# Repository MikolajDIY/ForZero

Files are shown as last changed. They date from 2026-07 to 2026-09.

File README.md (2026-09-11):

# ForZero

Sterownik fizycznego zestawu wskaźników Audi A4 B6, pozwalający wyświetlać telemetrię z Forza Horizon 6 przy użyciu STM32, CAN, USB i autorskiej aplikacji Qt.

ForZero powstał jako próba wykorzystania fizycznego zestawu wskaźników jako elementu stanowiska simracingowego. Projekt obejmuje rozpoznanie sposobów sterowania licznikiem, zaprojektowanie i uruchomienie własnej PCB, firmware mikrokontrolera oraz aplikację komputerową.

## Film prezentujący projekt

ForZero – prezentacja projektu (https://www.youtube.com/watch?v=puXx0WQHfvw)

[Obejrzyj film na YouTube](https://www.youtube.com/watch?v=puXx0WQHfvw)

## Możliwości

- Wyświetlanie prędkości i obrotów silnika na fizycznym liczniku.
- Sterowanie wskazaniami poziomu paliwa i temperatury płynu chłodzącego.
- Obsługa wybranych kontrolek i komunikatów ostrzegawczych.
- Przybliżona symulacja stanów ABS, TCS i AIRBAG oraz temperatury płynu chłodzącego na podstawie dostępnej telemetrii.
- Odbiór danych UDP z gry i przesyłanie przetworzonych wartości do sterownika przez USB VCP.
- Pomiar opóźnień komunikacji na podstawie potwierdzeń wykonania ramek.
- Zerowanie prędkości i obrotów po 500 ms bez poprawnej ramki danych.

Gra nie udostępnia bezpośrednio wszystkich odwzorowywanych stanów. Algorytmy symulacji kontrolek i temperatury służą do przybliżonego odtworzenia ich zachowania; nie są modelami fizycznymi układów pojazdu.

## Jak to działa

Gra wysyła telemetrię przez UDP. Aplikacja Qt odbiera i parsuje pakiety, wykonuje dodatkową logikę oraz przesyła dane przez USB VCP do STM32F105. Mikrokontroler generuje sygnały elektryczne wymagane przez zestaw wskaźników.

Badany licznik wykorzystuje kilka różnych sposobów sterowania:

| Funkcja | Sposób sterowania |
| --- | --- |
| Obrotomierz | Ramki CAN |
| Prędkościomierz | Sygnał impulsowy o regulowanej częstotliwości |
| Poziom paliwa i temperatura | Emulacja rezystancji czujników |
| Wybrane kontrolki i ostrzeżenia | Sygnały logiczne 12 V |

Wskazania paliwa i temperatury skalibrowano eksperymentalnie. Zmierzone charakterystyki opracowano z wykorzystaniem interpolacji PCHIP w MATLAB-ie.

## Sprzęt

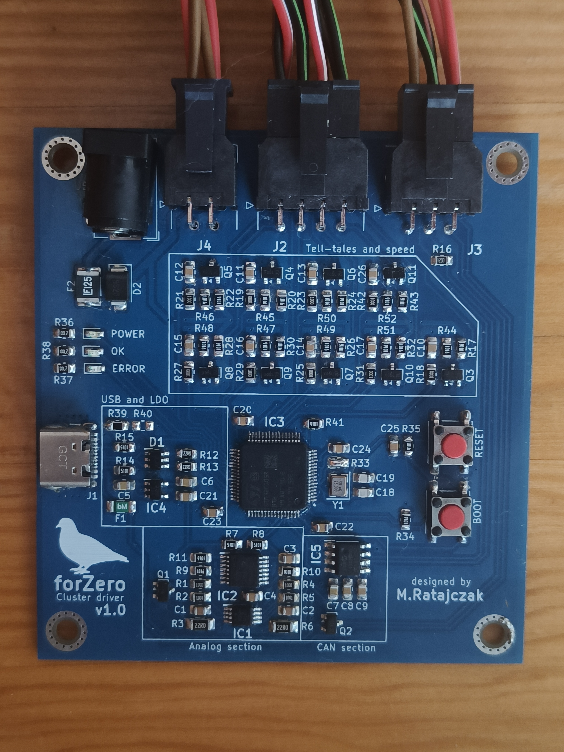
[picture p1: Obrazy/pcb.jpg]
Płytka sterownika ForZero


- Autorska dwuwarstwowa PCB zaprojektowana w KiCad.
- Mikrokontroler STM32F105 z jednoczesną obsługą USB i CAN.
- Transceiver CAN MCP2562 z osobnym zasilaniem interfejsu logicznego.
- Układy emulacji rezystancji oparte na potencjometrze cyfrowym MCP4661, wzmacniaczach operacyjnych i tranzystorach MOSFET.
- Tranzystorowe stopnie sterujące wejściami 12 V licznika.
- Złącze USB-C, zewnętrzne zasilanie 12 V i złącza Molex Micro-Fit 3.0.
- Zabezpieczenie ESD linii USB oraz bezpieczniki polimerowe na liniach zasilania.

## Oprogramowanie

### Aplikacja PC — C++ / Qt

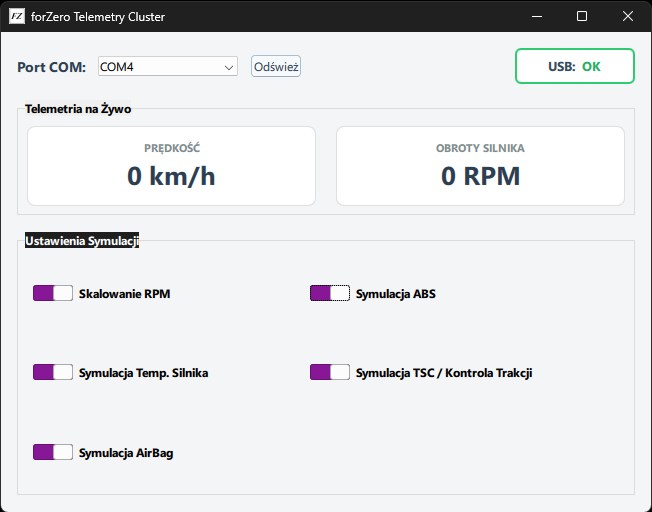
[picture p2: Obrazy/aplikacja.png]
Interfejs aplikacji ForZero


Aplikacja ma trzy wątki: GUI, odbiór UDP oraz komunikację USB. Oddzielenie komunikacji od interfejsu użytkownika pozwala odbierać telemetrię i obsługiwać sterownik bez wykonywania tych operacji w wątku GUI.

Aplikacja odpowiada za parsowanie telemetrii, symulację wybranych wskazań, przygotowanie ramek dla sterownika i wyznaczanie statystyk opóźnień.

### Firmware — C / STM32 HAL

Firmware powstał w STM32CubeIDE z wykorzystaniem bibliotek HAL. Zadania w pętli głównej są wyzwalane zdarzeniowo lub w ustalonych interwałach:

| Sygnał | Aktualizacja |
| --- | --- |
| Prędkość i kontrolki | Po otrzymaniu nowych danych, gdy wartość się zmieni |
| Obroty silnika | Ramka CAN co 20 ms |
| Temperatura | Co 2 s |
| Poziom paliwa | Co 5 s, jeżeli odebrano nowe dane |

Własny protokół przesyłany przez USB VCP wykorzystuje znaczniki ramki, CRC8, numer sekwencyjny i potwierdzenie wykonania `Exec Ack`. Parser posiada timeout odbioru, a brak poprawnych danych przez 500 ms powoduje wyzerowanie prędkości i obrotów.

## Opóźnienia

Aplikacja mierzy czas przejścia danych w pętli PC–sterownik–PC (RTT), wykorzystując numery ramek i odpowiadające im potwierdzenia. Statystyki obejmują ostatnie 20 000 pomiarów.

W zestawach pomiarowych opisanych w dokumentacji średnie RTT zazwyczaj wynosiło poniżej 1 ms, a P99 poniżej 4 ms. W najbardziej skrajnym zarejestrowanym zestawie P99 osiągnął 17 ms. Są to wyniki przeprowadzonych testów, a nie gwarantowane limity czasowe.

**RTT nie jest pomiarem czasu od zdarzenia w grze do mechanicznego wychylenia wskazówki.** Poszczególne wyjścia mają własne okresy odświeżania, a licznik dodatkowo filtruje wskazania. Projekt pracuje jako system soft real-time.

## Zawartość repozytorium

| Folder | Zawartość |
| --- | --- |
| [Aplikacja Qt](Aplikacja%20Qt/) | Kod źródłowy aplikacji komputerowej |
| [Oprogramowanie sterownika](Oprogramowanie%20sterownika/) | Projekt firmware mikrokontrolera STM32 |
| [Schematy](Schematy/) | Materiały dotyczące części sprzętowej |
| [Obrazy](Obrazy/) | Zdjęcia i grafiki wykorzystywane w README |
| [Dokumentacja](ForZero_dokumentacja_v1.pdf) | Szczegółowa dokumentacja projektu |

## Uruchomienie

### Wymagania

- Zestaw wskaźników zgodny z egzemplarzem wykorzystanym w projekcie.
- Zmontowany sterownik ForZero, przewody połączeniowe i zasilanie 12 V.
- Przewód USB obsługujący transmisję danych.
- Komputer z aplikacją ForZero oraz Forza Horizon 6.
- Do samodzielnego zbudowania oprogramowania: środowisko Qt z kompilatorem C++ oraz STM32CubeIDE.

### Kolejność czynności

1. Przy odłączonym zasilaniu połącz sterownik z licznikiem zgodnie ze schematem połączeń w dokumentacji. Uwzględnij numerację pinów obu złączy licznika.
2. Zbuduj firmware z folderu [Oprogramowanie sterownika](Oprogramowanie%20sterownika/) i wgraj go do STM32. Programowanie jest możliwe przez USB z wykorzystaniem wbudowanego bootloadera.
3. Aby wejść w tryb bootloadera: naciśnij RESET, przytrzymując go naciśnij BOOT, zwolnij RESET, a następnie BOOT.
4. Po zaprogramowaniu uruchom sterownik w zwykłym trybie pracy i podłącz zasilanie zestawu.
5. Zbuduj i uruchom aplikację z folderu [Aplikacja Qt](Aplikacja%20Qt/), a następnie wybierz port COM sterownika.
6. Włącz wysyłanie telemetrii UDP w grze. Ustaw adres IP komputera odbierającego dane oraz port zgodny z konfiguracją aplikacji.
7. Uruchom jazdę i sprawdź odbiór danych oraz działanie wskazań.

<!-- Do uzupełnienia przed publikacją: sprawdzone wersje Qt i kompilatora, wymagane moduły Qt, dokładna procedura budowania, narzędzie do wgrywania przez USB oraz ustawienia telemetrii (IP, port i format pakietu). -->

## Zgodność i ograniczenia

- Projekt sprawdzono z licznikiem **Audi A4 B6 RB4 o oznaczeniu 8E0920900H**, z monochromatycznym wyświetlaczem FIS. Zgodność z innymi wersjami licznika nie została potwierdzona.
- W badanym egzemplarzu po rozpoczęciu jazdy wskazanie paliwa zmieniało się wyłącznie w dół, z tempem około jednej czwartej skali w ciągu 7–10 minut. Ograniczenie to utrudnia szybkie odwzorowanie zmian poziomu paliwa w grze.
- Kontrolki i komunikaty mają zachowanie wynikające z wewnętrznej logiki licznika. Symulacja ABS nie oznacza pełnej emulacji sterownika ABS ani niezależnego sterowania samą lampką ABS.
- Poziom 12 V dla wybranych wejść kontrolek przyjęto na podstawie testów używanego egzemplarza; nie potwierdzono go dokumentacją producenta.

## Dokumentacja

Dokumentacja projektu opisuje pinout licznika, schemat połączeń ze sterownikiem, układy elektroniczne, kalibrację wskazań, protokół USB oraz przeprowadzone testy.

<!-- Do uzupełnienia: dodaj względny link do PDF-u po ustaleniu jego nazwy i lokalizacji w repozytorium. -->

## Autor

M.Ratajczak — [MikolajDIY](https://github.com/MikolajDIY)

<!-- Przed publikacją określ zasady licencjonowania własnego kodu i projektu sprzętu. Zachowaj informacje licencyjne zależności i kodu generowanego. Dodaj odnośniki do wykorzystanych materiałów zewnętrznych. -->

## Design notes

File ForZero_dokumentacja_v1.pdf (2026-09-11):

Projekt systemu “ForZero”

## “ForZero” – Projekt sterownika dla licznika samochodowego wraz z dedykowaną aplikacją umożliwiającą wyświetlanie telemetrii w trybie Soft Real-Time

Mikołaj Ratajczak

7 września 2026

### Spis treści

1 Wstęp | 2
2 Schemat blokowy projektu | 2
3 Inżynieria wsteczna licznika | 2
4 Projekt sterownika licznika | 7
5 Dedykowana aplikacja w środowisku Qt | 14
6 Program mikrokontrolera | 15
7 Testy oraz zabezpieczenia | 18

### 1 Wstęp

Celem projektu było stworzenie systemu wbudowanego zdolnego do obsługi wybranych funkcji licznika samochodowego. Jako bazę projektu wybrano zestaw wskaźników z pojazdu Audi A4 B6 o oznaczeniu 8E0920900H RB4, wyposażony w monochromatyczny wyświetlacz FIS. Na obudowie licznika znajduje się oznaczenie daty 05/03/02, co sugeruje, że pochodzi on z marca 2002 roku i należy do początkowego okresu produkcji tego modelu.
Architektura późniejszych rewizji liczników może się różnić, a co za tym idzie – również sposób ich obsługi. Ze względu na te różnice nie jestem w stanie jednoznacznie stwierdzić, czy przygotowana warstwa sprzętowa i programowa będzie w pełni kompatybilna z zestawami wskaźników o innych oznaczeniach.
Ważnym założeniem projektowym było zminimalizowanie kosztu materiałowego urządzenia (BOM) przy zachowaniu założonej funkcjonalności. Przełożyło się to bezpośrednio na decyzje układowe, takie jak zastąpienie droższych scalonych konwerterów poziomów logicznych dyskretnymi układami tranzystorowymi oraz wybór mikrokontrolera wyposażonego w wymagane peryferia.
Pliki produkcyjne, lista i kosztorys komponentów, oprogramowanie sterownika oraz autorska aplikacja Qt zostały udostępnione w repozytorium projektu na platformie GitHub: https://github.com/MikolajDIY/ForZero.

### 2 Schemat blokowy projektu

Etap projektowania rozpoczęto od zdefiniowania przepływu informacji między poszczególnymi blokami funkcjonalnymi. Jako źródło danych wykorzystano grę wyścigową Forza Horizon 6, która wysyła pakiety telemetryczne za pośrednictwem protokołu UDP. Częstotliwość ich generowania zależy od ustawionego w grze limitu liczby klatek na sekundę.
Pakiety UDP są odbierane przez autorską aplikację utworzoną w środowisku Qt Creator Community 18.0.2. Odbywa się w niej parsowanie danych telemetrycznych oraz symulacja i emulacja wybranych funkcji licznika. Przetworzone dane są następnie przesyłane przez interfejs USB VCP do sterownika, który generuje odpowiednie sygnały elektryczne wymagane przez zestaw wskaźników.

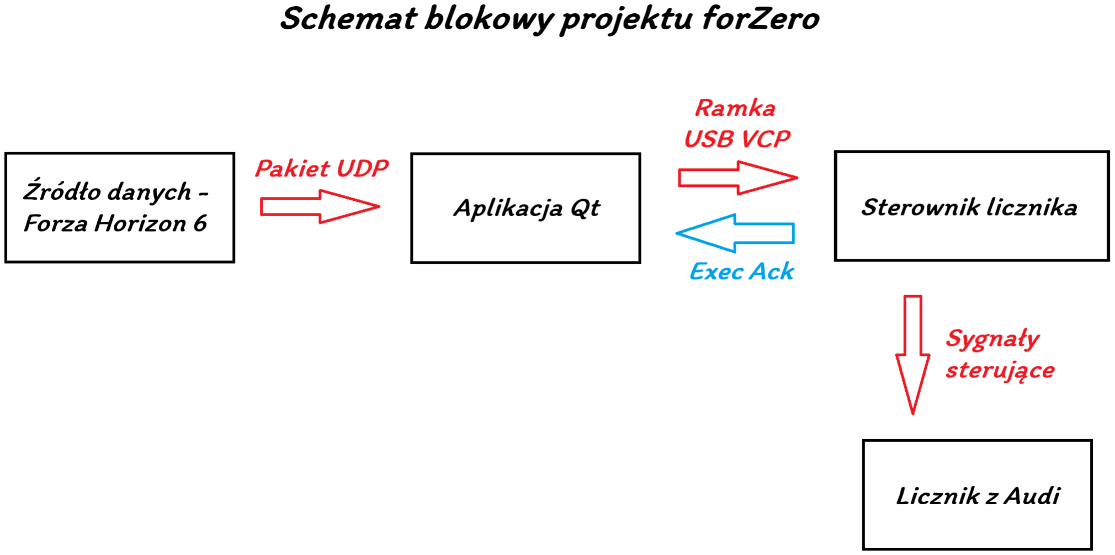
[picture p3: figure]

Rysunek 1: Schemat blokowy systemu ForZero

### 3 Inżynieria wsteczna licznika

### 3.1 Pinout licznika Audi A4 B6 RB4

Po zdefiniowaniu zakresu projektu przystąpiono do procesu “rozpracowywania licznika”. Dużą pomocą było forum AudiTeam.pl, na którym znalazłem pełny opis wyprowadzeń licznika Audi A4 B6. Znajdowała się tam również informacja, że zestawy wskaźników z modeli B6 i B7 mają taki sam pinout. Nie udało mi się jednak niezależnie zweryfikować tej informacji.

W pierwszej kolejności należało prawidłowo zasilić licznik oraz znaleźć sposób sterowania wskazaniami prędkości, obrotów silnika, temperatury płynu chłodzącego i poziomu paliwa. Kolejnym krokiem było zidentyfikowanie sygnałów odpowiedzialnych za czerwone i żółte komunikaty ostrzegawcze oraz znalezienie sposobu ich wygaszania.

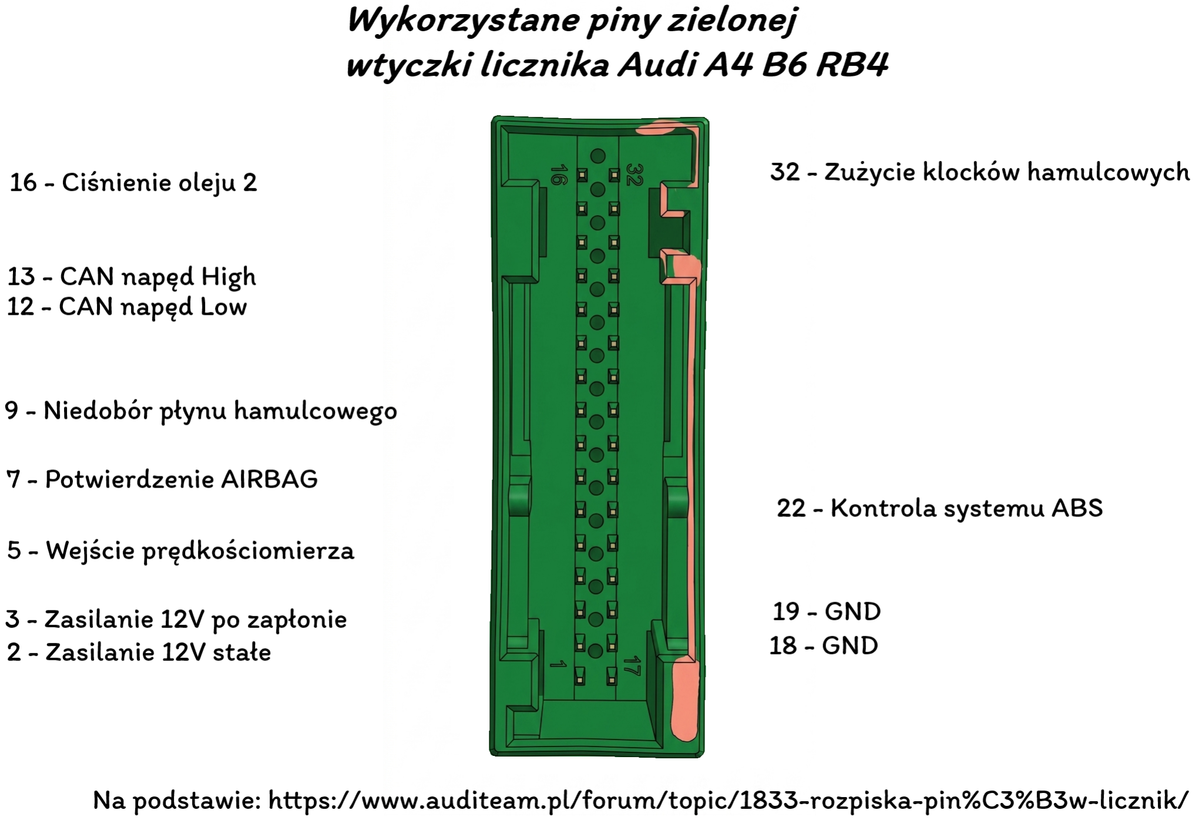
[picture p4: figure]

Rysunek 2: Wykorzystane wyprowadzenia zielonego złącza zestawu wskaźników

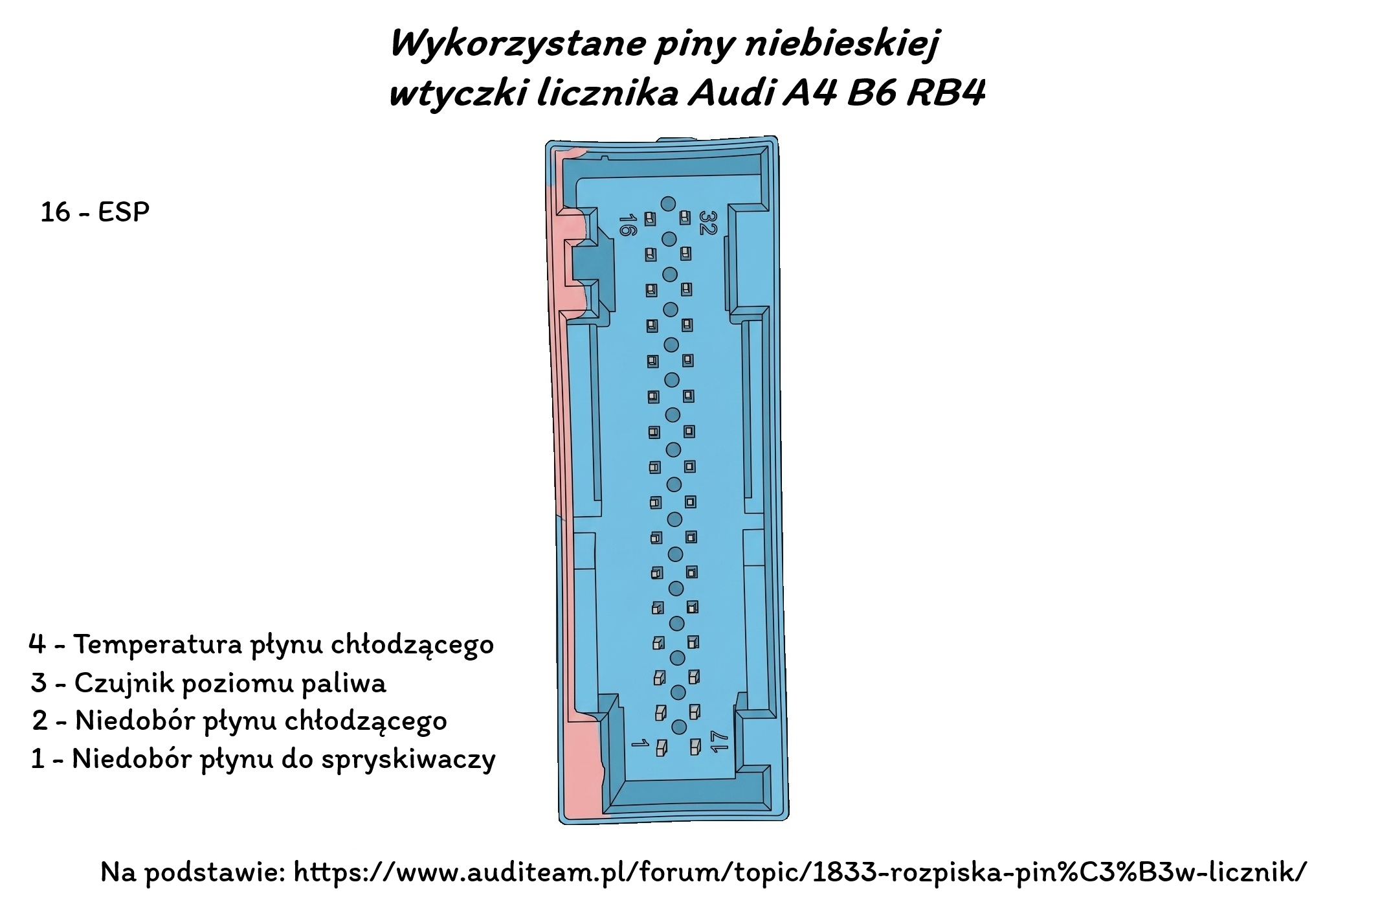
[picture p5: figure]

Rysunek 3: Wykorzystane wyprowadzenia niebieskiego złącza zestawu wskaźników

Na rysunkach 2 i 3 przedstawiono wyprowadzenia wykorzystane w projekcie. Oprócz sygnałów odpowiedzialnych za sterowanie wskazaniami i wygaszanie komunikatów ostrzegawczych znalazły się wśród nich również wejścia związane z układami ABS oraz ESP. W dalszej części projektu funkcja kontroli trakcji jest opisywana jako TCS. Wybrane źródło danych telemetrycznych nie udostępnia bezpośrednich informacji o interwencji ABS i TCS, ale dostarcza dane dotyczące wciśnięcia hamulca, gazu oraz poślizgu każdego z czterech kół. Na ich podstawie można w przybliżeniu określić moment interwencji tych układów.

### 3.2 Sterowanie kontrolkami

Nie udało się znaleźć dokumentacji producenta określającej poziomy napięć dla wejść odpowiadających za wybrane kontrolki i komunikaty ostrzegawcze badanego licznika. W przeprowadzonych testach licznik pracował stabilnie przy sterowaniu tych wejść napięciem 12 V, dlatego wartość tę przyjęto jako roboczy poziom logiczny. Jest to założenie zweryfikowane eksperymentalnie dla używanego egzemplarza, a nie wartość potwierdzona dokumentacją producenta.

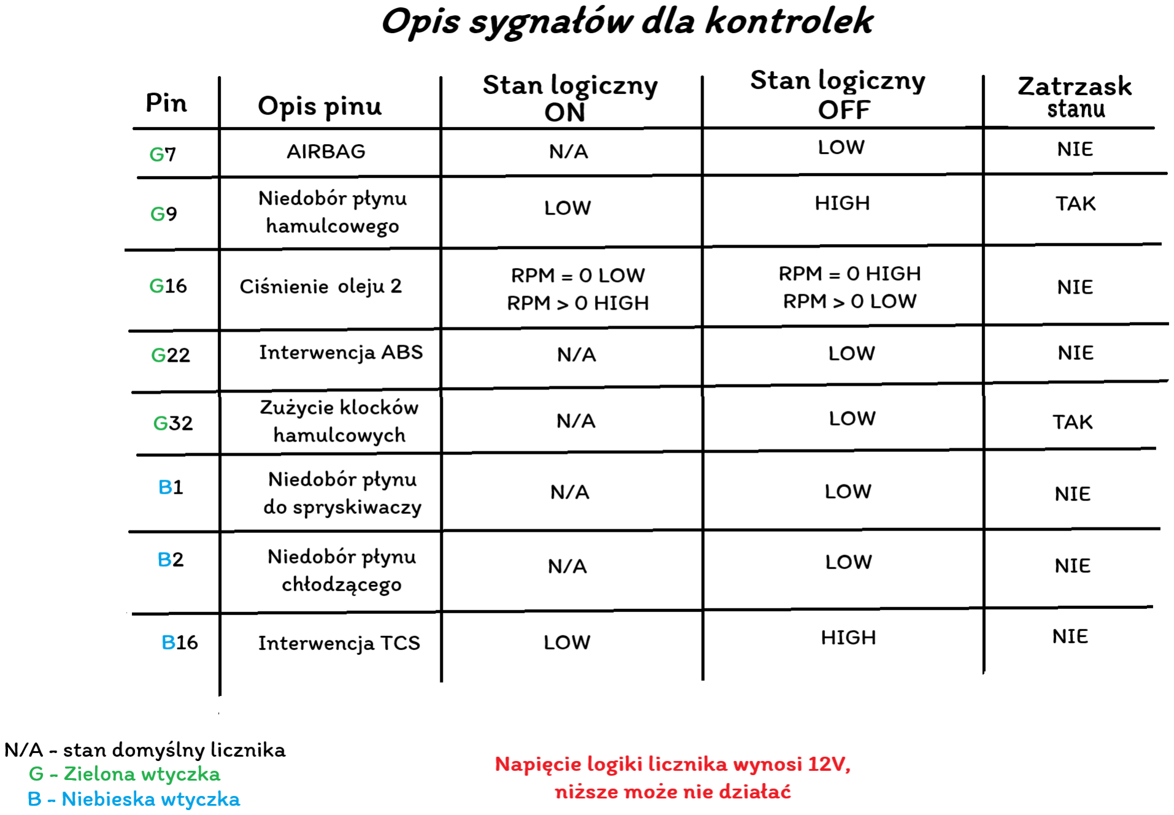
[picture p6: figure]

Rysunek 4: Sposób sterowania wybranymi kontrolkami i komunikatami ostrzegawczymi

Wybrane wejścia licznika posiadają zatrzask stanu. W przypadku ostrzeżenia o niskim poziomie płynu hamulcowego możliwe jest jego włączanie i wyłączanie podczas pracy licznika. Inaczej zachowuje się ostrzeżenie o zużyciu klocków hamulcowych. Jego wygaszenie wymaga podania odpowiedniego stanu na pin G32 bezpośrednio po podłączeniu licznika do zasilania.

### 3.3 Sterowanie wskazówkami

Badany zestaw wskaźników można określić jako konstrukcję przejściową, ponieważ wykorzystuje jednocześnie magistralę CAN oraz bezpośrednie sygnały cyfrowe i analogowe. Dobrym przykładem jest sposób sterowania poszczególnymi wskazówkami.

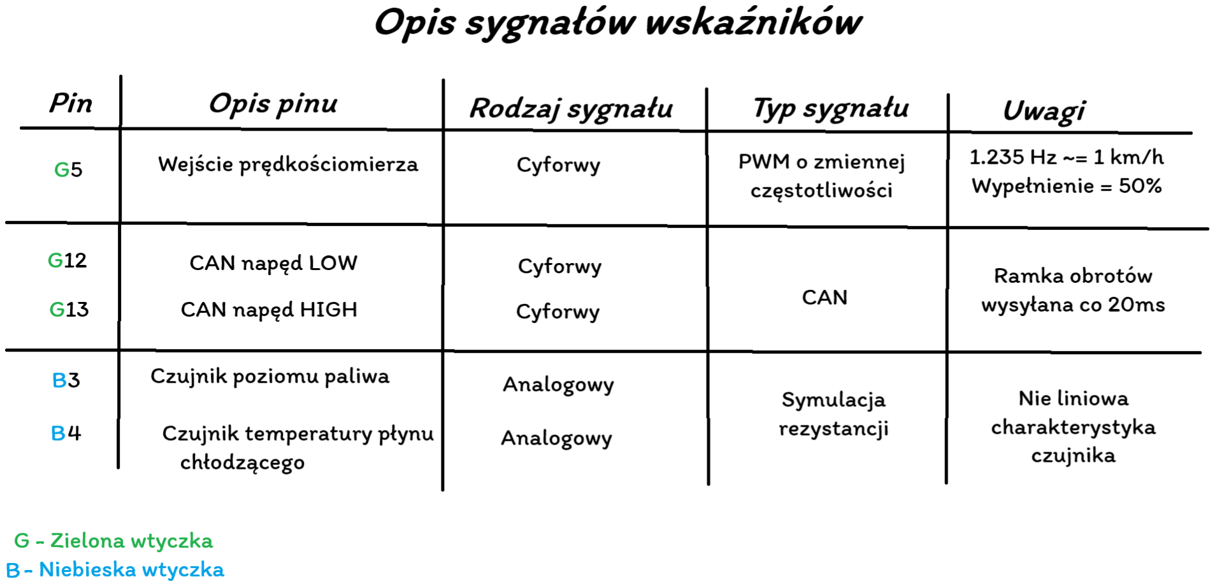
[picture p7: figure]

Rysunek 5: Sposób sterowania poszczególnymi wskazaniami zestawu wskaźników

Wskazania poziomu paliwa oraz temperatury płynu chłodzącego zależą od rezystancji czujników podłączonych do odpowiednich wejść licznika. Prędkościomierz jest sterowany za pomocą sygnału impulsowego – wartość wskazania zależy od częstotliwości generowanych impulsów. Obrotomierz jest natomiast sterowany cyfrowo za pośrednictwem magistrali CAN. Częściową strukturę wykorzystywanej ramki przedstawiono na rysunku 6.

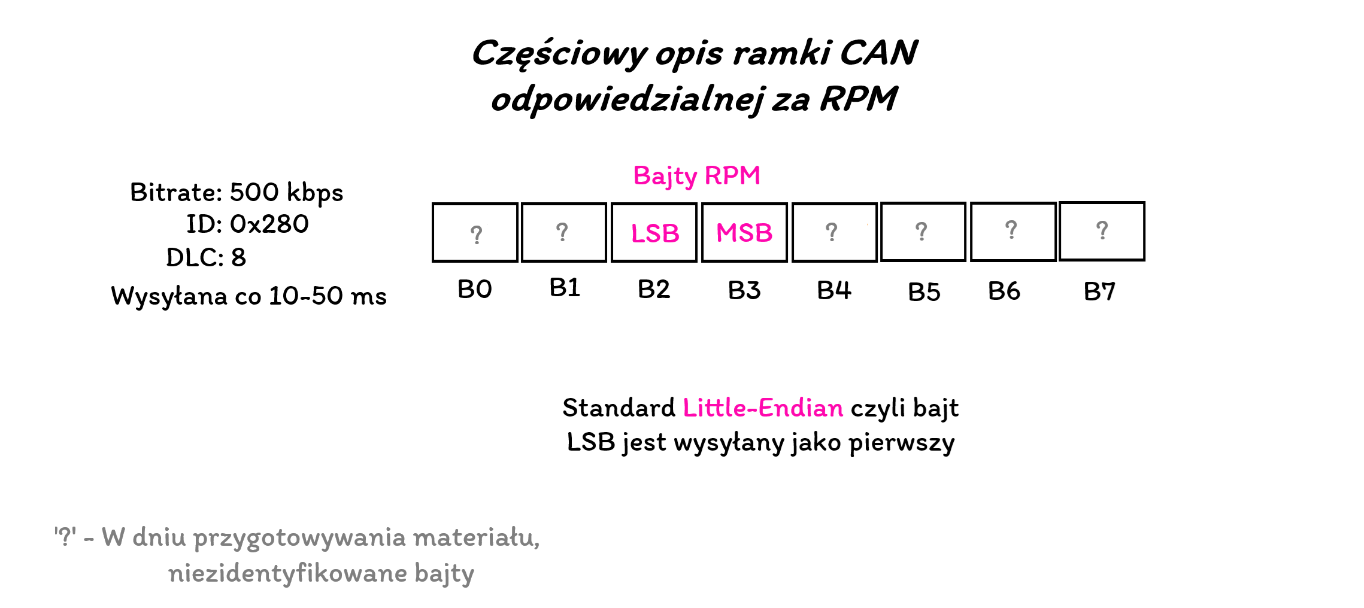
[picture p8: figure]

Rysunek 6: Częściowa struktura ramki CAN wykorzystywanej do sterowania obrotomierzem

### 3.4 Charakterystyki nieliniowych wskaźników

Charakterystyka zależności rezystancji czujnika od wskazywanej wielkości nie musi być liniowa. Dodatkowo na zachowanie wskazówek wpływają wewnętrzne mechanizmy filtracji zastosowane w liczniku. Ich dokładnego sposobu realizacji nie udało się określić.
W przypadku wskaźnika poziomu paliwa filtracja ogranicza szybkie zmiany wskazania, które w samochodzie mogłyby być powodowane przemieszczaniem się paliwa w zbiorniku podczas przyspieszania, hamowania lub pokonywania zakrętów.
Wskaźnik temperatury płynu chłodzącego również nie odwzorowuje zmian w sposób liniowy. W badanym egzemplarzu dla temperatur z przedziału około 80◦C–100◦C wskazówka utrzymywała się w pobliżu 90◦C. Takie zachowanie ogranicza widoczne wahania wskazania w typowym zakresie temperatury pracy silnika.

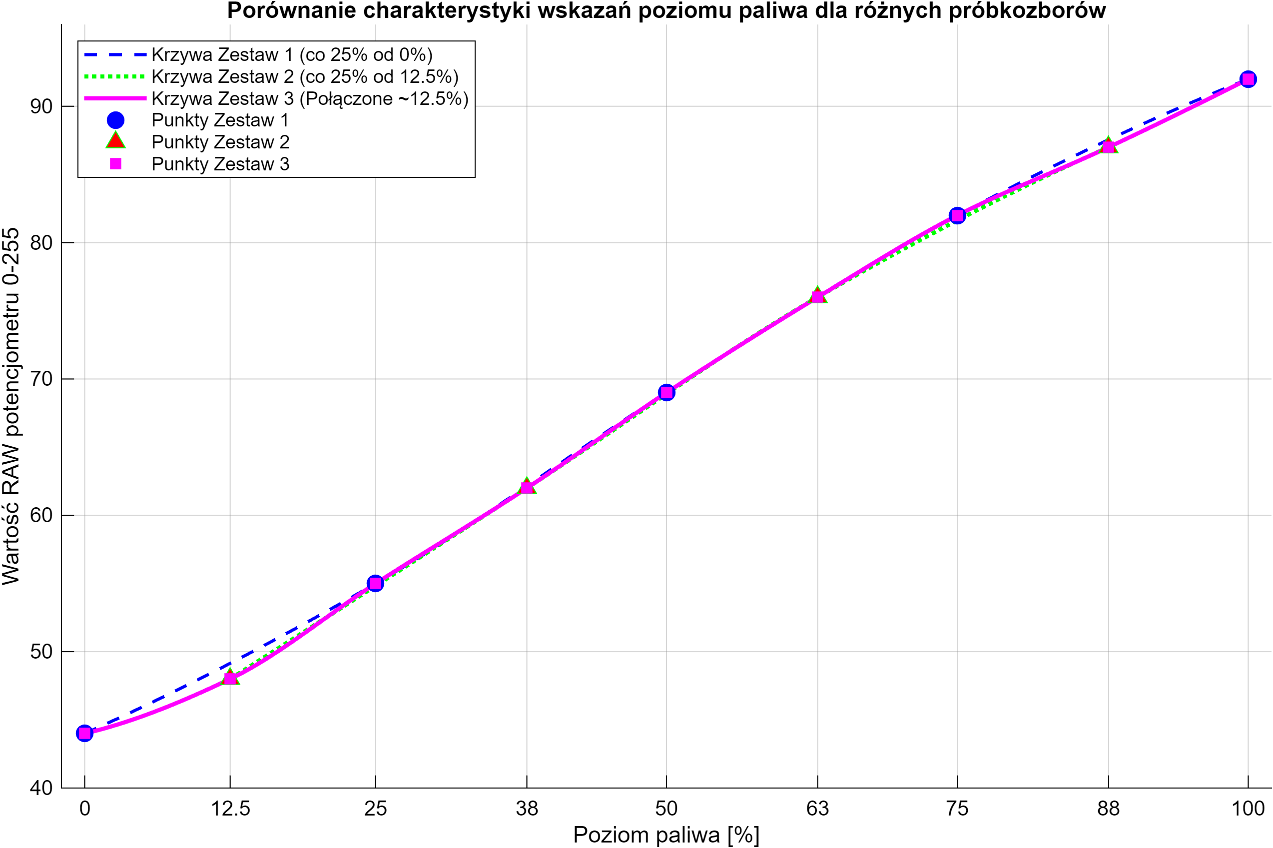
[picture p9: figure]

Rysunek 7: Zmierzona charakterystyka wskazania poziomu paliwa

Na rysunku 7 przedstawiono zmierzoną charakterystykę procentowego wskazania poziomu paliwa w zależności od wartości zadanej potencjometru cyfrowego. Wartości tej nie można bezpośrednio przełożyć na rezystancję widzianą przez licznik ze względu na sposób działania zastosowanego układu emulacji rezystancji. Szczegółowy opis układu znajduje się w sekcji 4.3.
Na wykresie przedstawiono trzy krzywe uzyskane dla różnych zestawów punktów pomiarowych. W kodzie wykorzystano zestaw nr 3, a pozostałe posłużyły do sprawdzenia wpływu doboru punktów pomiarowych na wynik interpolacji. Do interpolacji wykorzystano funkcję PCHIP w środowisku MATLAB. Metoda ta lepiej odwzorowywała zmierzoną charakterystykę niż interpolacja wielomianowa używana na wcześniejszym etapie projektu.

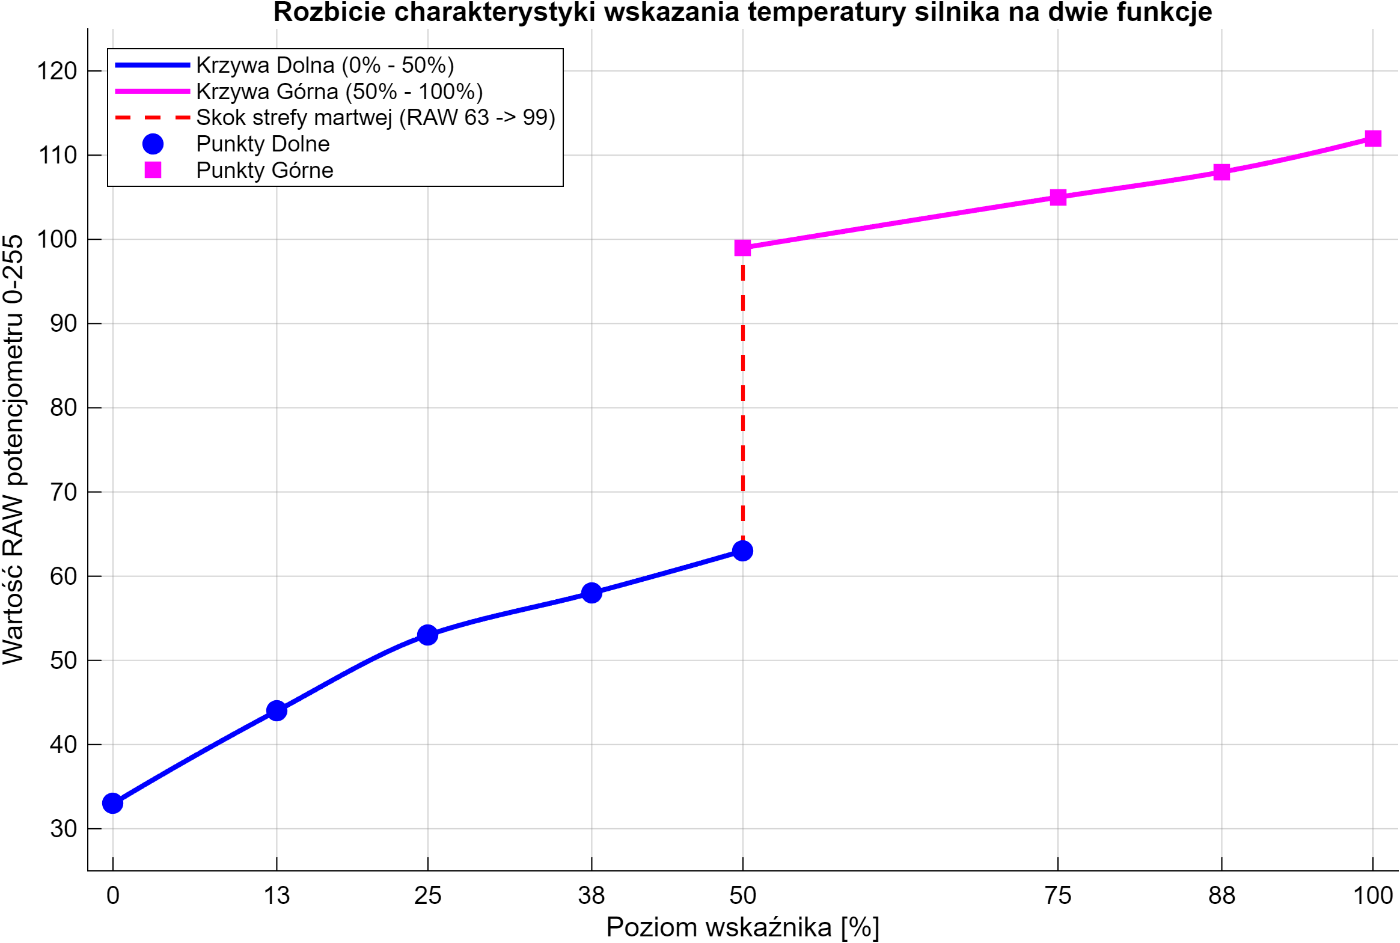
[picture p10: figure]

Rysunek 8: Zmierzona charakterystyka wskazania temperatury płynu chłodzącego

Na rysunku 8 przedstawiono charakterystykę procentowego wskazania temperatury płynu chłodzącego w zależności od wartości zadanej potencjometru cyfrowego. Temperaturze 50◦C przypisano wskazanie 0%, natomiast 130◦C odpowiada wskazaniu 100%. Do interpolacji charakterystyki również wykorzystano funkcję PCHIP w środowisku MATLAB.
Należy jednak wspomnieć o istotnym ograniczeniu dotyczącym wskazania poziomu paliwa. Po uruchomieniu licznika i osiągnięciu prędkości większej od zera zmiana wskazania była możliwa wyłącznie w dół, z tempem około jednej czwartej skali w ciągu 7–10 minut. Nie udało się jednoznacznie ustalić przyczyny ani znaleźć sposobu obejścia tego zachowania.

### 4 Projekt sterownika licznika

### 4.1 Schemat blokowy i założenia

Podstawą projektowania sterownika było określenie sygnałów wejściowych oraz wymaganych sygnałów wyjściowych. Sposób sterowania poszczególnymi funkcjami zestawu wskaźników opisano w sekcjach 3.2 oraz 3.3.
Do komunikacji pomiędzy aplikacją PC a sterownikiem wykorzystano interfejs USB VCP (Virtual COM Port). Pozwala on korzystać z USB jak z wirtualnego portu szeregowego, co upraszcza implementację własnego protokołu warstwy aplikacyjnej. Jednocześnie transmisja korzysta z mechanizmów USB odpowiedzialnych za kontrolę integralności danych i retransmisję pakietów w przypadku wykrycia błędu na magistrali.
Na rysunku 9 przedstawiono schemat blokowy sterownika. Odbiera on ramkę danych z aplikacji PC i przetwarza zawarte w niej informacje na sygnały zrozumiałe dla licznika. Założono pracę w trybie miękkiego czasu rzeczywistego (Soft Real-Time). Układ nie jest systemem czasu rzeczywistego z twardymi gwarancjami czasowymi, jednak uzyskiwane opóźnienia są wystarczająco małe dla tego zastosowania. Sposób i wyniki pomiarów opisano w sekcji 7.2.

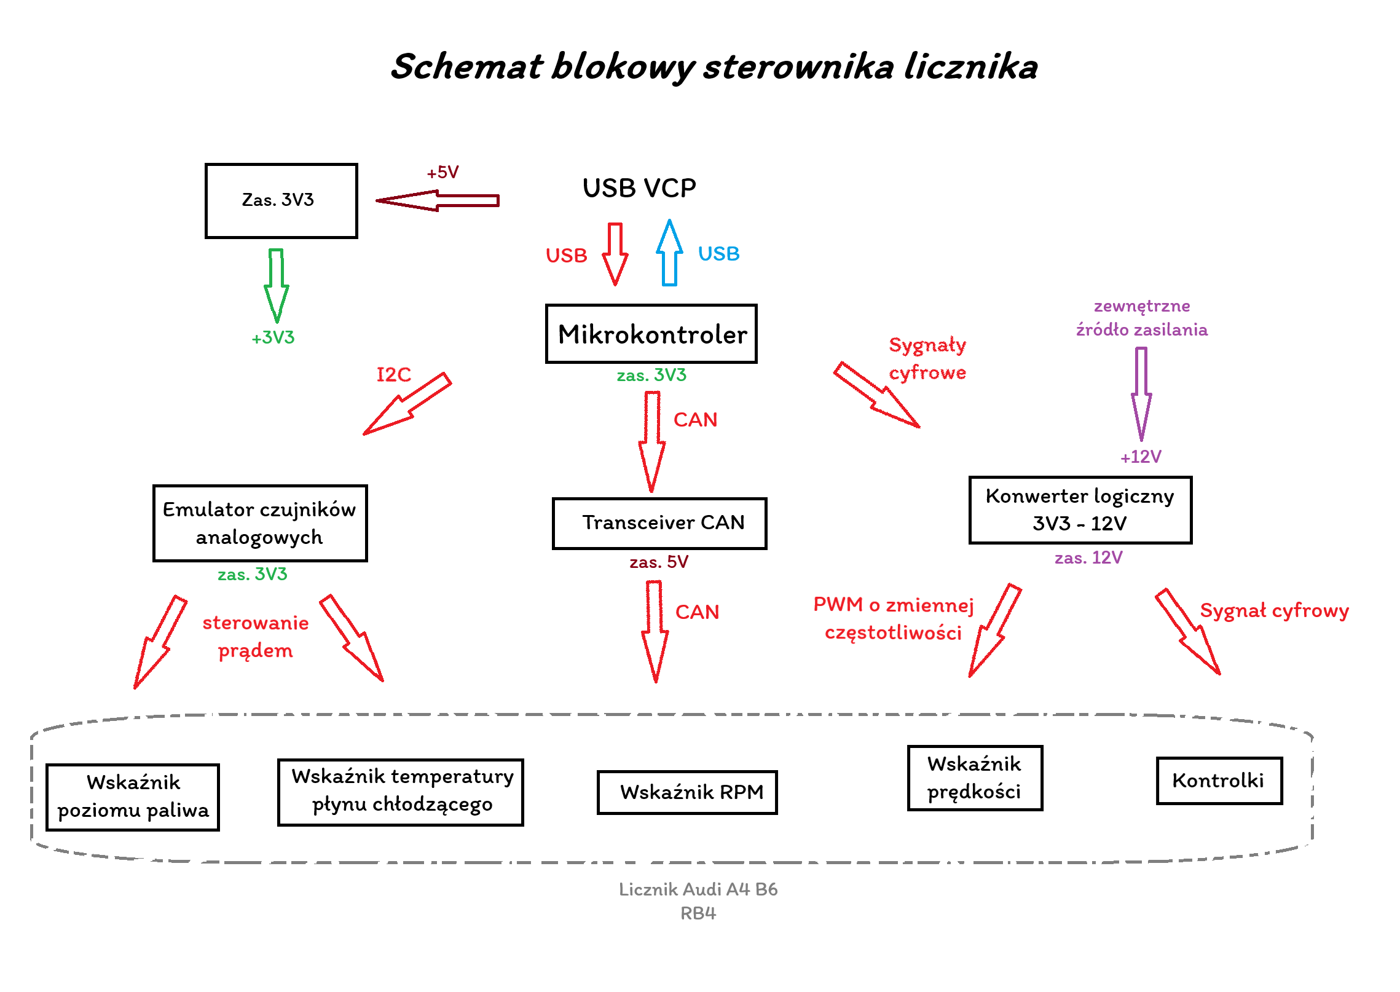
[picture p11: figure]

Rysunek 9: Schemat blokowy sterownika zestawu wskaźników

### 4.2 Wybór mikrokontrolera

Wybór mikrokontrolera był jednym z ważniejszych kroków projektu. Na podstawie schematu blokowego określono, że układ powinien posiadać:
1. sprzętową obsługę magistrali CAN zgodnej ze standardem CAN 2.0A,
2. co najmniej 20 dostępnych wyprowadzeń GPIO,
3. sprzętową obsługę USB Full-Speed,
4. sprzętową obsługę magistrali I2C,
5. możliwie niski koszt jednostkowy.

Popularne platformy, takie jak Arduino Uno czy Raspberry Pi Pico, nie spełniały tych wymagań bez zastosowania dodatkowych układów peryferyjnych. Ostatecznie wybrano rodzinę STM32, głównie ze względu na szeroki wybór układów z różnymi kombinacjami peryferiów.
Do realizacji projektu wykorzystano mikrokontroler STM32F105. Posiada on wymagane interfejsy sprzętowe i umożliwia jednoczesne wykorzystanie USB OTG FS oraz CAN. W tym zastosowaniu nie jest jednak wykluczone użycie innego mikrokontrolera o podobnym zestawie peryferiów.
W trakcie przygotowywania dokumentacji zwróciłem również uwagę na mikrokontroler STM32C562, który w sprawdzanym źródle zakupu był około trzykrotnie tańszy od zastosowanego STM32F105. Dla obecnej wersji projektu byłby korzystniejszy pod względem kosztu, ale umożliwia obsługę tylko jednej magistrali CAN. Ograniczałoby to możliwość późniejszego rozszerzenia sterownika, np. o dodatkową magistralę CAN Komfort.

### 4.3 Symulacja rezystancji

Po znalezieniu informacji o rezystancyjnym sposobie sterowania wskazaniem poziomu paliwa oraz temperatury płynu chłodzącego należało określić, jaki zakres rezystancji jest wykorzystywany przez wejścia licznika.
Pomiary rozpoczęto od zmierzenia napięcia pomiędzy wejściami odpowiedzialnymi za poziom paliwa i temperaturę płynu chłodzącego a masą. Uzyskano około 3,5 V. Następnie przeprowadzono próby z rezystorami od 10 kΩ do 47 Ω. Dla około 470 Ω wskazówki znajdowały się na początku skali, dla 100 Ω w jej środkowej części, natomiast przy 47 Ω osiągały pełne wychylenie. Dokładne zakresy rezystancji różnią się w zależności od wskazówki, ale zaprojektowny układ w pełni pokrywa oba zakresy. Pozwoliło to zastosować dla obu wejść dwa bliźniacze układy.
Wymóg symulacji tak niskiej rezystancji nie był dobrą wiadomością, ponieważ wykluczał bezpośrednie zastosowanie typowego potencjometru cyfrowego z dwóch powodów:
1. Niewystarczająca rozdzielczość w wymaganym zakresie. Dla potencjometru 10 kΩ o rozdzielczości 8-bitowej zakres odpowiadający kilkudziesięciu omom obejmowałby zaledwie kilka kroków regulacji.
2. Zbyt duży wymagany prąd. Dopuszczalny prąd wielu potencjometrów cyfrowych jest znacznie mniejszy od wartości wynikającej z prostego obliczenia dla 47 Ω. Przy zmierzonym napięciu około 3,5 V otrzymujemy:

I =

U
R

=

3,5 V
47 Ω

≈ 0,0744 A = 74,4 mA.

Jest to wartość orientacyjna, ponieważ rzeczywisty prąd zależy również od wewnętrznej charakterystyki wejścia licznika. Pokazuje jednak, że bezpośrednie użycie potencjometru cyfrowego nie byłoby właściwym rozwiązaniem.

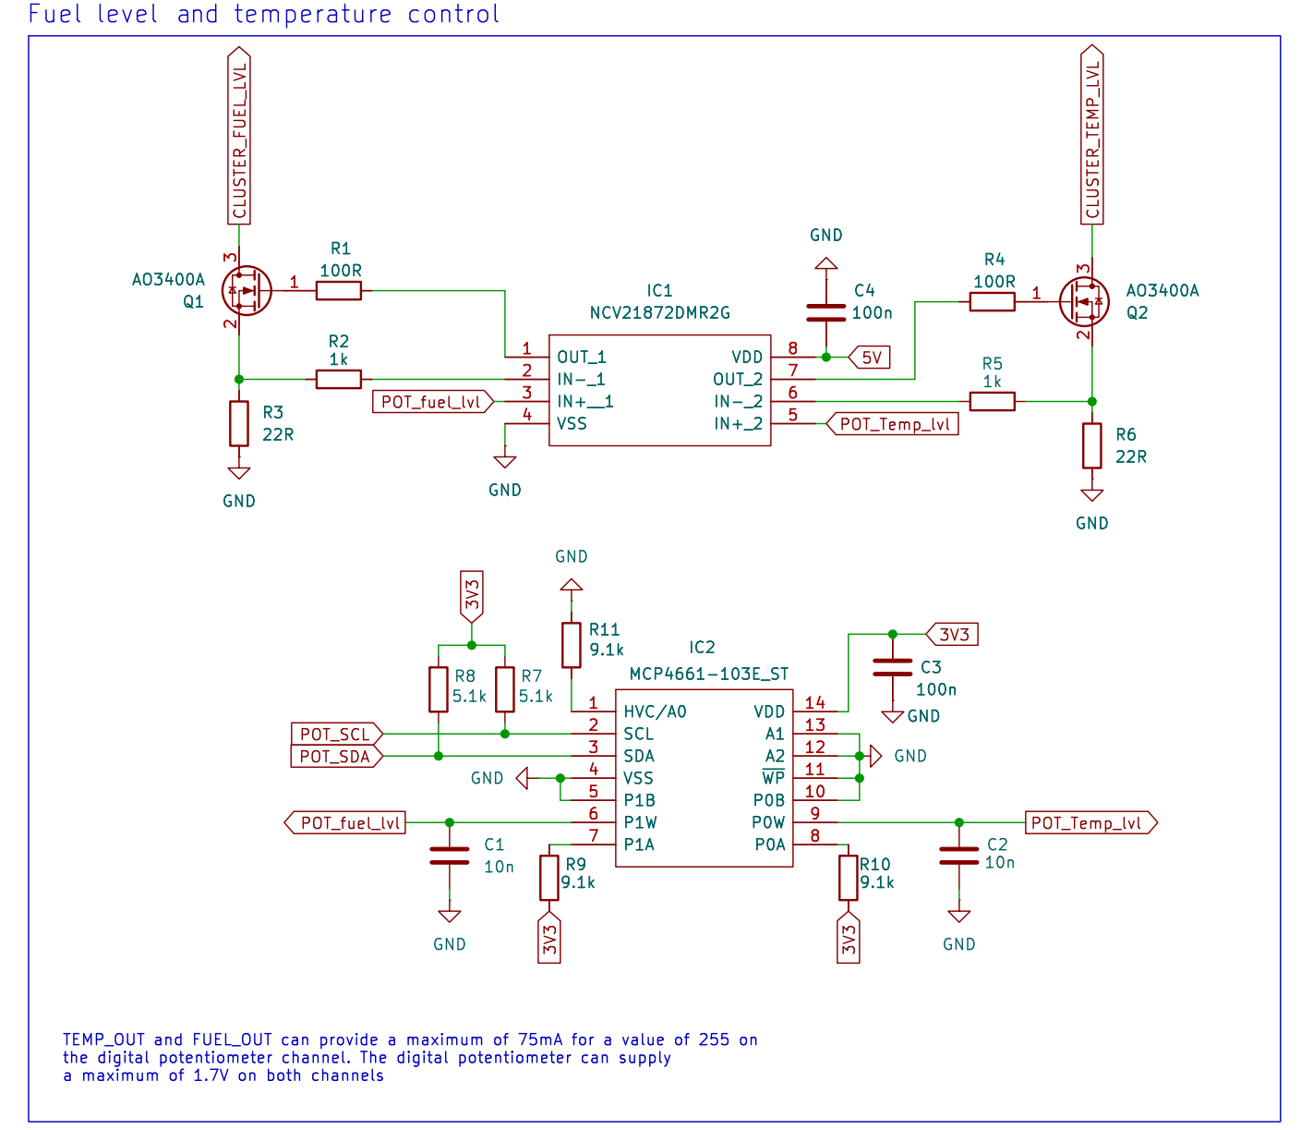
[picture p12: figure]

Rysunek 10: Schemat układu emulacji rezystancji

Jako element wykonawczy zastosowano tranzystor N-MOSFET typu Logic-Level AO3400A, którego bramka jest sterowana przez wzmacniacz operacyjny pracujący w pętli sprzężenia zwrotnego. Zastosowany wzmacniacz umożliwia pracę blisko obu szyn zasilania (Rail-to-Rail) oraz charakteryzuje się małym dryftem napięcia niezrównoważenia (Zero-Drift). Rezystory R3 oraz R6 pełnią funkcję pomiarową dla wzmacniacza operacyjnego oraz ochronną przed zwarciem. Wartość zadaną dla układu ustala cyfrowy potencjometr MCP4661 o rezystancji nominalnej 10 kΩ.
Na rysunku 11 przedstawiono wyniki symulacji wykonanej w programie LTspice. Ze względu na brak odpowiedniego modelu AO3400A użyto modelu tranzystora IRLR3802. Parametry obu elementów nie są identyczne, dlatego symulację potraktowano jako wstępną weryfikację koncepcji. Rzeczywistą charakterystykę układu wyznaczono później eksperymentalnie.

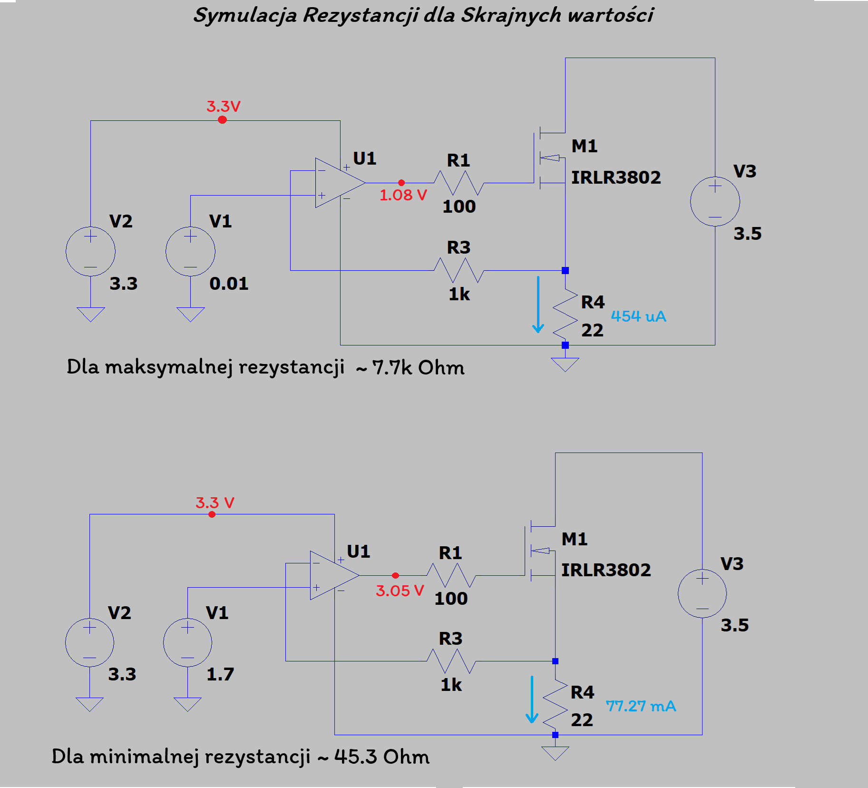
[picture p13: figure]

Rysunek 11: Wyniki symulacji układu emulacji rezystancji w programie LTspice

### 4.4 Obsługa magistrali CAN

Magistrala CAN wykorzystuje transmisję różnicową, a napięcie zasilania transceivera nie jest tym samym co poziom logiczny interfejsu mikrokontrolera. Teoretycznie zgodne transceivery powinny współpracować niezależnie od tego, czy po stronie cyfrowej wykorzystują logikę 3,3 V czy 5 V. Podczas uruchamiania projektu pojawił się jednak problem. Ramki wysyłane przez gotowy moduł z transceiverem SN65HVD230 były ignorowane przez licznik, natomiast po zastosowaniu modułu z TJA1050 komunikacja zaczęła działać poprawnie. Co ciekawe, w obu modułach znajdował się kontroler MCP2515.
Nie udało się jednoznacznie ustalić przyczyny tej różnicy. Możliwe wyjaśnienia to między innymi:
1. uszkodzenie lub nieprawidłowe działanie używanego modułu z SN65HVD230,
2. różnice konstrukcyjne pomiędzy gotowymi modułami, np. w terminacji lub sposobie prowadzenia sygnałów,
3. różnice parametrów elektrycznych samych transceiverów w konkretnych warunkach pracy. Na podstawie tych testów nie można więc stwierdzić, że licznik wymaga transceivera CAN zasilanego napięciem 5 V. W finalnym sterowniku zastosowano jednak MCP2562, ponieważ wcześniejsze próby z transceiverem zasilanym z 5 V działały poprawnie.

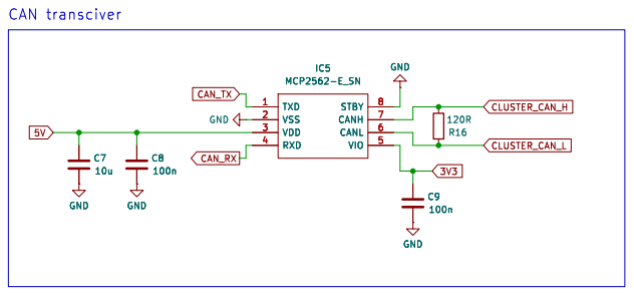
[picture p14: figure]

Rysunek 12: Schemat interfejsu magistrali CAN z transceiverem MCP2562

Układ MCP2562 jest zasilany napięciem 5 V, natomiast jego pin VIO pozwala ustawić poziomy logiczne interfejsu cyfrowego na 3,3 V. Dzięki temu linie TXD i RXD mogą być połączone bezpośrednio z mikrokontrolerem STM32F105, bez dodatkowego konwertera poziomów logicznych.

### 4.5 Obsługa kontrolek

Jak opisano w sekcji 3.2, dla wybranych wejść licznika przyjęto roboczy poziom logiczny 12 V na podstawie przeprowadzonych testów.
Wyjścia mikrokontrolera STM32F105 pracują z napięciem 3,3 V, dlatego nie mogą bezpośrednio sterować wejściami wykorzystującymi 12 V. Na rynku nie znalazłem układu scalonego, który przy założonym koszcie i liczbie kanałów pasowałby do tego zastosowania, dlatego konwersję wykonano na tranzystorach N-MOSFET.
Do wykonania nieodwracającego stopnia tranzystorowego potrzebne byłyby dwa elementy aktywne na kanał. Zastosowanie jednego tranzystora N-MOSFET z rezystorem podciągającym do 12 V powoduje odwrócenie stanu logicznego, ale tę inwersję można łatwo uwzględnić w oprogramowaniu. Dzięki temu liczbę tranzystorów dla dziewięciu kanałów ograniczono z 18 do 9, zmniejszając koszt oraz powierzchnię zajmowaną na PCB. Stany generowane przez firmware są z tego powodu odwrócone względem stanów przedstawionych w sekcji 3.2.

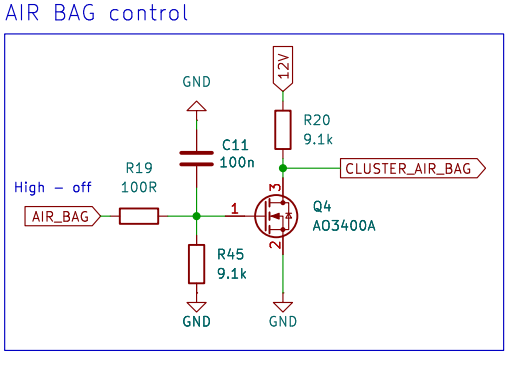
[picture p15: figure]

Rysunek 13: Pojedynczy kanał układu sterowania wejściem 12 V

### 4.6 Komunikacja z aplikacją Qt

Komunikacja sterownika z aplikacją Qt odbywa się przez interfejs USB VCP. USB posiada własne mechanizmy wykrywania błędów i retransmisji, dlatego suma kontrolna CRC8 zastosowana w autorskim protokole nie służy przede wszystkim do wykrywania pojedynczych błędów transmisji na przewodzie. Jest dodatkową kontrolą poprawności kompletnej ramki po stronie mikrokontrolera i pozwala wykryć m.in. sytuacje związane z utratą synchronizacji parsera lub niekompletną ramką. Protokół posiada również limit czasu (timeout) wynoszący 50 ms. Jeżeli rozpoczęto odbiór ramki, ale czas od odebrania ostatniego bajtu przekroczy ten limit, indeks bufora jest zerowany. Pozwala to wrócić parserowi do stanu początkowego np. po przerwaniu transmisji lub rozłączeniu urządzenia w trakcie odbioru ramki.

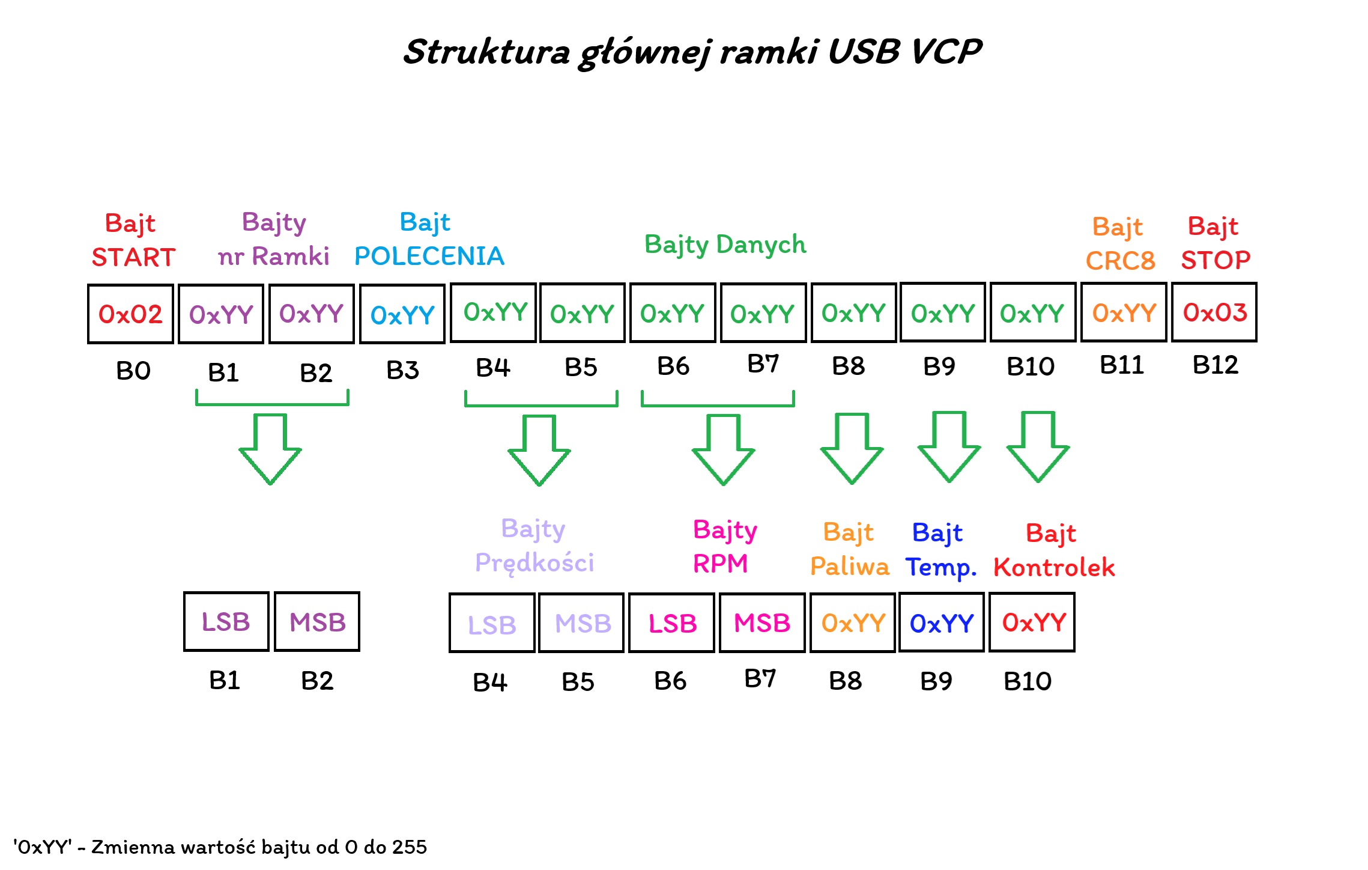
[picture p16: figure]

Rysunek 14: Struktura ramki protokołu komunikacyjnego przesyłanej przez USB VCP

W celu ograniczenia rozmiaru ramki stan ośmiu kontrolek upakowano do jednego bajtu w postaci maski bitowej. Po odebraniu i przetworzeniu nowej ramki sterownik odsyła do aplikacji numer wykonanej paczki jako Exec Ack. Pozwala to powiązać potwierdzenie z konkretną wysłaną ramką oraz zmierzyć czas przejścia danych w pętli UDP–PC–sterownik–PC (round-trip time, RTT).

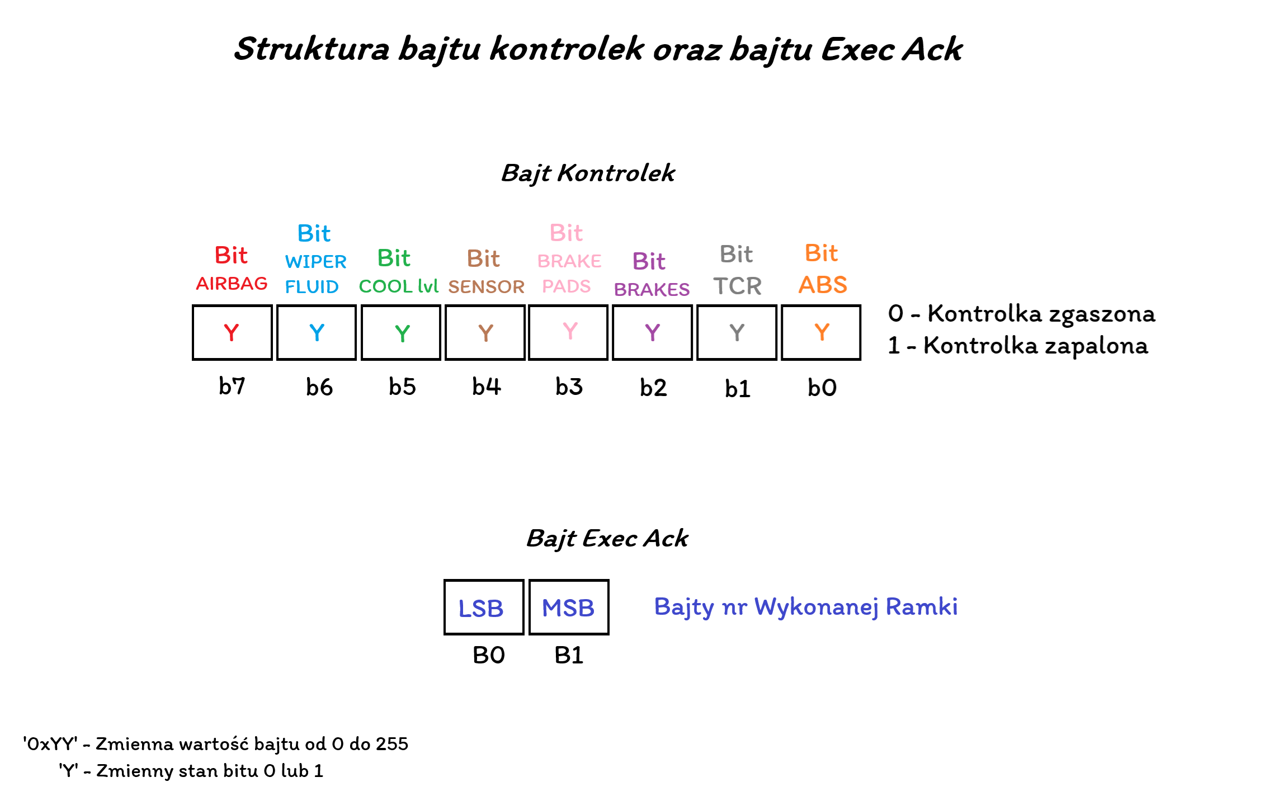
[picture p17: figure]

Rysunek 15: Struktura bajtu maski bitowej kontrolek oraz bajtu Exec Ack

### 4.7 Projekt PCB

Dwuwarstwową płytkę PCB zaprojektowano w programie KiCad. Zastosowano pola miedzi połączone z masą, w tym możliwie ciągłą płaszczyznę masy na dolnej warstwie. W projekcie znalazły się również bezpieczniki polimerowe PPTC na liniach zasilania 5 V i 12 V.
Szczególną uwagę zwrócono na prowadzenie ścieżek sygnałowych. Pary różnicowe USB i CAN prowadzono nad możliwie ciągłym obszarem masy, a linie I2C z dala od potencjalnych źródeł zakłóceń. Jako złącza zastosowano USB-C, gniazdo zasilania typu DC Barrel Jack oraz Molex Micro-Fit

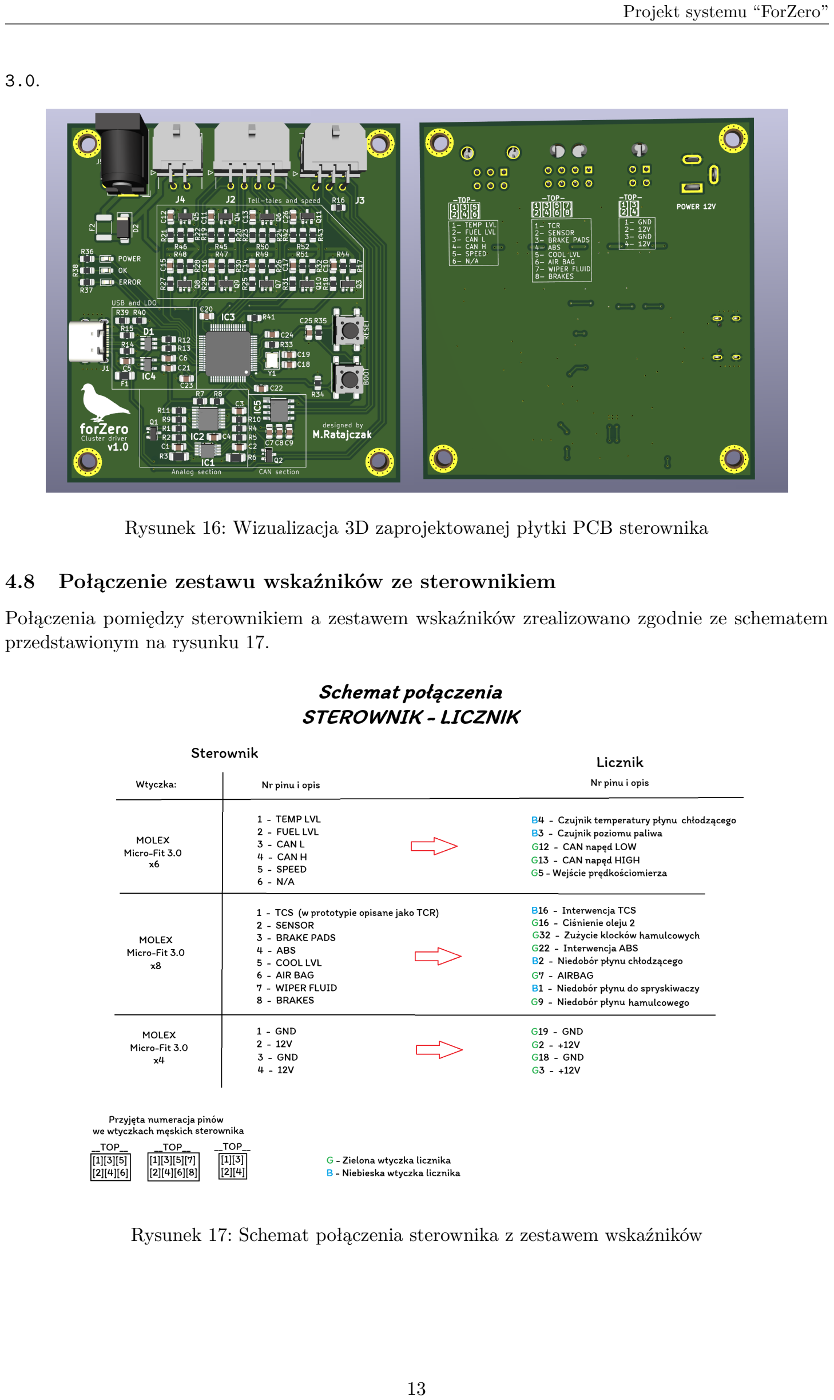
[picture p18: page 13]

3.0.

Rysunek 16: Wizualizacja 3D zaprojektowanej płytki PCB sterownika

### 4.8 Połączenie zestawu wskaźników ze sterownikiem

Połączenia pomiędzy sterownikiem a zestawem wskaźników zrealizowano zgodnie ze schematem przedstawionym na rysunku 17.

Rysunek 17: Schemat połączenia sterownika z zestawem wskaźników

### 5 Dedykowana aplikacja w środowisku Qt

### 5.1 Wielowątkowość aplikacji

Jako warstwę pośrednią między źródłem danych a sterownikiem wykorzystano autorską aplikację stworzoną w środowisku Qt Creator. Jednym z założeń było możliwie małe obciążenie zasobów komputera. W przeprowadzonych testach aplikacja zużywała maksymalnie około 2% czasu procesora na komputerze z Intel Core i7-11700F oraz około 20 MB pamięci RAM. Są to wyniki dla tej konkretnej konfiguracji i nie stanowią bezpośredniego porównania z innymi aplikacjami telemetrycznymi.
Architektura aplikacji została podzielona na trzy niezależne wątki:
- wątek główny (GUI) – odpowiedzialny za obsługę interfejsu graficznego,
- USB Worker – odpowiedzialny za asynchroniczną komunikację ze sterownikiem przez USB VCP,
- UDP Worker – odpowiedzialny za odbiór i parsowanie przychodzących pakietów telemetrycznych UDP.
Taki podział oddziela operacje komunikacyjne od obsługi interfejsu użytkownika. Dzięki temu odbiór danych UDP i komunikacja przez USB nie blokują wątku GUI, co ogranicza ryzyko jego chwilowego zawieszania podczas intensywnej transmisji.

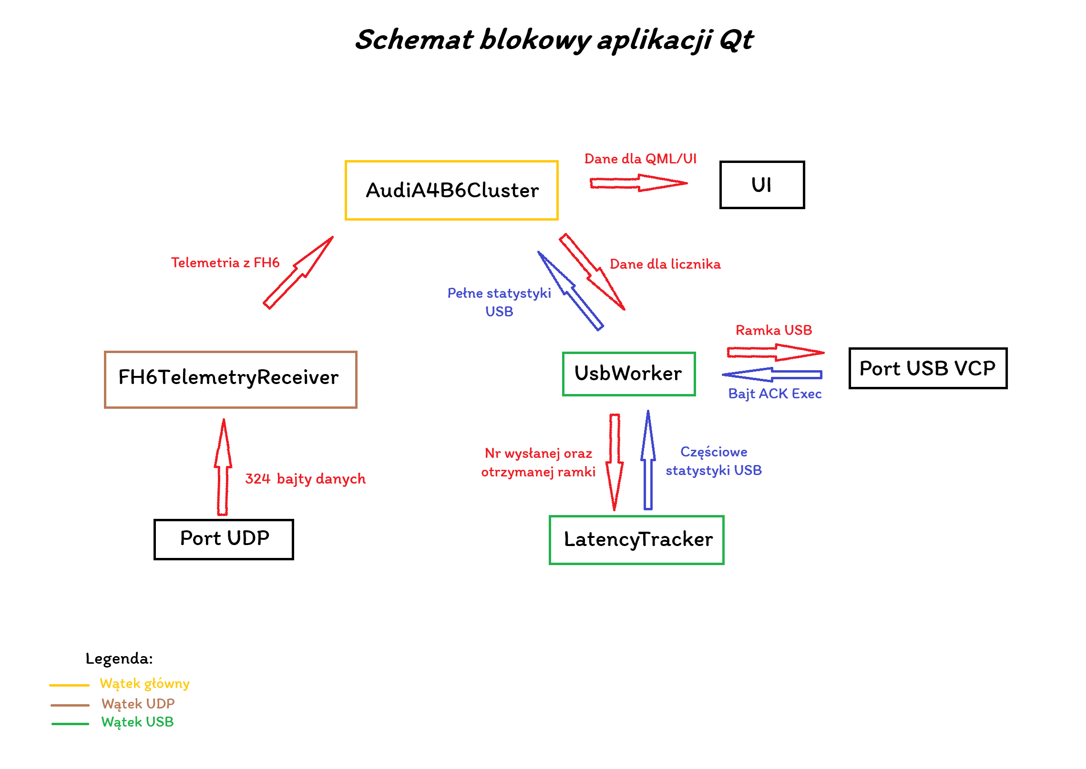
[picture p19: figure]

Rysunek 18: Schemat blokowy architektury wielowątkowej aplikacji Qt

### 5.2 Symulacja kontrolek i wskaźników

Zastosowanie własnej aplikacji umożliwia również symulację załączenia kontrolek TCS, ABS i AIRBAG oraz wskazania temperatury płynu chłodzącego. Przyjęte źródło danych nie udostępnia bezpośrednio informacji o interwencji tych układów ani temperatury płynu chłodzącego, dlatego odpowiednie stany są wyznaczane na podstawie dostępnych danych telemetrycznych. Gra wysyła poziom paliwa, tylko w przypadku włączenia w ustawieniach gry "uszkodzęń symulacyjnych". W przyszłości możliwe jest również dodanie symulacji zużycia klocków hamulcowych.

Warto zaznaczyć, że użyte algorytmy nie są modelami fizycznymi poszczególnych układów pojazdu. Służą jedynie do przybliżonego odwzorowania zachowania kontrolek i wskaźników na podstawie telemetrii dostępnej w grze.

### 6 Program mikrokontrolera

### 6.1 Środowisko

Oprogramowanie mikrokontrolera STM32F105 powstało w środowisku STM32CubeIDE z wykorzystaniem bibliotek HAL (Hardware Abstraction Layer).
Program można wgrywać do mikrokontrolera przez USB z wykorzystaniem wbudowanego bootloadera. Dzięki temu nie było konieczne dodawanie na PCB osobnego złącza przeznaczonego wyłącznie do programowania. Aby uruchomić odpowiedni tryb rozruchowy, należy nacisnąć RESET, następnie przytrzymując go nacisnąć BOOT, zwolnić RESET, a na końcu BOOT.

### 6.2 Pętla zdarzeń

Program mikrokontrolera STM32 opiera się na nieblokującej pętli zdarzeń, z której wyeliminowano funkcje wprowadzające aktywne opóźnienia, takie jak HAL_Delay(). Poszczególne zadania są wykonywane zdarzeniowo lub w określonych interwałach czasowych. Dzięki temu obsługa CAN, I2C i wskaźników nie blokuje pozostałych funkcji programu. Odbiór danych z USB VCP odbywa się asynchronicznie z wykorzystaniem mechanizmu przerwań USB.
Przepływ danych w pętli głównej przedstawiono na rysunku 19. Działanie programu można podzielić na cztery główne etapy:
1. Odbiór i weryfikacja danych USB. Po ustawieniu flagi nowej ramki dane są kopiowane do lokalnej struktury local_cluster w sekcji krytycznej. Następnie sprawdzane są bajty początku i końca ramki oraz suma kontrolna CRC8. W przypadku błędu ramka jest odrzucana, a układ pozostaje przy ostatnim poprawnie odebranym stanie.
2. Logika i zabezpieczenie Fail-safe. Mikrokontroler kontroluje czas od odebrania ostatniej poprawnej ramki. Jeżeli przekroczy on 500 ms, wartości prędkości i obrotów zostają wyzerowane, dzięki czemu wskazówki wracają do pozycji początkowej. Na tym etapie realizowany jest również test diagnostyczny wskazówek. Jeżeli czas od otrzymania jakiejkolwiek ramki przekroczy 50ms następuje zerowanie indeksu bufora i parser ponownie szuka początku ramki.
3. Wysterowanie wyjść i obsługa interwałów czasowych. Odświeżanie poszczególnych sygnałów realizowane jest na podstawie funkcji HAL_GetTick():
- prędkość i kontrolki – aktualizowane są zdarzeniowo, gdy ich wartość zmieni się względem poprzedniego stanu,
- prędkość obrotowa silnika (RPM) – ramka CAN o identyfikatorze 0x280 jest wysyłana co 20 ms,
- temperatura płynu chłodzącego – aktualizowana jest co 2000 ms,
- poziom paliwa – nowa wartość jest przesyłana przez I2C do cyfrowego potencjometru co 5000 ms, jeżeli wcześniej odebrano nowe dane.
4. Potwierdzenie wykonania (Exec Ack). Po przetworzeniu nowej ramki i wykonaniu związanych z nią operacji mikrokontroler odsyła do aplikacji Qt komunikat Exec Ack z numerem przetworzonej paczki. Pozwala to powiązać potwierdzenie z wysłaną ramką i wykorzystywane jest m.in. do pomiaru RTT.

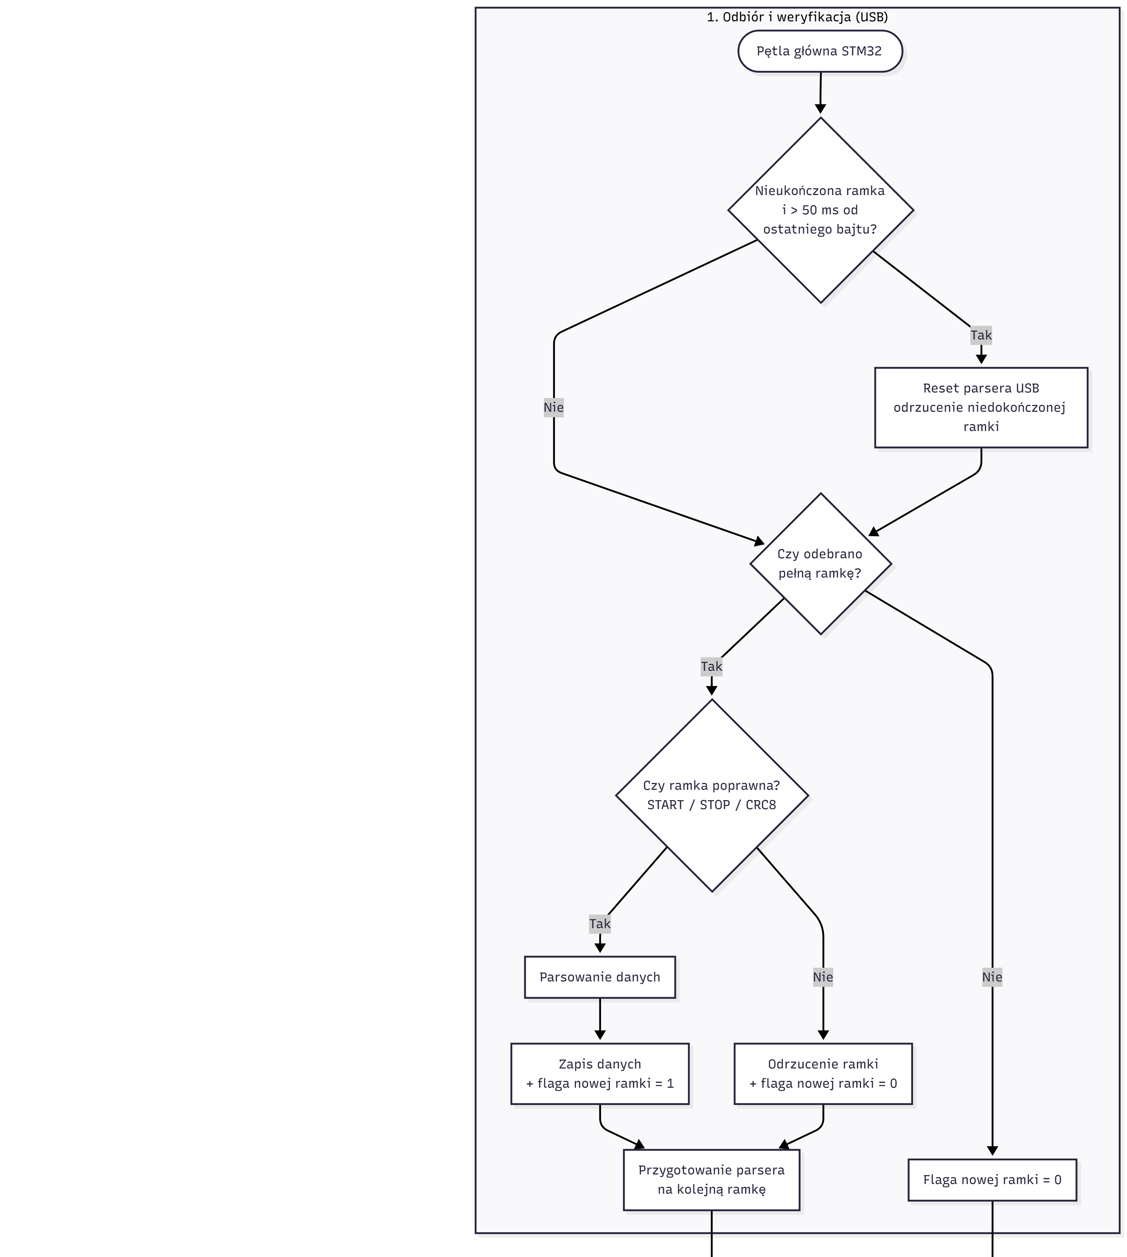
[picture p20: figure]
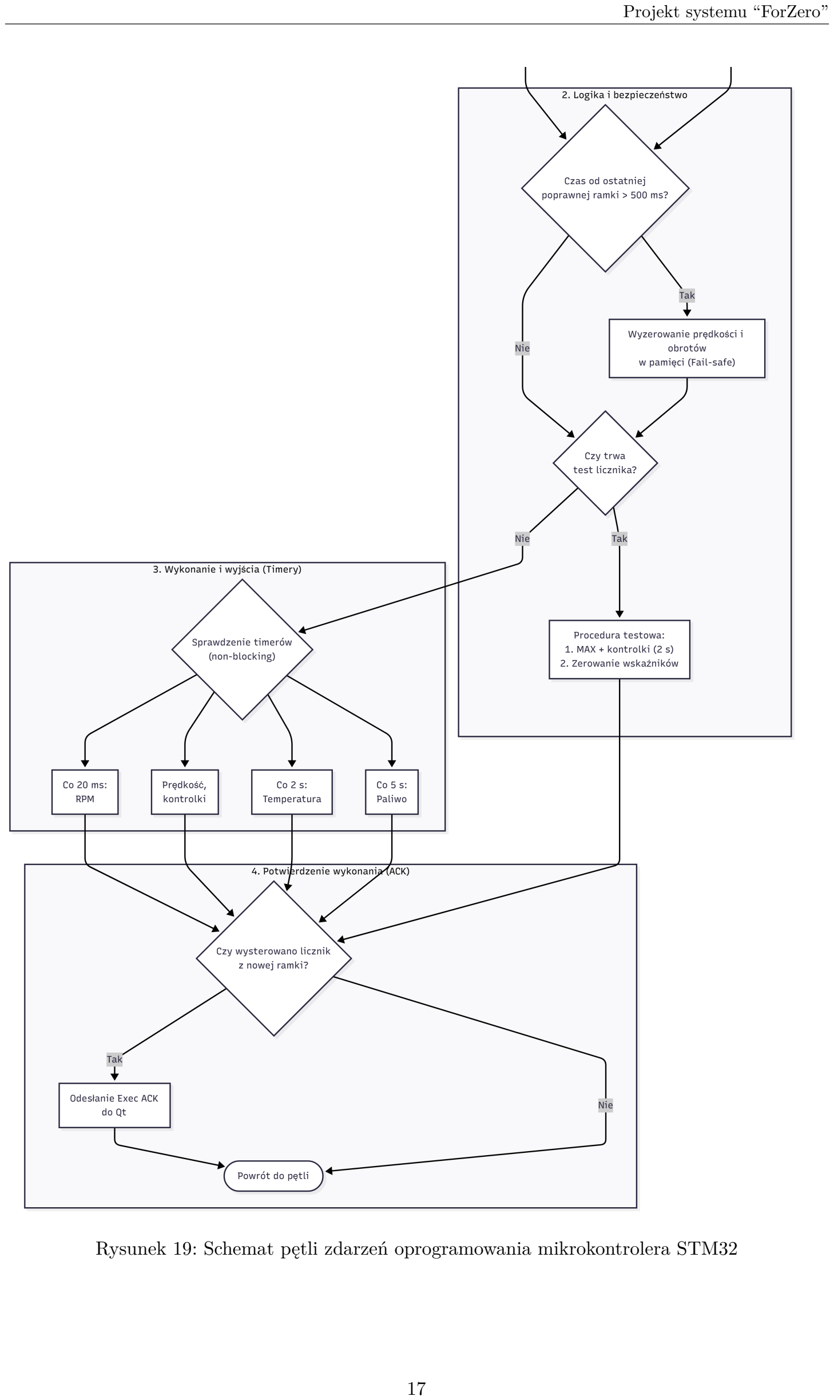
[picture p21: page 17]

Rysunek 19: Schemat pętli zdarzeń oprogramowania mikrokontrolera STM32

### 7 Testy oraz zabezpieczenia

### 7.1 Zabezpieczenia zastosowane w sterowniku

Sterownik jest jednocześnie podłączony do portu USB komputera i zewnętrznego źródła zasilania 12 V, dlatego na etapie projektowania PCB uwzględniono zabezpieczenia przed zwarciem, nadmiernym poborem prądu oraz wyładowaniami elektrostatycznymi ESD.
Linie sygnałowe USB zabezpieczono za pomocą układu USBLC6-2SC6. Rodzina tych układów obejmuje również wariant przeznaczony do zastosowań motoryzacyjnych, kwalifikowany zgodnie z AEC-Q101.
Na linii zasilania USB zastosowano bezpiecznik polimerowy PPTC o prądzie znamionowym 500 mA. Dla zewnętrznego zasilania 12 V zastosowano bezpiecznik PPTC o prądzie znamionowym 1,25 A, dobrany z zapasem względem prądu pobieranego podczas normalnej pracy zestawu wskaźników. Na rysunku 20 przedstawiono schemat podłączenia gniazda USB-C. Rezystory pull-down R14 i R15 o wartości 5,1 kΩ na liniach CC1 i CC2 pełnią funkcję rezystorów Rd. Pozwalają źródłu USB-C wykryć sterownik jako urządzenie pobierające zasilanie (Sink) i pełniące rolę UFP. Zastosowanie rezystorów na obu liniach CC zapewnia poprawną detekcję niezależnie od orientacji wtyczki USB-C.

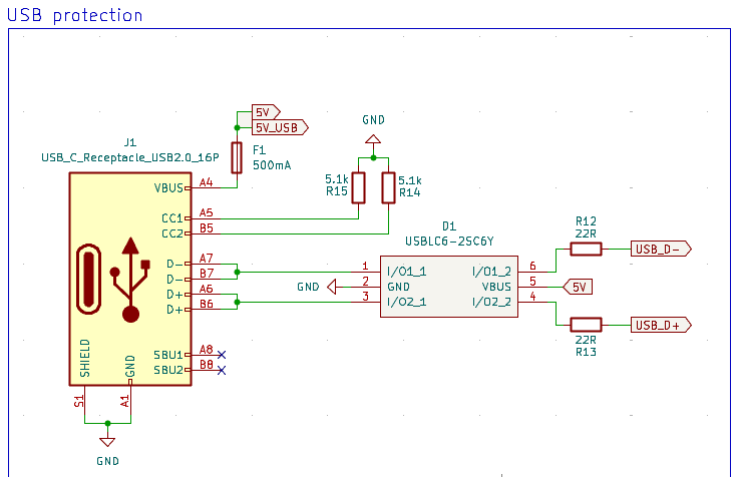
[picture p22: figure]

Rysunek 20: Schemat podłączenia portu USB typu C wraz z zabezpieczeniami na PCB sterownika

### 7.2 Opóźnienia

Pomiar opóźnień w pętli PC → sterownik → PC (Round-Trip Time, RTT) zrealizowano za pomocą komunikatu Exec Ack, który zawiera numer wykonanej ramki. Klasa LatencyTracker w aplikacji Qt mierzy czas od wysłania ramki do odebrania odpowiadającego jej potwierdzenia i wyznacza statystyki dla 20 000 ostatnich pomiarów. Przy częstotliwości 60 Hz odpowiada to około 333 s, czyli 5 minutom i 33 sekundom danych.
Do przechowywania wyników wykorzystano bufor kołowy (circular buffer) o stałej pojemności. Dzięki temu ilość pamięci zajmowana przez historię pomiarów nie rośnie wraz z czasem działania aplikacji.

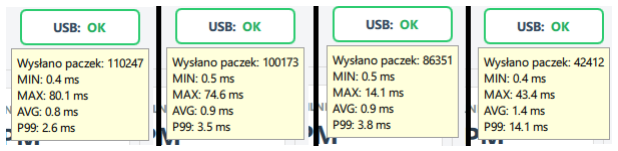
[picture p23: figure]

Rysunek 21: Uzyskane statystyki opóźnień RTT dla różnych zestawów pomiarowych w aplikacji Qt

W większości przeprowadzonych zestawów pomiarowych średnia wartość RTT wynosiła poniżej 1 ms, a 99. percentyl (P99) pozostawał poniżej 4 ms. W najbardziej skrajnym z zarejestrowanych zestawów P99 osiągnął 17 ms. Oznacza to, że 99% zmierzonych czasów przejścia przez pętlę PC– sterownik–PC nie przekroczyło 17 ms.
Dla porównania okres pojedynczej klatki przy 165 Hz wynosi około 6,06 ms, a przy 60 Hz około 16,67 ms. Porównanie ma jedynie charakter orientacyjny, ponieważ RTT obejmuje komunikację i przetwarzanie danych w pętli PC–sterownik–PC, a nie pełny czas od wygenerowania danych przez grę do mechanicznego wychylenia wskazówki. Wyniki pokazują jednak, że opóźnienie wprowadzane przez warstwę komunikacyjną i programową jest niewielkie w stosunku do dynamiki fizycznego zestawu wskaźników.
System można określić jako rozwiązanie miękkiego czasu rzeczywistego (Soft Real-Time). Terminowe przetwarzanie danych wpływa na jakość działania, ale sporadyczne przekroczenie założonego czasu obsługi nie powoduje awarii ani sytuacji krytycznej. Uzyskane wyniki RTT są wystarczające dla realizowanej funkcji interfejsu człowiek–maszyna.

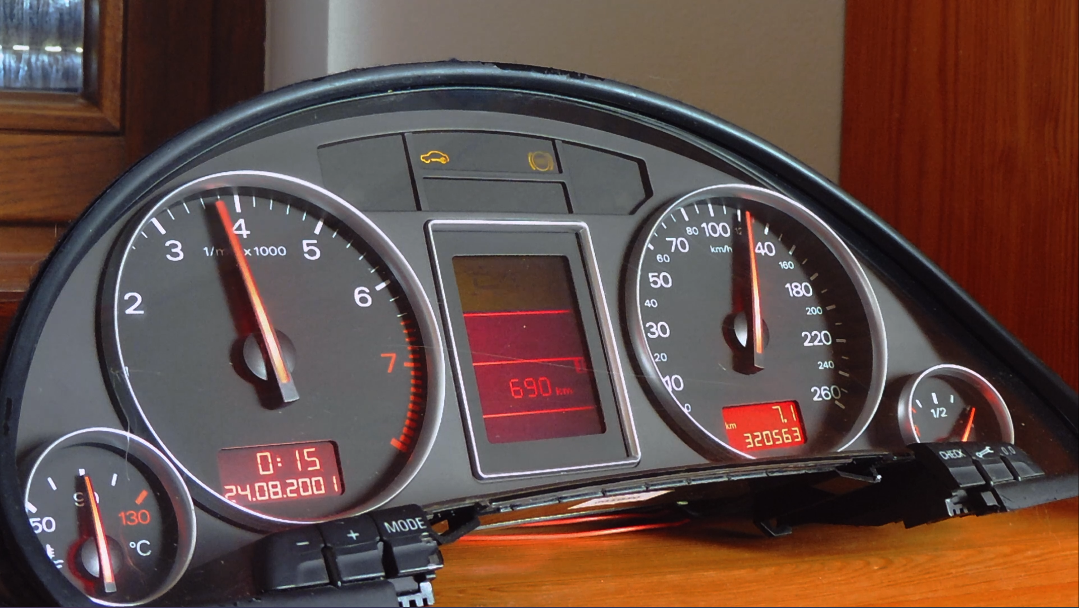
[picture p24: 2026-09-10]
Obrazy/zestaw.png

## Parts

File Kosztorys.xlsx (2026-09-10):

Drobnica zamawiana w większej ilości ze względu na optymalizację cen przyszłych projektów
UKŁADY SCALONE
typ | nazwa | link | Ilość | Cena l.p netto | Łącznie brutto | SUMA
transciver CAN | MCP2562-E/SN | TME (https://www.tme.eu/pl/details/mcp2562-e_sn/uklady-scalone-interfejs-can/microchip-technology/) | 1 | 4.26 | 5.24 | 379.19
potencjometr cyfrowy | MCP4661-103E/ST | TME (https://www.tme.eu/pl/details/mcp4661-103est/potencjometry-cyfrowe/microchip-technology/mcp4661-103e-st/) | 1 | 5.34 | 6.57
wzmacniacz operacyjny | NCV21872DMR2G | TME (https://www.tme.eu/pl/details/ncv21872dmr2g/wzmacniacze-operacyjne-smd/onsemi/) | 1 | 2.41 | 2.96
microkontroler | STM32F105RBT6 | TME (https://www.tme.eu/pl/details/stm32f105rbt6/mikrokontrolery-st/stmicroelectronics/) | 1 | 25.31 | 31.13
LDO 3.3V | AP7347DQ-33W5-7 | TME (https://www.tme.eu/pl/details/ap7347dq-33w5-7/stabilizatory-napiecia-nieregulowane-ldo/diodes-incorporated/) | 1 | 1.93 | 2.37
USB ESD Protection | USBLC6-2SC6Y | TME (https://www.tme.eu/pl/details/usblc6-2sc6y/diody-zabezpieczajace-drabinki/stmicroelectronics/) | 1 | 1.48 | 1.82
WTYCZKI |  |  |  |  | 0
Wtyczka Micro-Fit 3.0 4pin | 43025-0410 | TME (https://www.tme.eu/pl/details/mx-43025-0410/zlacza-pozostale-molex/molex/43025-0410/) | 1 | 1.67 | 2.05
Wtyczka Micro-Fit 3.0 8pin | 43025-0808 | TME (https://www.tme.eu/pl/details/mx-43025-0808/zlacza-pozostale-molex/molex/43025-0808/) | 1 | 2.18 | 2.68
Wtyczka Micro-Fit 3.0 6pin | 43025-0600 | TME (https://www.tme.eu/pl/details/mx-43025-0600/zlacza-sygnalowe-raster-3-00mm/molex/43025-0600/) | 1 | 1.10 | 1.35
Styk żeński MF3.0 cynowany | 43030-0007 | TME (https://www.tme.eu/pl/details/mx-43030-0007/zlacza-sygnalowe-raster-3-00mm/molex/43030-0007/) | 35 | 0.382 | 16.45
Gniazdo Micro-Fit 3.0 6pin | 43045-0621 | TME (https://www.tme.eu/pl/details/mx-43045-0621/zlacza-sygnalowe-raster-3-00mm/molex/43045-0621/) | 1 | 5.84 | 7.18
Gniazdo Micro-Fit 3.0 4pin | 43045-0400 | TME (https://www.tme.eu/pl/details/mx-43045-0400/zlacza-sygnalowe-raster-3-00mm/molex/43045-0400/) | 1 | 3.70 | 4.55
Gniazdo Micro-Fit 3.0 8pin | 43045-0800 | TME (https://www.tme.eu/pl/details/mx-43045-0800/zlacza-sygnalowe-raster-3-00mm/molex/43045-0800/) | 1 | 4.59 | 5.65
Gniazdo USB C 16 pin | USB4105-GF-A-120 | TME (https://www.tme.eu/pl/details/usb4105-gf-a-120/zlacza-usb-i-ieee1394/gct/) | 1 | 2.79 | 3.43
Gniazdo DC Jack | DC-10A FC68148 | TME (https://www.tme.eu/pl/details/fc68148/zlacza-dc/cliff/dc-10a-fc68148/) | 1 | 2.97 | 3.65
DROBNICA |  |  |  |  | 0
bezpiecznik polimerowy 500mA | 0ZCJ0050FF2G | TME (https://www.tme.eu/pl/details/0zcj0050ff2g/bezpieczniki-polimerowe-smd/bel-fuse/) | 10 | 0.41 | 5.10
bezpiecznik polimerowy 1.25A | 1812L125/16DR | TME (https://www.tme.eu/pl/details/1812l125_16dr/bezpieczniki-polimerowe-smd/littelfuse/) | 2 | 1.56 | 3.84
kwarc 25MHz | 3225-25M-SR | TME (https://www.tme.eu/pl/details/3225-25m-sr/rezonatory-i-generatory/sr-passives/) | 10 | 0.66 | 8.07
Mikroprzełącznik TACT | PTS645SK43SMTR92 LFS | TME (https://www.tme.eu/pl/details/pts645sk43smtr92/mikroprzelaczniki-tact/c-k/pts645sk43smtr92-lfs/) | 4 | 1.26 | 6.18
LED zielona | OSG80603C1E | TME (https://www.tme.eu/pl/details/osg80603c1e/diody-led-smd-kolorowe/optosupply/) | 10 | 0.33 | 4.05
LED pomaranczowa | OSO50603C1E | TME (https://www.tme.eu/pl/details/oso50603c1e/diody-led-smd-kolorowe/optosupply/) | 5 | 0.68 | 4.16
kondensator 10nF | C0805C103K1RACTU | TME (https://www.tme.eu/pl/details/c0805c103k1rac/kondensatory-mlcc-smd/kemet/c0805c103k1ractu/) | 50 | 0.08 | 5.10
kondensator 100nF | KGM21NR71H104KT | TME (https://www.tme.eu/pl/details/kgm21nr71h104kt/kondensatory-mlcc-smd/kyocera-avx/) | 100 | 0.06 | 6.93
kondensator 10uF | GRM21BR60J106KE19L | TME (https://www.tme.eu/pl/details/grm21br60j106ke19l/kondensatory-mlcc-smd/murata/) | 25 | 0.20 | 6.02
kondensator 1nF | KGM21NR71H102KT | TME (https://www.tme.eu/pl/details/kgm21nr71h102kt/kondensatory-mlcc-smd/kyocera-avx/) | 50 | 0.0767 | 4.72
kondensator 10pF | 08055A100JAT2A | TME (https://www.tme.eu/pl/details/08055a100jat2a/kondensatory-mlcc-smd/kyocera-avx/) | 25 | 0.1149 | 3.53
dioda shottky 2A | SS23 | TME (https://www.tme.eu/pl/details/ss23-yan/diody-schottky-smd/yangjie-technology/ss23/) | 5 | 0.5256 | 3.23
Rezystor 100R | CRCW0805100RFKTABC | TME (https://www.tme.eu/pl/details/crcw0805100rfktabc/rezystory-smd/vishay/) | 50 | 0.03957 | 2.43
Rezystor 1k | CRCW08051K00FKTABC | TME (https://www.tme.eu/pl/details/crcw08051k00fktabc/rezystory-smd/vishay/) | 100 | 0.01861 | 2.29
22R 1206 | CRCW120622R0FKTABC | TME (https://www.tme.eu/pl/details/crcw120622r0fktabc/rezystory-smd/vishay/) | 100 | 0.02808 | 3.45
5.1k 0805 | RC0805FR-075K1L | TME (https://www.tme.eu/pl/details/rc0805fr-075k1/rezystory-smd/yageo/rc0805fr-075k1l/) | 50 | 0.0609 | 3.75
9.1k 0805 | RC0805FR-079K1L | TME (https://www.tme.eu/pl/details/rc0805fr-079k1l/rezystory-smd/yageo/) | 100 | 0.021146 | 2.60
22R 0805 | RC0805FR-0722RL | TME (https://www.tme.eu/pl/details/rc0805fr-0722r/rezystory-smd/yageo/rc0805fr-0722rl/) | 50 | 0.02928 | 1.80
120R 0805 | WR08X1200FTL | TME (https://www.tme.eu/pl/details/wr08x1200ftl/rezystory-smd/walsin/) | 100 | 0.02597 | 3.19
270R 0805 | CRCW0805270RFKTABC | TME (https://www.tme.eu/pl/details/crcw0805270rfktabc/rezystory-smd/vishay/) | 50 | 0.03764 | 2.31
10k 0805 | CRCW080510K0FKEA | TME (https://www.tme.eu/pl/details/crcw080510k0fkea/rezystory-smd/vishay/) | 50 | 0.0298 | 1.83
22k 0805 | CRCW080522K0FKEA | TME (https://www.tme.eu/pl/details/crcw080522k0fkea/rezystory-smd/vishay/) | 25 | 0.0725 | 2.23
82k 0805 | ERA6AEB823V | TME (https://www.tme.eu/pl/details/era6aeb823v/rezystory-smd/panasonic/) | 20 | 0.2568 | 6.32
33k 0805 | RC0805FR-0733KL | TME (https://www.tme.eu/pl/details/rc0805fr-0733k/rezystory-smd/yageo/rc0805fr-0733kl/) | 50 | 0.04283 | 2.63
N-mosfet | AO3400A | TME (https://www.tme.eu/pl/details/ao3400a/tranzystory-z-kanalem-n-smd/alpha-omega-semiconductor/) | 25 | 0.3395 | 10.44
typ | nazwa | link | Ilość | Cena l.p brutto | Łącznie brutto
NARZĘDZIA |  |  |  |  | 0
Topnik w żelu | ART.AGT-179 | TME (https://www.tme.eu/pl/details/topnik-zel_10/topniki/ag-termopasty/art-agt-179/) | 1 | 27.54 | 33.87
PRZEWODY
LRFY-B 0.35mm 5 kolorów | LRFY-B 0.35mm 5 kolorów | Allegro (https://allegro.pl/oferta/przewod-kabel-samochodowy-flry-b-0-35-zielony-5m-13471599200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) | 5 | 10 | 50
PCB |  |  |  |  | 0
PCB | autorskie pcb | JLC PCB | 1 | 17 | 17
 | LICZNIK |  |  |  | 0
licznik audi a4 b6 | 8E0920900H RB4 |  | 1 | 75 | 75

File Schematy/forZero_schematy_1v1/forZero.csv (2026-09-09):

Reference | Qty | Value | DNP | Exclude from BOM | Exclude from Board | Footprint | Datasheet
BOOT1,RESET1 | 2 | SW_Push |  |  |  | Button_Switch_SMD:SW_SPST_PTS645Sx43SMTR92 | ~
C1,C2 | 2 | 10n |  |  |  | Capacitor_SMD:C_0805_2012Metric_Pad1.18x1.45mm_HandSolder | ~
C3,C4,C8,C9,C11,C12,C13,C14,C15,C16,C17,C20,C21,C22,C23,C24,C25,C26 | 18 | 100n |  |  |  | Capacitor_SMD:C_0805_2012Metric_Pad1.18x1.45mm_HandSolder | ~
C5,C6,C7 | 3 | 10u |  |  |  | Capacitor_SMD:C_0805_2012Metric_Pad1.18x1.45mm_HandSolder | ~
C10 | 1 | 1n |  |  |  | Capacitor_SMD:C_0805_2012Metric_Pad1.18x1.45mm_HandSolder | ~
C18,C19 | 2 | 10p |  |  |  | Capacitor_SMD:C_0805_2012Metric_Pad1.18x1.45mm_HandSolder | ~
D1 | 1 | USBLC6-2SC6Y |  |  |  | SOT95P280X145-6N | https://www.st.com/resource/en/datasheet/usblc6-2sc6y.pdf
D2 | 1 | SS23 |  |  |  | Diode_SMD:D_SMA | https://www.vishay.com/docs/88748/ss22.pdf
ERROR1,OK1,POWER1 | 3 | LED |  |  |  | LED_SMD:LED_0603_1608Metric_Pad1.05x0.95mm_HandSolder | ~
F1 | 1 | 500mA |  |  |  | Fuse:Fuse_1206_3216Metric_Pad1.42x1.75mm_HandSolder | ~
F2 | 1 | 1.25A |  |  |  | Fuse:Fuse_1812_4532Metric_Pad1.30x3.40mm_HandSolder | ~
IC1 | 1 | NCV21872DMR2G |  |  |  | SOP65P490X110-8N | https://www.onsemi.com/pdf/datasheet/ncs21871-d.pdf
IC2 | 1 | MCP4661-103E_ST |  |  |  | SOP65P640X120-14N | http://ww1.microchip.com/downloads/en/DeviceDoc/22107B.pdf
IC3 | 1 | STM32F105RBT6 |  |  |  | QFP50P1200X1200X160-64N | https://www.st.com/resource/en/datasheet/stm32f105r8.pdf
IC4 | 1 | AP7347DQ-33W5-7 |  |  |  | SOT95P280X145-5N | https://www.diodes.com//assets/Datasheets/AP7347DQ.pdf
IC5 | 1 | MCP2562-E_SN |  |  |  | SOIC127P600X175-8N | https://datasheet.datasheetarchive.com/originals/distributors/Datasheets-DGA14/1194231.pdf
J1 | 1 | USB_C_Receptacle_USB2.0_16P |  |  |  | Connector_USB:USB_C_Receptacle_GCT_USB4105-xx-A_16P_TopMnt_Horizontal | https://www.usb.org/sites/default/files/documents/usb_type-c.zip
J2 | 1 | 43045-0800 |  |  |  | SamacSys_Parts:43045-08_00,01,02,10_ | https://www.molex.com/pdm_docs/sd/430450200_sd.pdf
J3 | 1 | 43045-0621 |  |  |  | 43045-06YY_212223 | https://www.molex.com/pdm_docs/sd/430450221_sd.pdf
J4 | 1 | 43045-0400 |  |  |  | SamacSys_Parts:43045-04_00,01,02,10_ | https://www.molex.com/pdm_docs/sd/430450200_sd.pdf
J5 | 1 | Barrel_Jack_Switch |  |  |  | Connector_BarrelJack:BarrelJack_GCT_DCJ200-10-A_Horizontal | ~
Q1,Q2,Q3,Q4,Q5,Q6,Q7,Q8,Q9,Q10,Q11 | 11 | AO3400A |  |  |  | Package_TO_SOT_SMD:SOT-23 | http://www.aosmd.com/pdfs/datasheet/AO3400A.pdf
R1,R4,R18,R19,R21,R23,R25,R27,R29,R31,R42 | 11 | 100R |  |  |  | Resistor_SMD:R_0805_2012Metric_Pad1.20x1.40mm_HandSolder | ~
R2,R5 | 2 | 1k |  |  |  | Resistor_SMD:R_0805_2012Metric_Pad1.20x1.40mm_HandSolder | ~
R3,R6 | 2 | 22R |  |  |  | Resistor_SMD:R_1206_3216Metric_Pad1.30x1.75mm_HandSolder | ~
R7,R8,R14,R15 | 4 | 5.1k |  |  |  | Resistor_SMD:R_0805_2012Metric_Pad1.20x1.40mm_HandSolder | ~
R9,R10,R11,R17,R20,R22,R24,R26,R28,R30,R32,R34,R35,R41,R43,R44,R45,R46,R47,R48,R49,R50,R51,R52 | 24 | 9.1k |  |  |  | Resistor_SMD:R_0805_2012Metric_Pad1.20x1.40mm_HandSolder | ~
R12,R13 | 2 | 22R |  |  |  | Resistor_SMD:R_0805_2012Metric_Pad1.20x1.40mm_HandSolder | ~
R16 | 1 | 120R |  |  |  | Resistor_SMD:R_0805_2012Metric_Pad1.20x1.40mm_HandSolder | ~
R36,R37,R38 | 3 | 270R |  |  |  | Resistor_SMD:R_0805_2012Metric_Pad1.20x1.40mm_HandSolder | ~
R39 | 1 | 22k |  |  |  | Resistor_SMD:R_0805_2012Metric_Pad1.20x1.40mm_HandSolder | ~
Y1 | 1 | 25MHz |  |  |  | Crystal:Crystal_SMD_3225-4Pin_3.2x2.5mm | ~

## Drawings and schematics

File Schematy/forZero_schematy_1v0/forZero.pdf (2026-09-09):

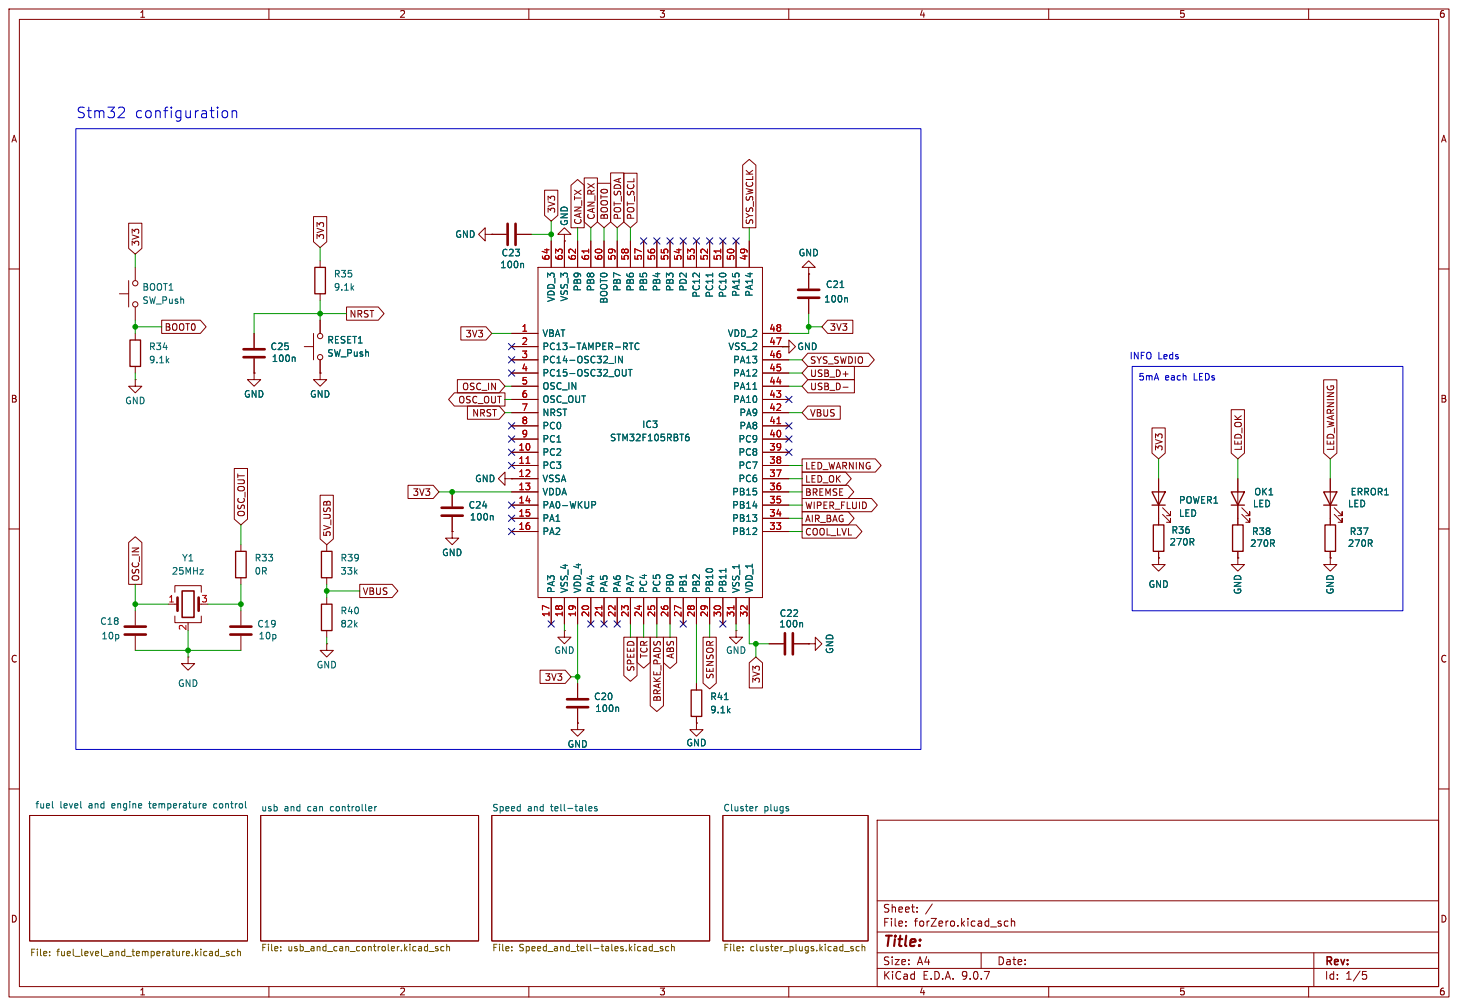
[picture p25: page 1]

INFO Leds 5mA each LEDs Stm32 configuration

Speed and tell-tales File: Speed_and_tell-tales.kicad_sch

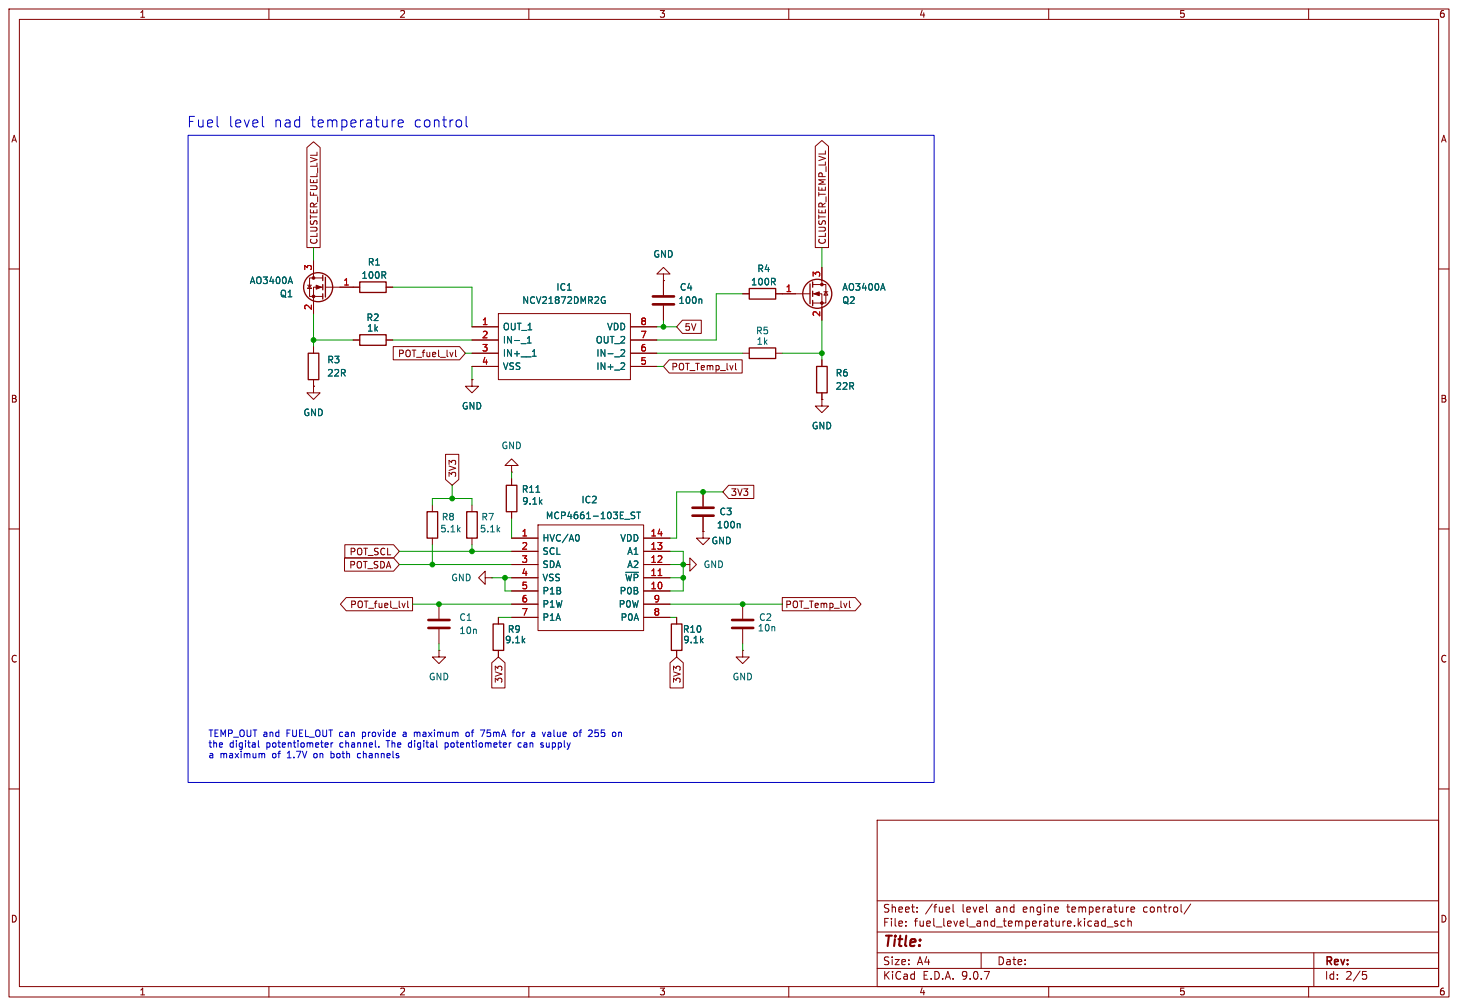
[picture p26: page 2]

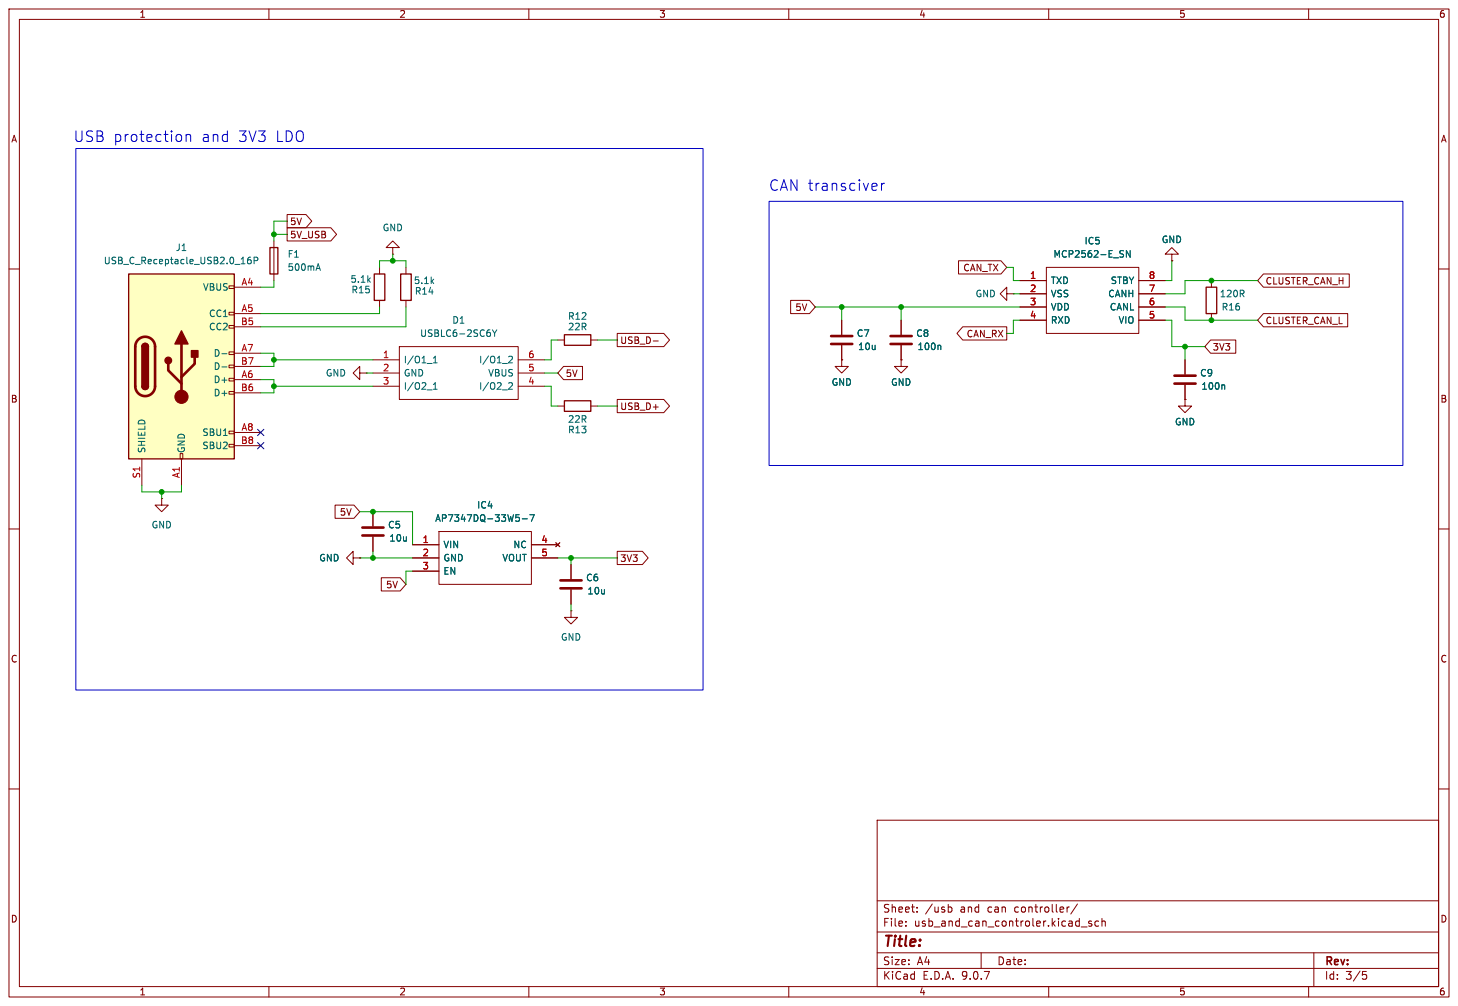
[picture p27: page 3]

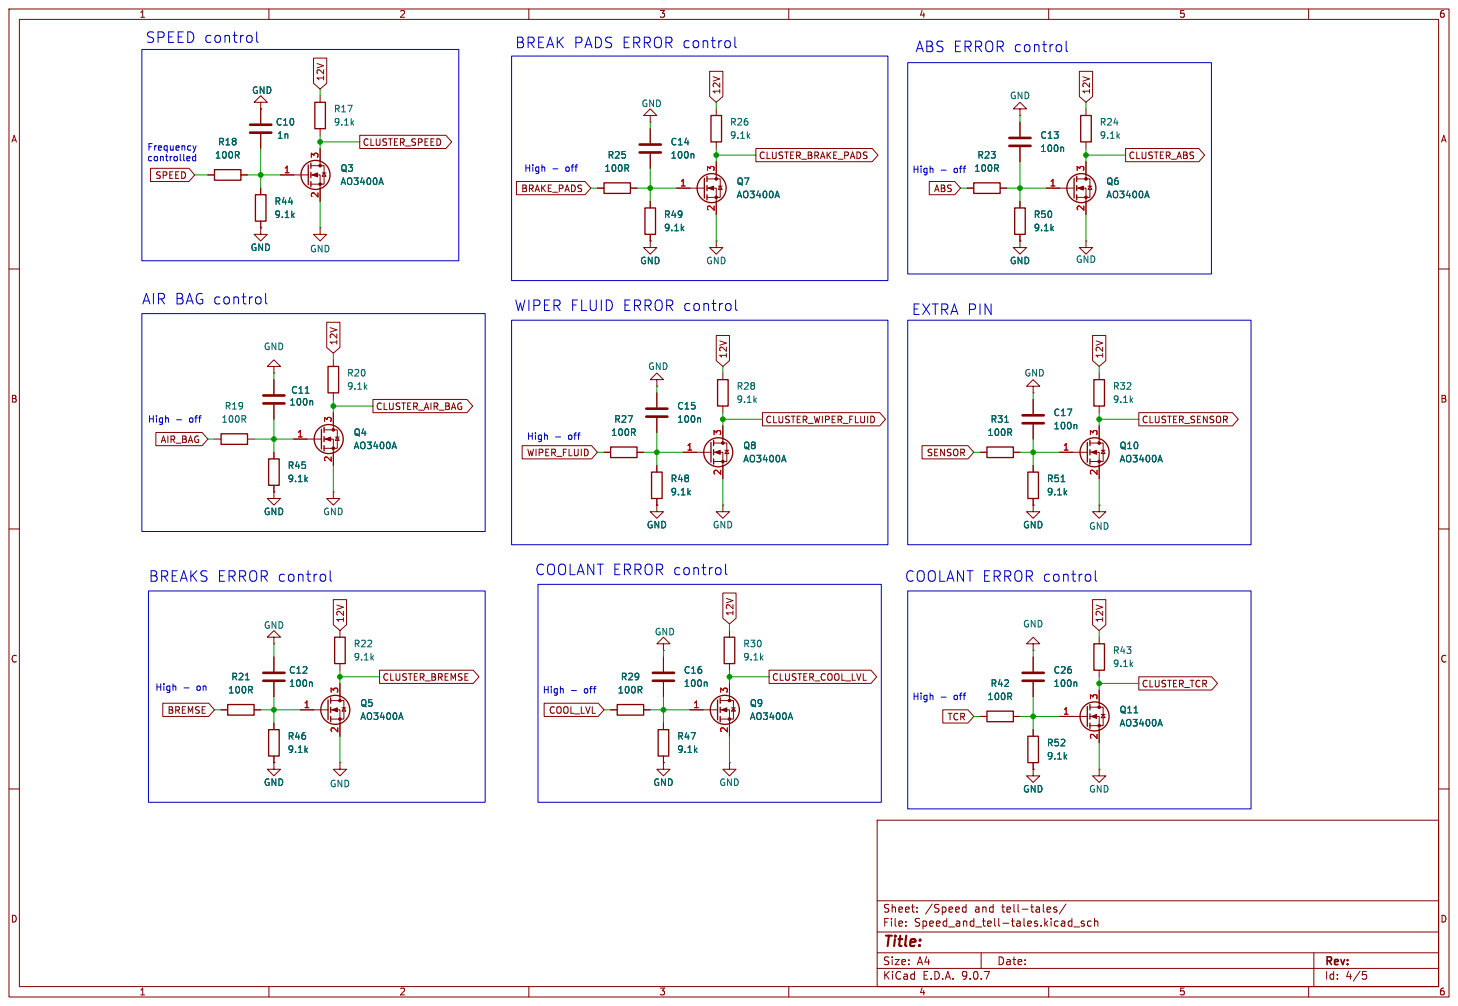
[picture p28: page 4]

Frequency
High - off BREAKS ERROR control
SPEED

High - off AIR BAG control

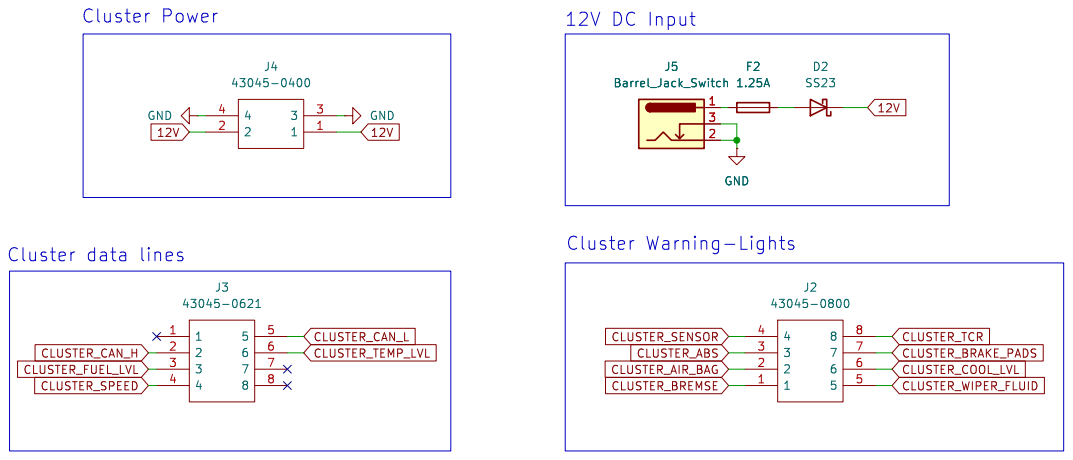
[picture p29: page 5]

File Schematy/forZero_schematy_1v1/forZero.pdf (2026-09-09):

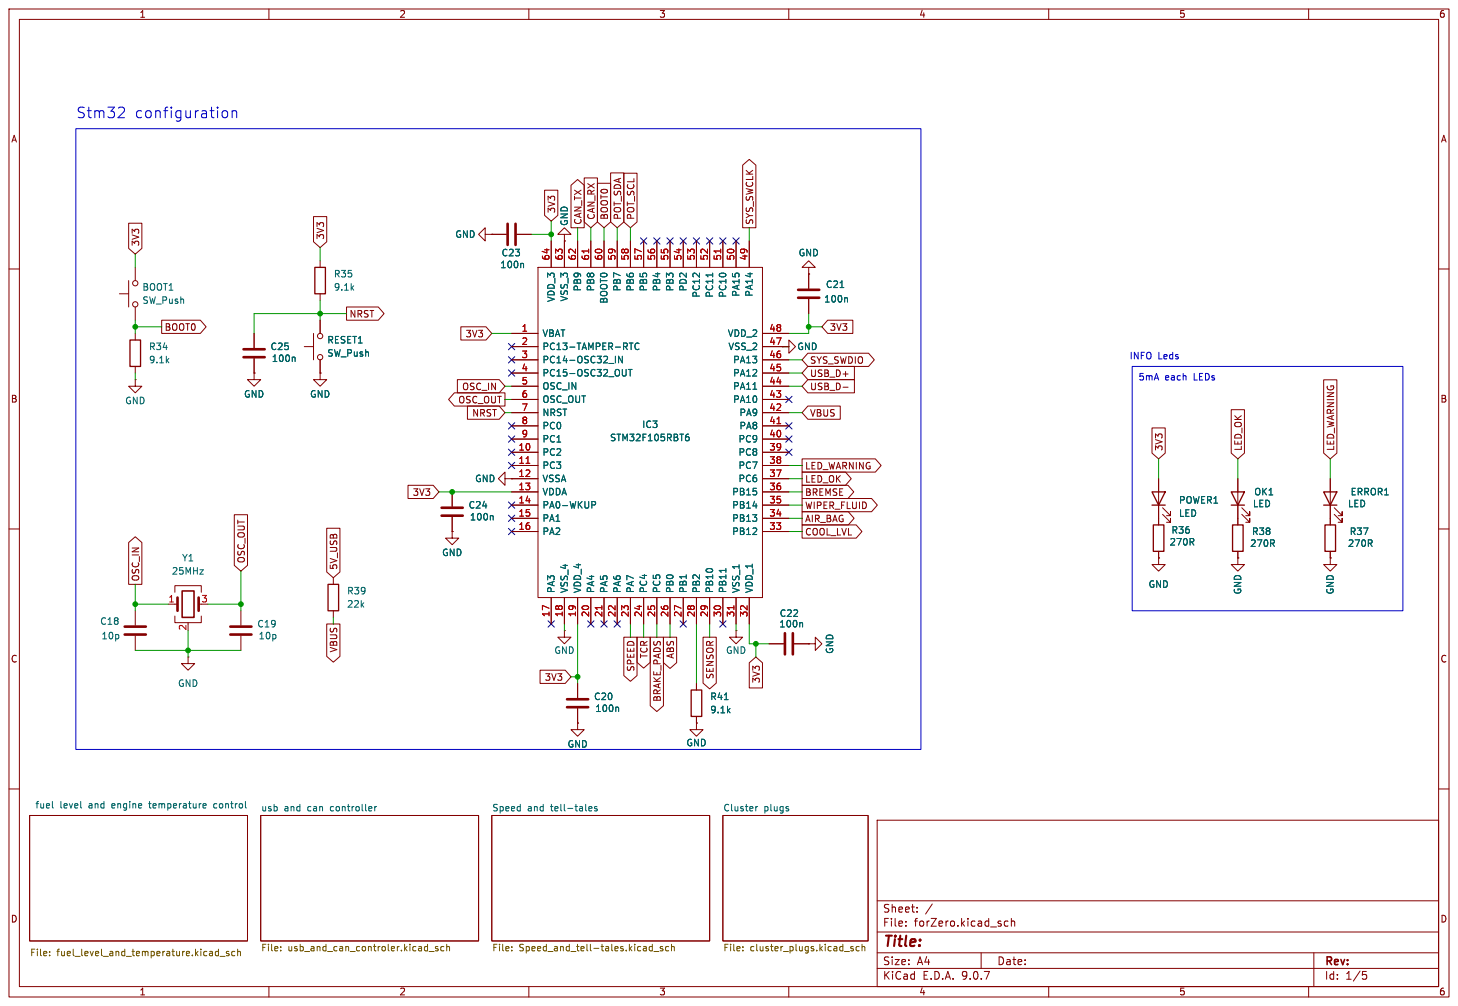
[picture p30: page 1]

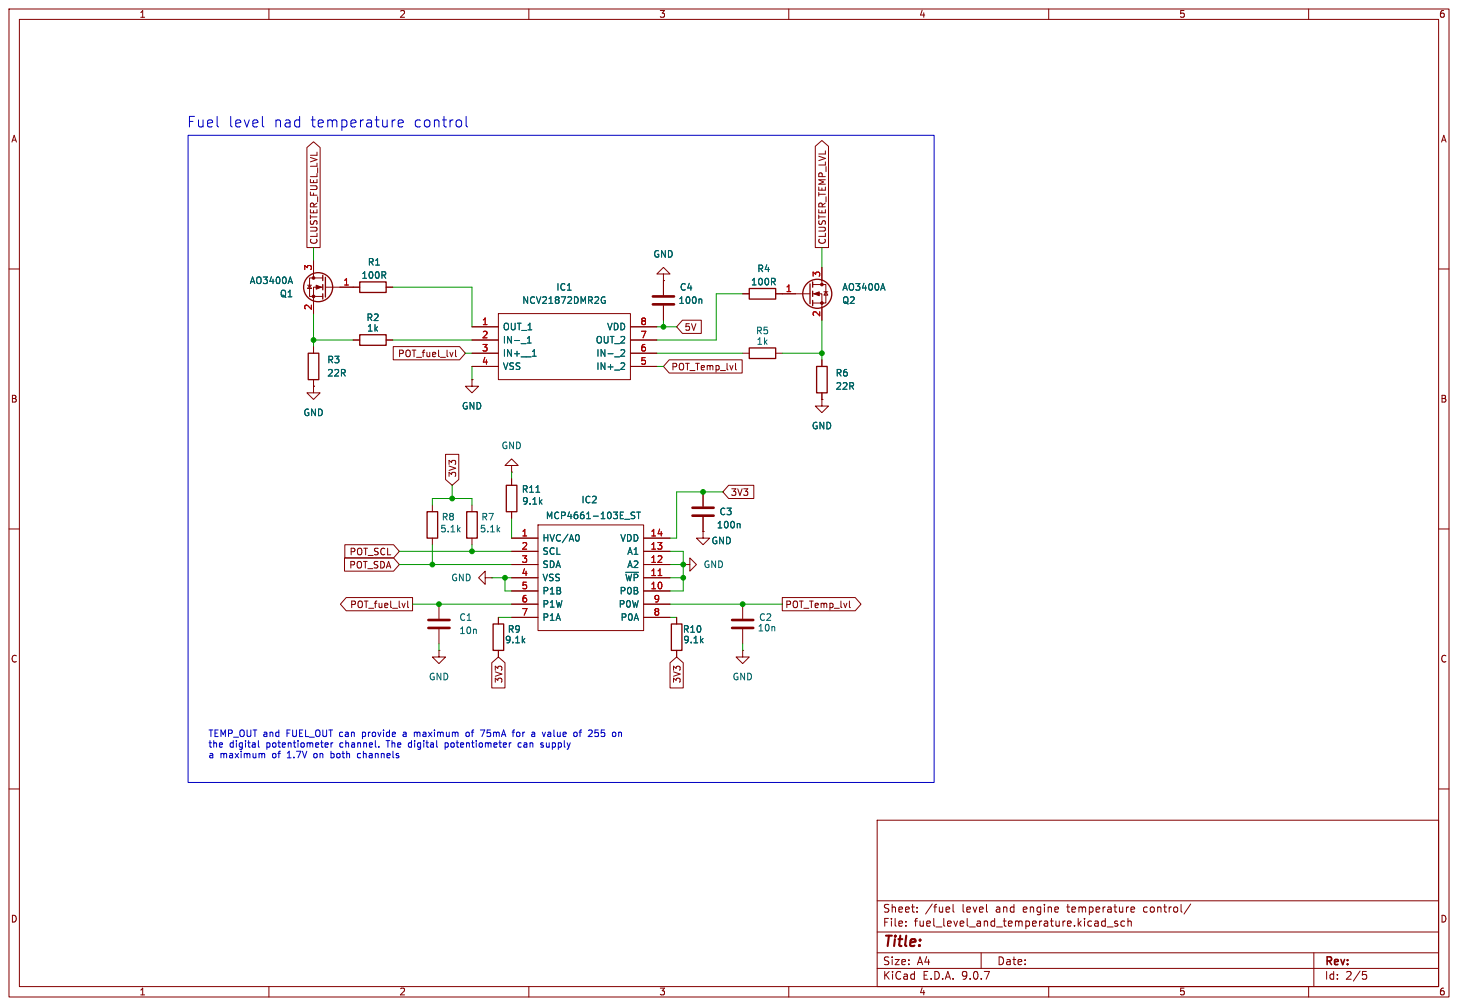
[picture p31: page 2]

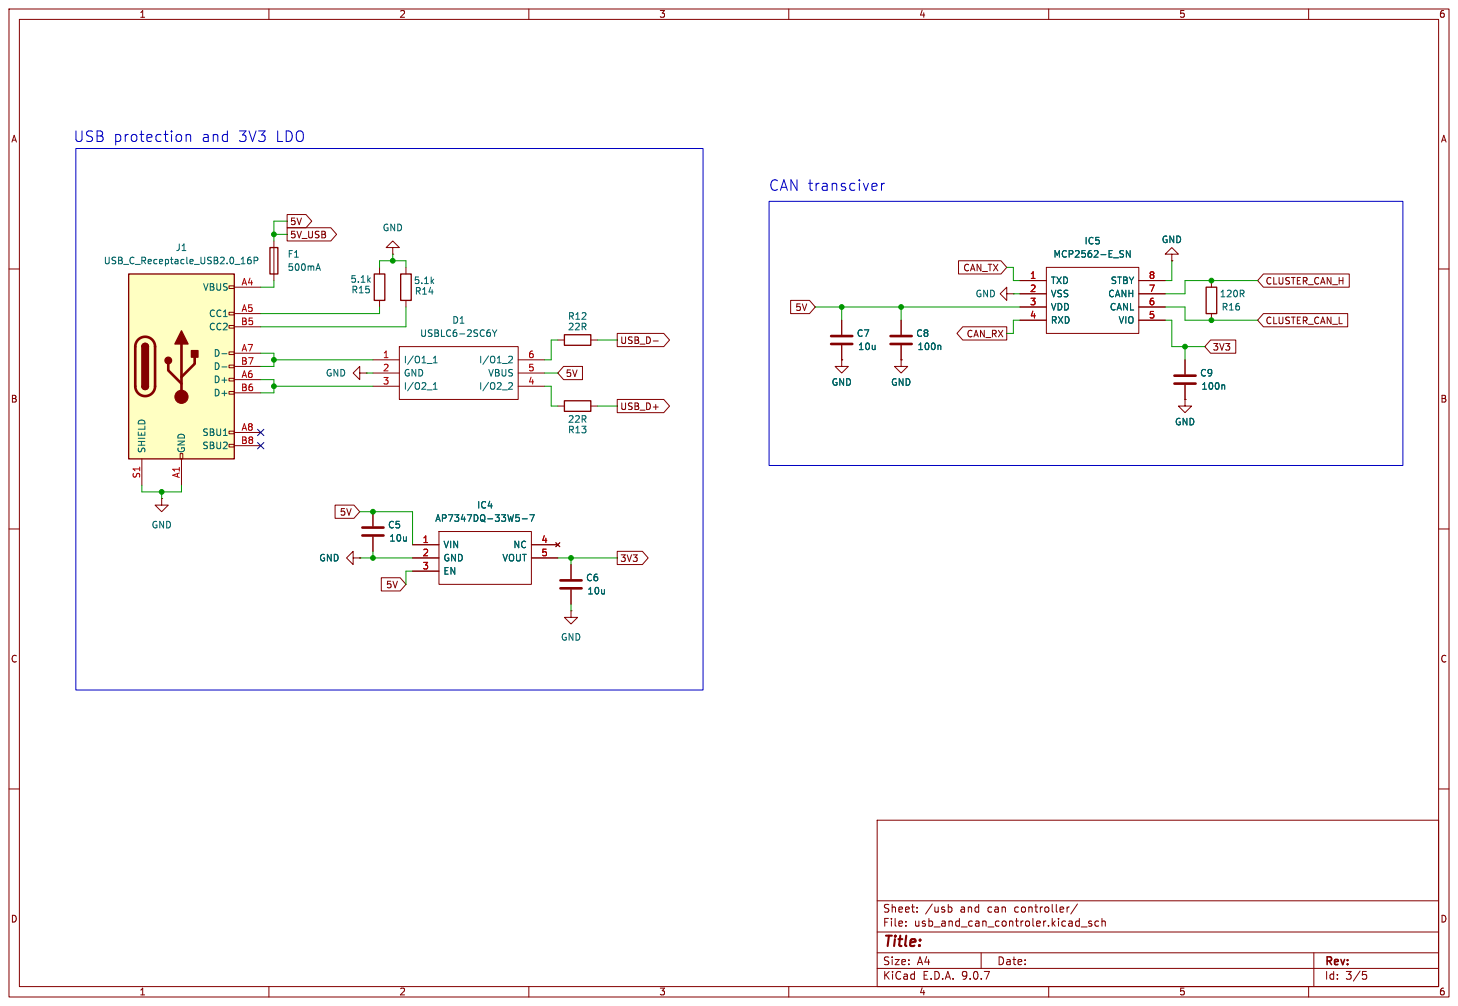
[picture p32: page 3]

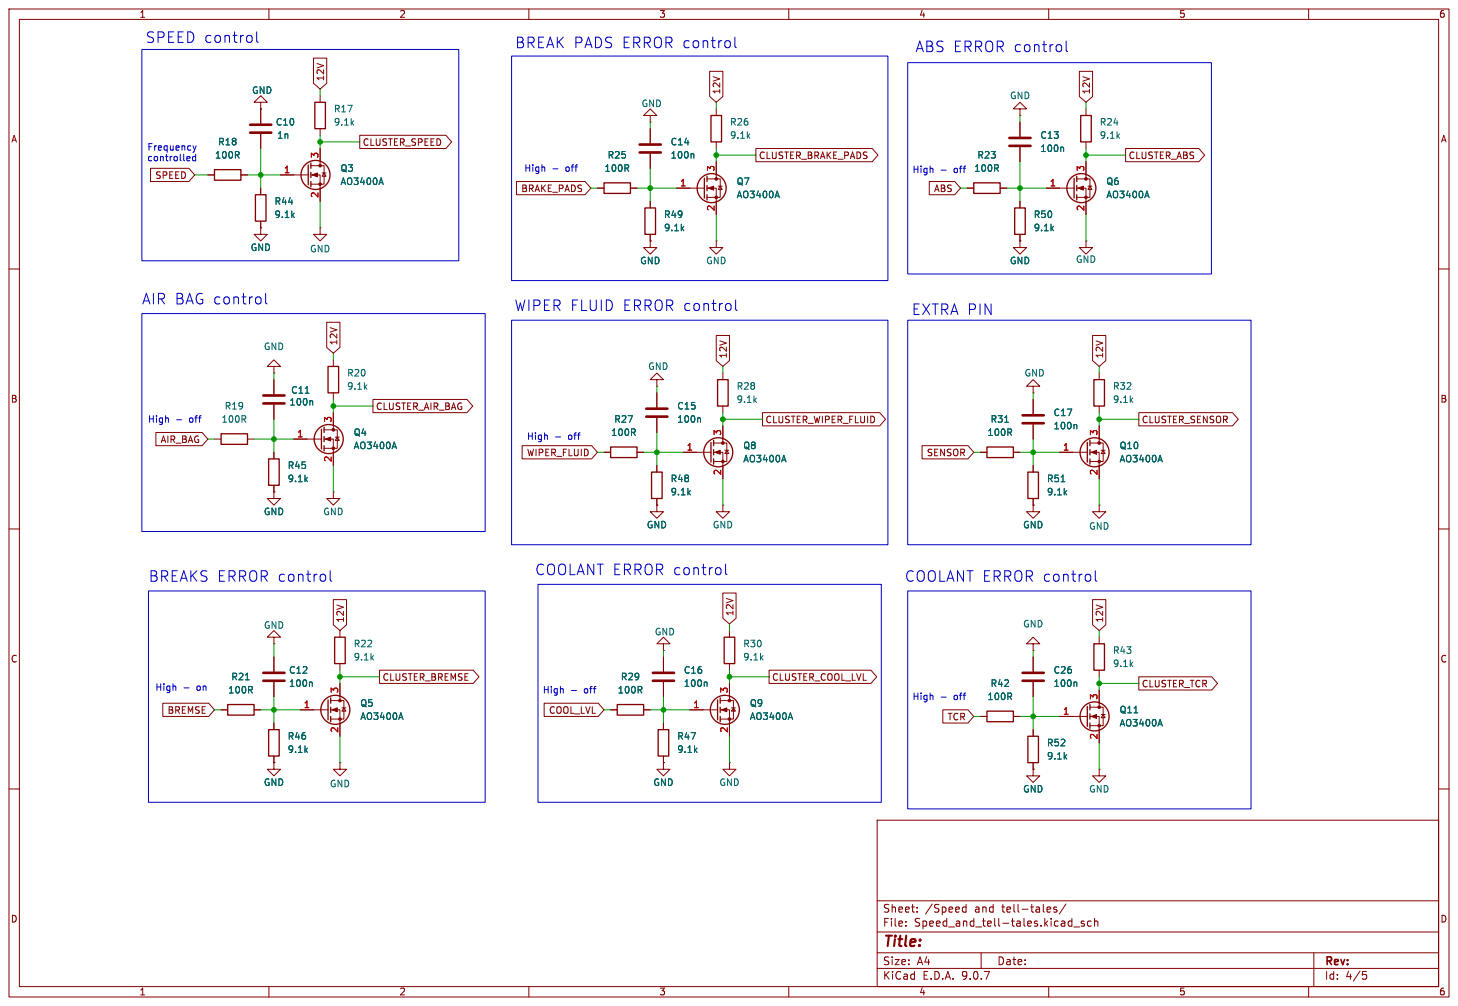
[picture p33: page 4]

Frequency
High - off AIR BAG control
SPEED

COOL_LVL WIPER FLUID ERROR control


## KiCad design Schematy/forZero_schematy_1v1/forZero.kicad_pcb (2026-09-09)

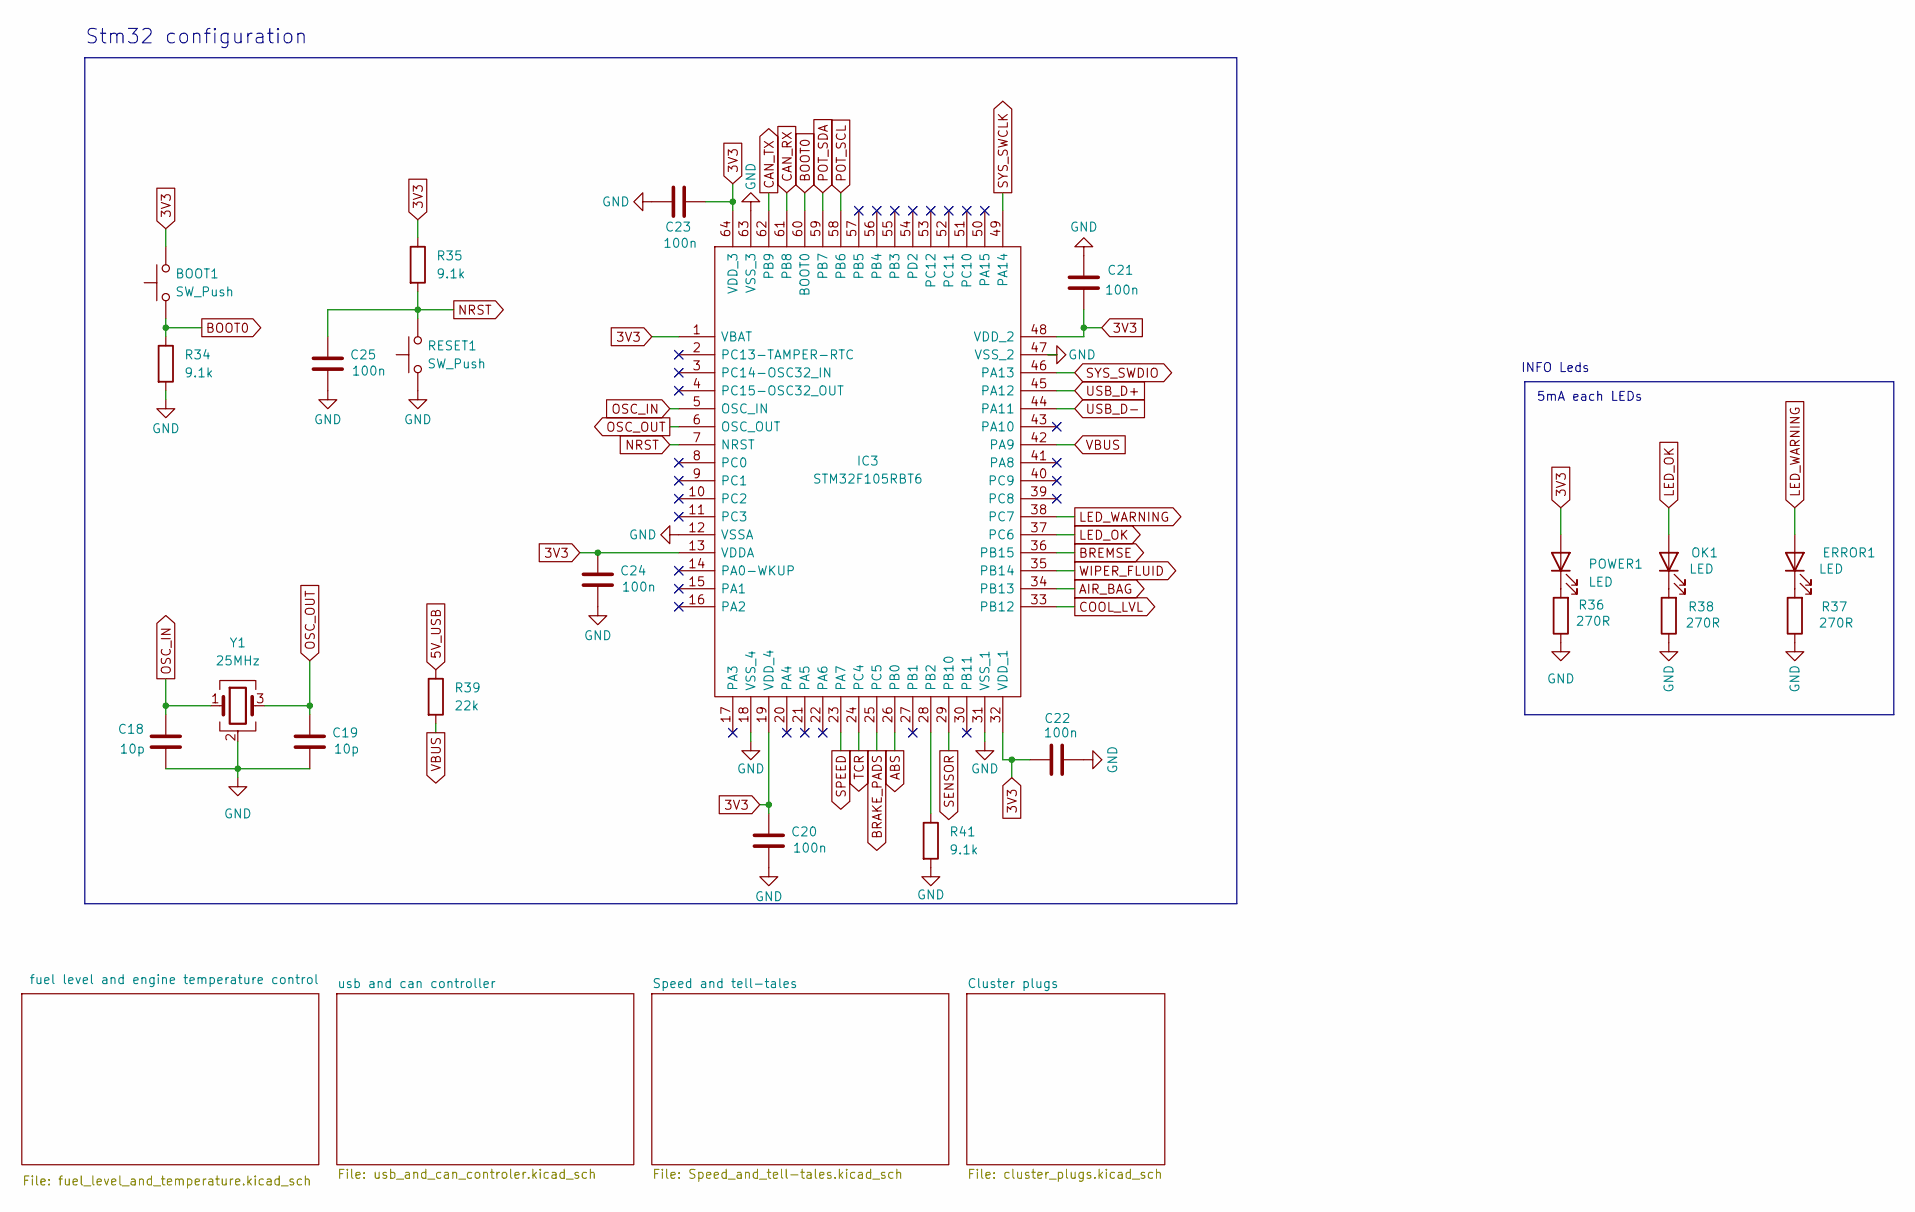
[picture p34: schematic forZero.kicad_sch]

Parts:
BOOT1: SW_Push; SW_SPST_PTS645Sx43SMTR92
C18, C19: 10p; C_0805_2012Metric_Pad1.18x1.45mm_HandSolder
C20, C21, C22, C23, C24, C25: 100n; C_0805_2012Metric_Pad1.18x1.45mm_HandSolder
ERROR1: LED; LED_0603_1608Metric_Pad1.05x0.95mm_HandSolder
IC3: STM32F105RBT6; QFP50P1200X1200X160-64N; Mouser Part Number 511-STM32F105RBT6
OK1: LED; LED_0603_1608Metric_Pad1.05x0.95mm_HandSolder
POWER1: LED; LED_0603_1608Metric_Pad1.05x0.95mm_HandSolder
R34, R35, R41: 9.1k; R_0805_2012Metric_Pad1.20x1.40mm_HandSolder
R36, R37, R38: 270R; R_0805_2012Metric_Pad1.20x1.40mm_HandSolder
R39: 22k; R_0805_2012Metric_Pad1.20x1.40mm_HandSolder
RESET1: SW_Push; SW_SPST_PTS645Sx43SMTR92
Y1: 25MHz; Crystal_SMD_3225-4Pin_3.2x2.5mm

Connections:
3V3: BOOT1.2, C20.1, C21.1, C22.1, C23.1, C24.1, IC3.1 (VBAT), IC3.13 (VDDA), IC3.19 (VDD_4), IC3.32 (VDD_1), IC3.48 (VDD_2), IC3.64 (VDD_3), POWER1.2 (A), R35.1; also elsewhere on the board
5V: R39.1; also elsewhere on the board
ABS: IC3.26 (PB0); also elsewhere on the board
AIR_BAG: IC3.34 (PB13); also elsewhere on the board
BOOT0: BOOT1.1, IC3.60 (BOOT0), R34.1; also elsewhere on the board
BRAKE_PADS: IC3.25 (PC5); also elsewhere on the board
BREMSE: IC3.36 (PB15); also elsewhere on the board
CAN_RX: IC3.61 (PB8); also elsewhere on the board
CAN_TX: IC3.62 (PB9); also elsewhere on the board
COOL_LVL: IC3.33 (PB12); also elsewhere on the board
GND: C18.2, C19.2, C20.2, C21.2, C22.2, C23.2, C24.2, C25.2, IC3.12 (VSSA), IC3.18 (VSS_4), IC3.31 (VSS_1), IC3.47 (VSS_2), IC3.63 (VSS_3), R34.2, R36.1, R37.1, R38.1, R41.2, RESET1.1, Y1.2 (G), Y1.4 (G); also elsewhere on the board
LED_OK: IC3.37 (PC6), OK1.2 (A); also elsewhere on the board
LED_WARNING: ERROR1.2 (A), IC3.38 (PC7); also elsewhere on the board
NRST: C25.1, IC3.7 (NRST), R35.2, RESET1.2; also elsewhere on the board
unnamed 33: ERROR1.1 (K), R37.2; also elsewhere on the board
unnamed: IC3.28 (PB2), R41.1
unnamed 46: OK1.1 (K), R38.2; also elsewhere on the board
unnamed 47: POWER1.1 (K), R36.2; also elsewhere on the board
OSC_IN: C18.1, IC3.5 (OSC_IN), Y1.1
OSC_OUT: C19.1, IC3.6 (OSC_OUT), Y1.3
POT_SCL: IC3.58 (PB6); also elsewhere on the board
POT_SDA: IC3.59 (PB7); also elsewhere on the board
SENSOR: IC3.29 (PB10); also elsewhere on the board
SPEED: IC3.23 (PA7); also elsewhere on the board
SYS_SWCLK: IC3.49 (PA14)
SYS_SWDIO: IC3.46 (PA13)
TCR: IC3.24 (PC4); also elsewhere on the board
USB_D+: IC3.45 (PA12); also elsewhere on the board
USB_D-: IC3.44 (PA11); also elsewhere on the board
VBUS: IC3.42 (PA9), R39.2
WIPER_FLUID: IC3.35 (PB14); also elsewhere on the board

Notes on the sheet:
INFO Leds
5mA each LEDs
Stm32 configuration

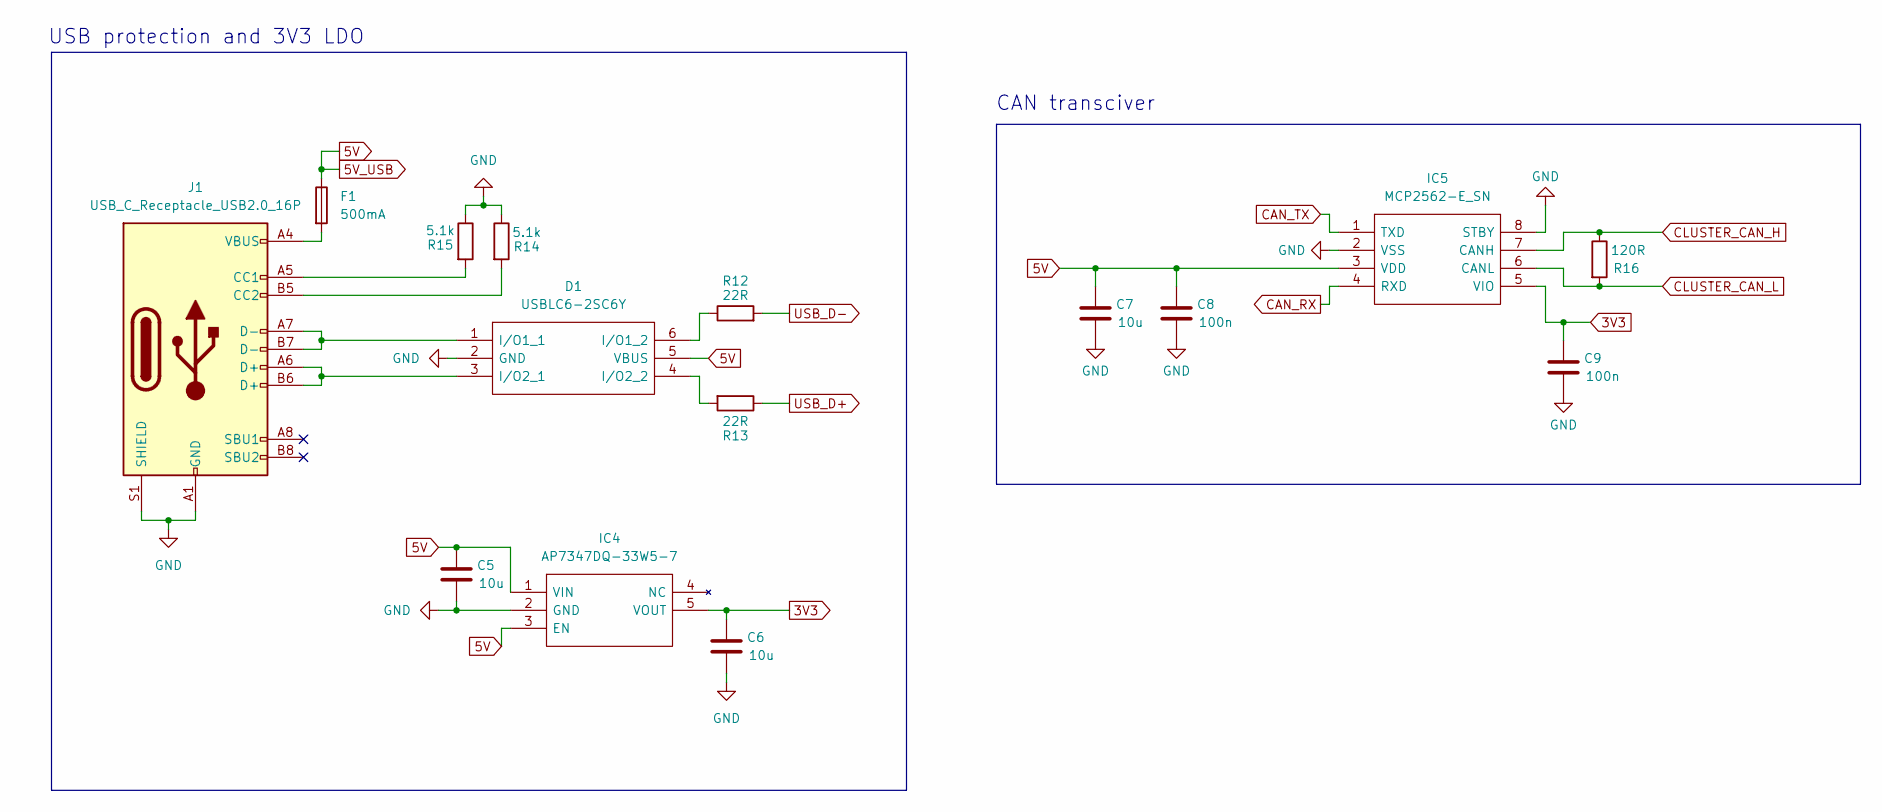
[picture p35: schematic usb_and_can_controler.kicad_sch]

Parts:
C5, C6, C7: 10u; C_0805_2012Metric_Pad1.18x1.45mm_HandSolder
C8, C9: 100n; C_0805_2012Metric_Pad1.18x1.45mm_HandSolder
D1: USBLC6-2SC6Y; SOT95P280X145-6N; Mouser Part Number 511-USBLC6-2SC6Y
F1: 500mA; Fuse_1206_3216Metric_Pad1.42x1.75mm_HandSolder
IC4: AP7347DQ-33W5-7; SOT95P280X145-5N; Mouser Part Number 621-AP7347DQ-33W5-7
IC5: MCP2562-E_SN; SOIC127P600X175-8N; Mouser Part Number 579-MCP2562-E/SN
J1: USB_C_Receptacle_USB2.0_16P; USB_C_Receptacle_GCT_USB4105-xx-A_16P_TopMnt_Horizontal
R12, R13: 22R; R_0805_2012Metric_Pad1.20x1.40mm_HandSolder
R14, R15: 5.1k; R_0805_2012Metric_Pad1.20x1.40mm_HandSolder
R16: 120R; R_0805_2012Metric_Pad1.20x1.40mm_HandSolder

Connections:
3V3: C6.1, C9.1, IC4.5 (VOUT), IC5.5 (VIO); also elsewhere on the board
5V: C5.1, C7.1, C8.1, D1.5 (VBUS), F1.1, IC4.1 (VIN), IC4.3 (EN), IC5.3 (VDD); also elsewhere on the board
CAN_RX: IC5.4 (RXD); also elsewhere on the board
CAN_TX: IC5.1 (TXD); also elsewhere on the board
CLUSTER_CAN_H: IC5.7 (CANH), R16.1; also elsewhere on the board
CLUSTER_CAN_L: IC5.6 (CANL), R16.2; also elsewhere on the board
GND: C5.2, C6.2, C7.2, C8.2, C9.2, D1.2 (GND), IC4.2 (GND), IC5.2 (VSS), IC5.8 (STBY), J1.A1 (GND), J1.A12 (GND), J1.B1 (GND), J1.B12 (GND), J1.S1 (SHIELD), R14.1, R15.1; also elsewhere on the board
unnamed: D1.1 (I/O1_1), J1.A7 (D-), J1.B7 (D-)
unnamed: D1.6 (I/O1_2), R12.1
unnamed: D1.3 (I/O2_1), J1.A6 (D+), J1.B6 (D+)
unnamed: D1.4 (I/O2_2), R13.2
unnamed: F1.2, J1.A4 (VBUS), J1.A9 (VBUS), J1.B4 (VBUS), J1.B9 (VBUS)
unnamed: J1.A5 (CC1), R15.2
unnamed: J1.B5 (CC2), R14.2
USB_D+: R13.1; also elsewhere on the board
USB_D-: R12.2; also elsewhere on the board

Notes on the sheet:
CAN transciver
USB protection and 3V3 LDO

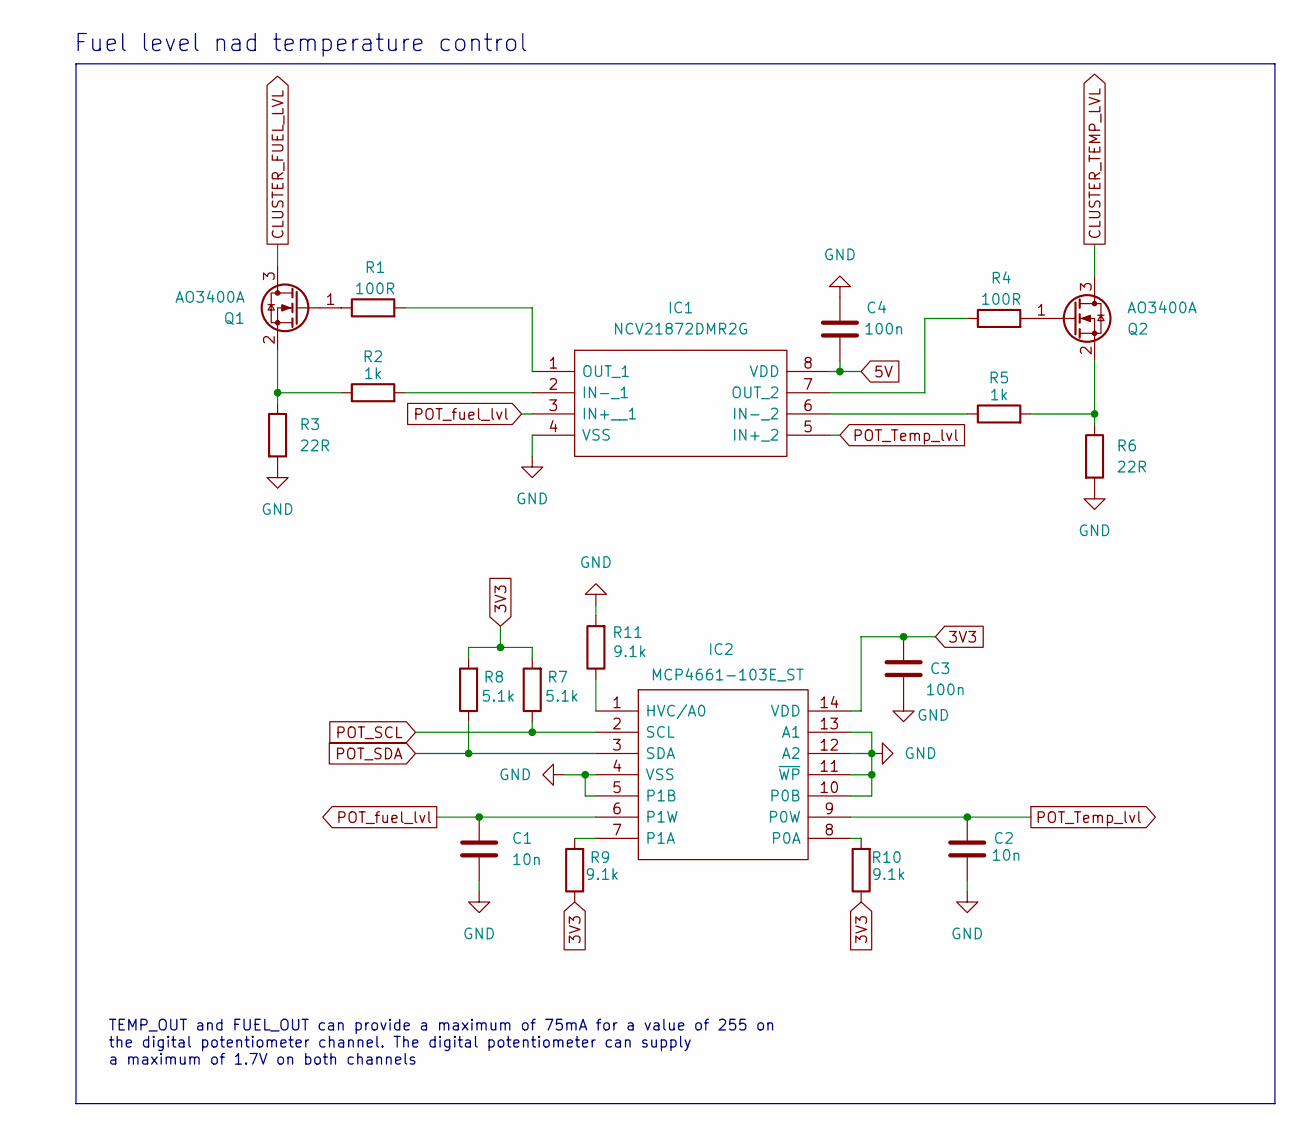
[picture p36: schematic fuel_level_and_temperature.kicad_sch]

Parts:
C1, C2: 10n; C_0805_2012Metric_Pad1.18x1.45mm_HandSolder
C3, C4: 100n; C_0805_2012Metric_Pad1.18x1.45mm_HandSolder
IC1: NCV21872DMR2G; SOP65P490X110-8N; Mouser Part Number 863-NCV21872DMR2G
IC2: MCP4661-103E_ST; SOP65P640X120-14N; Mouser Part Number 579-MCP4661-103E/ST
Q1, Q2: AO3400A; SOT-23
R1, R4: 100R; R_0805_2012Metric_Pad1.20x1.40mm_HandSolder
R2, R5: 1k; R_0805_2012Metric_Pad1.20x1.40mm_HandSolder
R3, R6: 22R; R_1206_3216Metric_Pad1.30x1.75mm_HandSolder
R7, R8: 5.1k; R_0805_2012Metric_Pad1.20x1.40mm_HandSolder
R9, R10, R11: 9.1k; R_0805_2012Metric_Pad1.20x1.40mm_HandSolder

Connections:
3V3: C3.1, IC2.14 (VDD), R7.2, R8.2, R9.1, R10.1; also elsewhere on the board
5V: C4.2, IC1.8 (VDD); also elsewhere on the board
CLUSTER_FUEL_LVL: Q1.3 (D); also elsewhere on the board
CLUSTER_TEMP_LVL: Q2.3 (D); also elsewhere on the board
GND: C1.2, C2.2, C3.2, C4.1, IC1.4 (VSS), IC2.4 (VSS), IC2.5 (P1B), IC2.10 (P0B), IC2.11 (~WP), IC2.12 (A2), IC2.13 (A1), R3.2, R6.2, R11.2; also elsewhere on the board
unnamed: IC1.2 (IN-_1), R2.2
unnamed: IC1.6 (IN-_2), R5.1
unnamed: IC1.1 (OUT_1), R1.2
unnamed: IC1.7 (OUT_2), R4.1
unnamed: IC2.1 (HVC/A0), R11.1
unnamed: IC2.8 (P0A), R10.2
unnamed: IC2.7 (P1A), R9.2
unnamed: Q1.1 (G), R1.1
unnamed: Q1.2 (S), R2.1, R3.1
unnamed: Q2.1 (G), R4.2
unnamed: Q2.2 (S), R5.2, R6.1
POT_SCL: IC2.2 (SCL), R7.1; also elsewhere on the board
POT_SDA: IC2.3 (SDA), R8.1; also elsewhere on the board
POT_Temp_lvl: C2.1, IC1.5 (IN+_2), IC2.9 (P0W)
POT_fuel_lvl: C1.1, IC1.3 (IN+__1), IC2.6 (P1W)

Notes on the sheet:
TEMP_OUT and FUEL_OUT can provide a maximum of 75mA for a value of 255 on the digital potentiometer channel. The digital potentiometer can supply a maximum of 1.7V on both channels
Fuel level nad temperature control

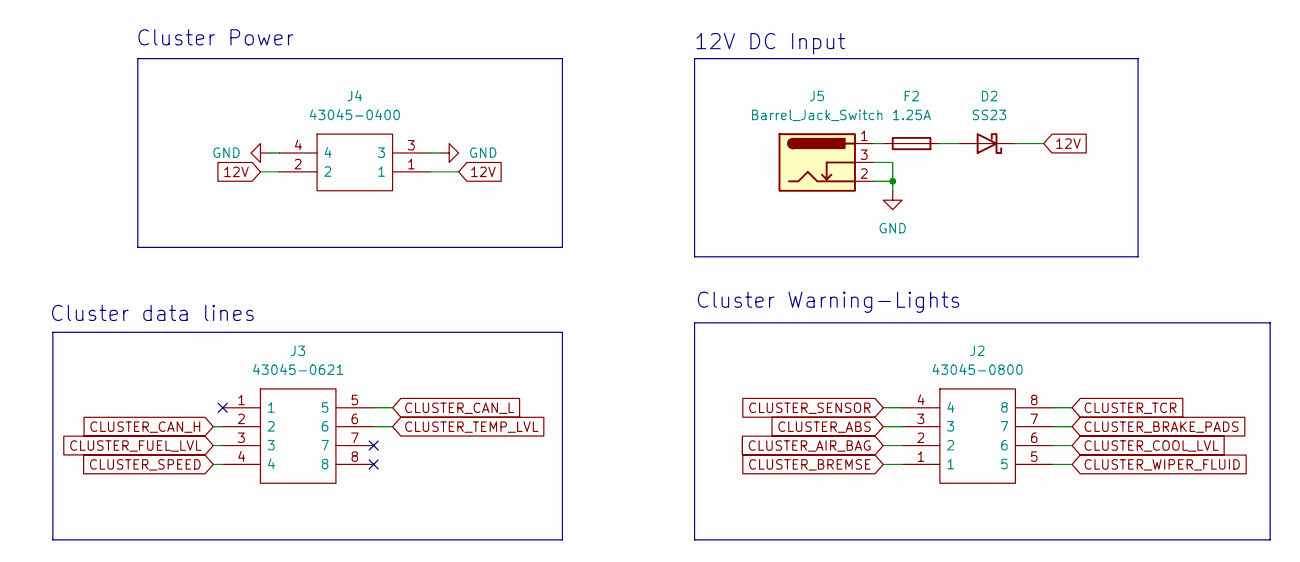
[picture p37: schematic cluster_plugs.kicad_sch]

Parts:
D2: SS23; D_SMA
F2: 1.25A; Fuse_1812_4532Metric_Pad1.30x3.40mm_HandSolder
J2: 43045-0800; 43045-08_00,01,02,10_; Mouser Part Number 538-43045-0800
J3: 43045-0621; 43045-06YY_212223; Mouser Part Number 538-43045-0621
J4: 43045-0400; 43045-04_00,01,02,10_; Mouser Part Number 538-43045-0400
J5: Barrel_Jack_Switch; BarrelJack_GCT_DCJ200-10-A_Horizontal

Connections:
12V: D2.1 (K), J4.1, J4.2; also elsewhere on the board
CLUSTER_ABS: J2.3; also elsewhere on the board
CLUSTER_AIR_BAG: J2.2; also elsewhere on the board
CLUSTER_BRAKE_PADS: J2.7; also elsewhere on the board
CLUSTER_BREMSE: J2.1; also elsewhere on the board
CLUSTER_CAN_H: J3.2; also elsewhere on the board
CLUSTER_CAN_L: J3.5; also elsewhere on the board
CLUSTER_COOL_LVL: J2.6; also elsewhere on the board
CLUSTER_FUEL_LVL: J3.3; also elsewhere on the board
CLUSTER_SENSOR: J2.4; also elsewhere on the board
CLUSTER_SPEED: J3.4; also elsewhere on the board
CLUSTER_TCR: J2.8; also elsewhere on the board
CLUSTER_TEMP_LVL: J3.6; also elsewhere on the board
CLUSTER_WIPER_FLUID: J2.5; also elsewhere on the board
GND: J4.3, J4.4, J5.2, J5.3; also elsewhere on the board
unnamed: D2.2 (A), F2.2
unnamed: F2.1, J5.1

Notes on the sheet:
Cluster data lines
Cluster Warning-Lights
Cluster Power
12V DC Input

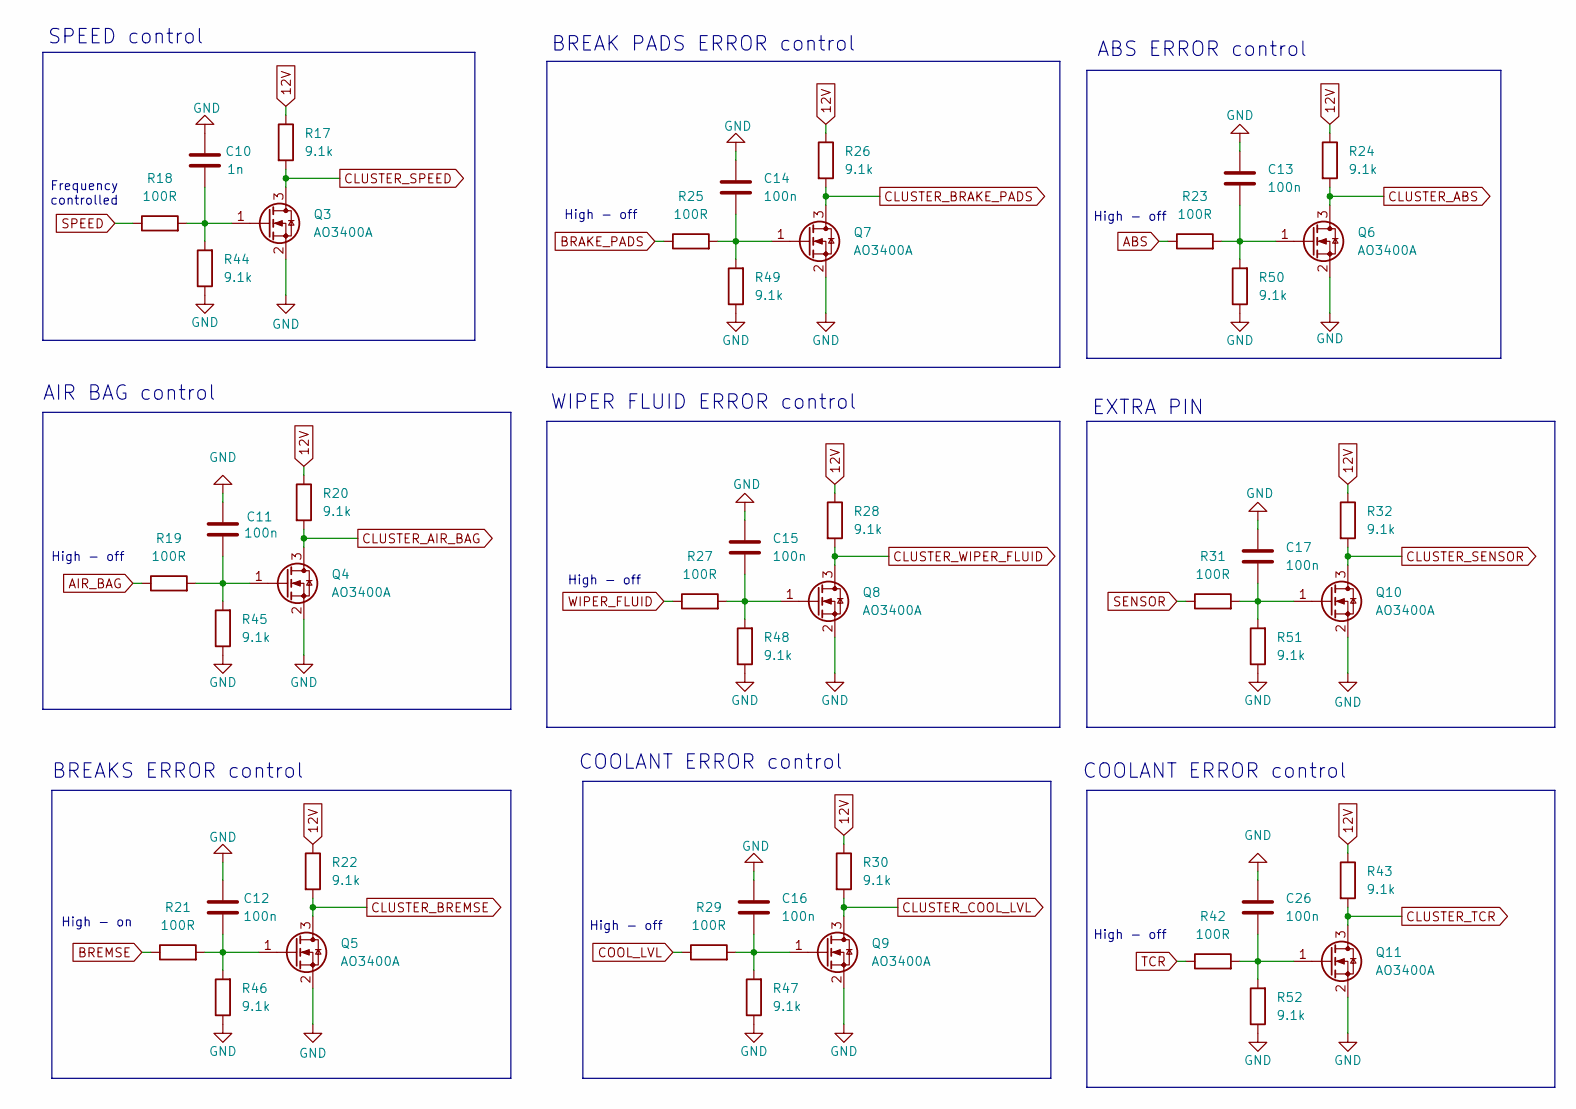
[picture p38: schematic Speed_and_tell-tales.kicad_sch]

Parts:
C10: 1n; C_0805_2012Metric_Pad1.18x1.45mm_HandSolder
C11, C12, C13, C14, C15, C16, C17, C26: 100n; C_0805_2012Metric_Pad1.18x1.45mm_HandSolder
Q3, Q4, Q5, Q6, Q7, Q8, Q9, Q10, Q11: AO3400A; SOT-23
R17, R20, R22, R24, R26, R28, R30, R32, R43, R44, R45, R46, R47, R48, R49, R50, R51, R52: 9.1k; R_0805_2012Metric_Pad1.20x1.40mm_HandSolder
R18, R19, R21, R23, R25, R27, R29, R31, R42: 100R; R_0805_2012Metric_Pad1.20x1.40mm_HandSolder

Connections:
12V: R17.1, R20.1, R22.1, R24.1, R26.1, R28.1, R30.1, R32.1, R43.1; also elsewhere on the board
ABS: R23.1; also elsewhere on the board
AIR_BAG: R19.1; also elsewhere on the board
BRAKE_PADS: R25.1; also elsewhere on the board
BREMSE: R21.1; also elsewhere on the board
CLUSTER_ABS: Q6.3 (D), R24.2; also elsewhere on the board
CLUSTER_AIR_BAG: Q4.3 (D), R20.2; also elsewhere on the board
CLUSTER_BRAKE_PADS: Q7.3 (D), R26.2; also elsewhere on the board
CLUSTER_BREMSE: Q5.3 (D), R22.2; also elsewhere on the board
CLUSTER_COOL_LVL: Q9.3 (D), R30.2; also elsewhere on the board
CLUSTER_SENSOR: Q10.3 (D), R32.2; also elsewhere on the board
CLUSTER_SPEED: Q3.3 (D), R17.2; also elsewhere on the board
CLUSTER_TCR: Q11.3 (D), R43.2; also elsewhere on the board
CLUSTER_WIPER_FLUID: Q8.3 (D), R28.2; also elsewhere on the board
COOL_LVL: R29.1; also elsewhere on the board
GND: C10.1, C11.2, C12.1, C13.1, C14.1, C15.1, C16.1, C17.1, C26.1, Q3.2 (S), Q4.2 (S), Q5.2 (S), Q6.2 (S), Q7.2 (S), Q8.2 (S), Q9.2 (S), Q10.2 (S), Q11.2 (S), R44.1, R45.1, R46.1, R47.1, R48.1, R49.1, R50.1, R51.1, R52.1; also elsewhere on the board
unnamed: C10.2, Q3.1 (G), R18.2, R44.2
unnamed: C11.1, Q4.1 (G), R19.2, R45.2
unnamed: C12.2, Q5.1 (G), R21.2, R46.2
unnamed: C13.2, Q6.1 (G), R23.2, R50.2
unnamed: C14.2, Q7.1 (G), R25.2, R49.2
unnamed: C15.2, Q8.1 (G), R27.2, R48.2
unnamed: C16.2, Q9.1 (G), R29.2, R47.2
unnamed: C17.2, Q10.1 (G), R31.2, R51.2
unnamed: C26.2, Q11.1 (G), R42.2, R52.2
SENSOR: R31.1; also elsewhere on the board
SPEED: R18.1; also elsewhere on the board
TCR: R42.1; also elsewhere on the board
WIPER_FLUID: R27.1; also elsewhere on the board

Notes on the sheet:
ABS ERROR control
COOLANT ERROR control
BREAK PADS ERROR control
High - off
BREAKS ERROR control
EXTRA PIN
AIR BAG control
SPEED control
Frequency controlled
WIPER FLUID ERROR control
High - on

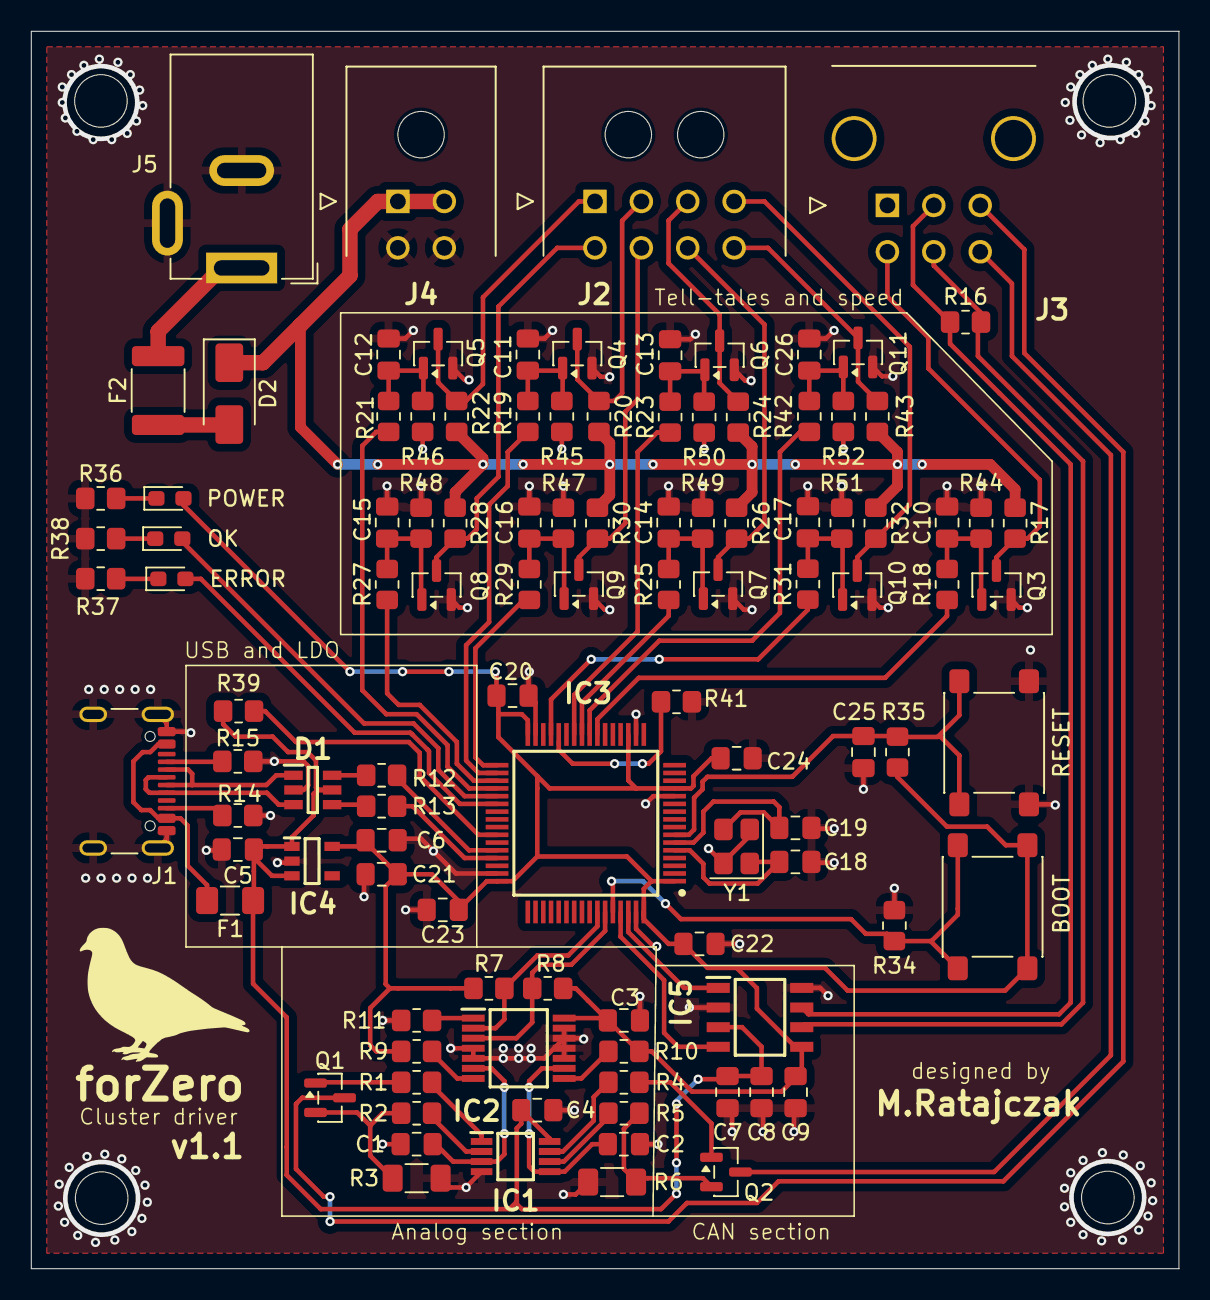
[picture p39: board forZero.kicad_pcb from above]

Board: 2 copper layers, 74.2 x 80.0 mm, 107 parts (0 on the bottom side), 74 nets.

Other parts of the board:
BOOT: SW_Push; SW_SPST_PTS645Sx43SMTR92
ERROR: LED; LED_0603_1608Metric_Pad1.05x0.95mm_HandSolder
OK: LED; LED_0603_1608Metric_Pad1.05x0.95mm_HandSolder
POWER: LED; LED_0603_1608Metric_Pad1.05x0.95mm_HandSolder
RESET: SW_Push; SW_SPST_PTS645Sx43SMTR92

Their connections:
3V3: BOOT.2, POWER.2 (A); also elsewhere on the board
BOOT0: BOOT.1; also elsewhere on the board
GND: RESET.1; also elsewhere on the board
LED_OK: OK.2 (A); also elsewhere on the board
LED_WARNING: ERROR.2 (A); also elsewhere on the board
NRST: RESET.2; also elsewhere on the board
unnamed 33: ERROR.1 (K); also elsewhere on the board
unnamed 46: OK.1 (K); also elsewhere on the board
unnamed 47: POWER.1 (K); also elsewhere on the board

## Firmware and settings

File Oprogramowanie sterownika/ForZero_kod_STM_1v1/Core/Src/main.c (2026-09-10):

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
/* Includes ------------------------------------------------------------------*/
#include "main.h"
#include "usb_device.h"

/* USER CODE BEGIN Includes */
#include <stdbool.h>
#include "usbd_cdc_if.h"
#include "CAN_motor.h"
#include "speed.h"
#include "mcp4661.h"
#include "tell_tales.h"
#include "fuel_and_temp.h"
#include "cluster.h"
/* USER CODE END Includes */

CAN_HandleTypeDef hcan1;

I2C_HandleTypeDef hi2c1;

TIM_HandleTypeDef htim3;

void SystemClock_Config(void);
static void MX_GPIO_Init(void);
static void MX_CAN1_Init(void);
static void MX_TIM3_Init(void);
static void MX_I2C1_Init(void);
/**
  * @brief  The application entry point.
  * @retval int
  */
int main(void)
{

  /* USER CODE BEGIN 1 */
  Cluster local_cluster = {0};
  uint32_t last_send_time_20ms = 0;
  uint32_t last_send_time_2000ms = 0;
  uint32_t last_send_time_5000ms = 0;
  /* USER CODE END 1 */

  /* MCU Configuration--------------------------------------------------------*/

  /* Reset of all peripherals, Initializes the Flash interface and the Systick. */
  HAL_Init();

  /* Configure the system clock */
  SystemClock_Config();

  /* Initialize all configured peripherals */
  MX_GPIO_Init();
  MX_CAN1_Init();
  MX_TIM3_Init();
  MX_I2C1_Init();
  MX_USB_DEVICE_Init();
  /* USER CODE BEGIN 2 */
  Speed_Init();

  // Uruchomienie magistrali CAN
  if (HAL_CAN_Start(&hcan1) != HAL_OK){
     Error_Handler();
  }

  // Kontrolki
  TellTales_Init();
 // Pin_Write(&LED_WARNING, GPIO_PIN_SET);

  start_cluster_test();
  /* USER CODE END 2 */

  /* Infinite loop */
  /* USER CODE BEGIN WHILE */
  static uint16_t last_send_speed = 0xFFFF; // Wymuszenie wysłania pierwszy raz Send_Speed()
  static uint8_t last_send_indicators = 0xFF;
  bool is_new_fuel_data = false;
  static bool frame_processed = true;
  static uint16_t curent_frame_number = 0x0000;

  while (1)
  {
    /* USER CODE END WHILE */

    /* USER CODE BEGIN 3 */
	  process_cluster_test();

	  if(is_cluster_test_active()){
		  last_send_speed = 0x0000;
		  last_send_indicators = 0x10;
	  }

	  // Odbiór telemetri z USB i tworzenie lokalnej kopii
	  if(is_new_usb_packet == true){ // volatile
		  // 1. Kopiowanie najnowszych dostępnych danych (sekcja krytyczna)
		  __disable_irq();
		  local_cluster = g_cluster;
		  is_new_usb_packet = false;
		  is_new_fuel_data = true;

		  // Informajce dla ACK EXEC
		  frame_processed = false;
		  curent_frame_number = local_cluster.last_pkt_num;
		  __enable_irq();

	  }

	  if(!is_cluster_test_active()){

		  // Wysyłanie prędkości i stanu kontrolek w sposob ciągły
		  if(local_cluster.speed != last_send_speed){
			  Send_Speed(local_cluster.speed);
			  last_send_speed = local_cluster.speed;
		  }

		  if(local_cluster.indicators != last_send_indicators){
			  Send_TellTales(&local_cluster.indicators);
			  last_send_indicators = local_cluster.indicators;
		  }

		  // Wysyłanie RPM co 20ms
		  if (HAL_GetTick() - last_send_time_20ms >= 20){
				  last_send_time_20ms = HAL_GetTick();

				  Send_RPM(local_cluster.rpm);
		  }

		  // Wysyłanie Poziomu paliwa co 5 sekund
		  if(HAL_GetTick() - last_send_time_5000ms >= 5000 && is_new_fuel_data == true){
			  last_send_time_5000ms = HAL_GetTick();

				  Send_Fuel_lvl(local_cluster.fuel_level);
				  is_new_fuel_data = false;
		  }

		  // Wysyłanie temperatury silnika co 2 sekundy
		  if(HAL_GetTick() - last_send_time_2000ms >= 2000){
			  last_send_time_2000ms = HAL_GetTick();

				  Send_Engine_Temperature(local_cluster.engine_temp);
		  }

	  }

	  // Timeout USB
	  __disable_irq();
	  if (rx_idx > 0 && (HAL_GetTick() - last_time_usb_rx >= 50)) {
	      rx_idx = 0; // Odrzucamy niekompletną paczkę
	  }
	  __enable_irq();

	  // Timeout USB - Wygaszenie zegarów
	  __disable_irq();
	  bool telemetry_expired = (HAL_GetTick() - last_time_correct_usb_rx >= 500);
	  __enable_irq();

	  if(telemetry_expired){
		  local_cluster.speed = 0;
		  local_cluster.rpm = 0;
		  local_cluster.engine_temp = 0;
		  local_cluster.indicators = 0x10;
	  }


	  // Wysłanie ACK EXEC
	  if(frame_processed == false){
		  if(CDC_Transmit_FS((uint8_t*)&curent_frame_number,2) == USBD_OK){
			  frame_processed = true;
		  }
	  }

  }
  /* USER CODE END 3 */
}

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


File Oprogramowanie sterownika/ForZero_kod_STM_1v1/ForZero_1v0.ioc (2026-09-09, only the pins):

Mcu.UserName=STM32F105RBTx
PA11.Signal=USB_OTG_FS_DM
PA12.Signal=USB_OTG_FS_DP
PA7.Signal=S_TIM3_CH2
PB0.Signal=GPIO_Output
PB10.Signal=GPIO_Output
PB12.Signal=GPIO_Output
PB13.Signal=GPIO_Output
PB14.Signal=GPIO_Output
PB15.Signal=GPIO_Output
PB6.Signal=I2C1_SCL
PB7.Signal=I2C1_SDA
PB8.Signal=CAN1_RX
PB9.Signal=CAN1_TX
PC4.Signal=GPIO_Output
PC5.Signal=GPIO_Output
PC6.Signal=GPIO_Output
PC7.Signal=GPIO_Output
PD0-OSC_IN.Signal=RCC_OSC_IN
PD1-OSC_OUT.Signal=RCC_OSC_OUT

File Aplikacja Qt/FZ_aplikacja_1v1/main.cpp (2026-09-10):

#include <QGuiApplication>
#include <QQmlApplicationEngine>
#include <QQmlContext>
#include <QThread>

#include "audi_a4_b6_cluster.h"
#include "cluster_settings.h"
#include "utils.h"

int main(int argc, char *argv[])
{
    QGuiApplication app(argc, argv);

    // Rejestracja typu dla sygnału
    qRegisterMetaType<Cluster_m>("Cluster_m");
    qRegisterMetaType<UsbStatistics>("UsbStatistics");
    qRegisterMetaType<ClusterSettings_m>("ClusterSettings_m");

    AudiA4B6Cluster audiCluster;

    QQmlApplicationEngine engine;

    // Udostępniamy odbiornik do QML przed załadowaniem interfejsu
    engine.rootContext()->setContextProperty("audiCluster", &audiCluster);

    QObject::connect(
        &engine,
        &QQmlApplicationEngine::objectCreationFailed,
        &app,
        []() { QCoreApplication::exit(-1); },
        Qt::QueuedConnection);

    engine.loadFromModule("Fz_udp", "Main");



    return app.exec();
}

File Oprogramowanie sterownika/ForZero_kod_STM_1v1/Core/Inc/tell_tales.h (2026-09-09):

/*
 * tell_tales.h
 *
 *  Created on: 10 sie 2026
 *      Author: rataj
 */

#ifndef INC_TELL_TALES_H_
#define INC_TELL_TALES_H_

#include "main.h"
#include <stdbool.h>
typedef struct {
	GPIO_TypeDef *port;
	uint16_t pin;
} GPIO_Pin_t;

// LEDs built-in driver
extern const GPIO_Pin_t LED_OK;
extern const GPIO_Pin_t LED_WARNING;

// Cluster Tell-Tales
extern const GPIO_Pin_t TCR;
extern const GPIO_Pin_t BRAKE_PADS;
extern const GPIO_Pin_t ABS;
extern const GPIO_Pin_t SENSOR;
extern const GPIO_Pin_t COOL_LVL;
extern const GPIO_Pin_t AIRBAG;
extern const GPIO_Pin_t WIPER_FLUID;
extern const GPIO_Pin_t BRAKES;

typedef enum{
	ABS_BIT = (1 << 0), 		// 0-bit
	TCR_BIT = (1 << 1), 		// 1-bit
	BRAKES_BIT = (1 << 2),		// 2-bit
	BRAKE_PADS_BIT = (1 << 3), 	// 3-bit
	SENSOR_BIT = (1 << 4),		// 4-bit
	COOL_LVL_BIT = (1 << 5), 	// 5-bit
	WIPER_FLUID_BIT = (1 << 6), // 6-bit
	AIRBAG_BIT = (1 << 7)		// 7-bit
}IndicatorsBit_t;

typedef struct{
	const GPIO_Pin_t *pin;
	IndicatorsBit_t mask;
	bool inverted;
} TellTale_Config_t;

void Pin_Write(const GPIO_Pin_t *gpio, GPIO_PinState state);

void Send_TellTales(const uint8_t *indicators);

void TellTales_Init();

#endif /* INC_TELL_TALES_H_ */

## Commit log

2026-06-28 Pierwsze testy UART
2026-06-30 Dodano symulacje obwodu paliwa
    [Kosztorys.xlsx]
2026-07-03 Aktualizacja kosztorysu
    [Kosztorys.xlsx]
2026-07-07 Wstępny schemat oraz projekt PCB
    [Kosztorys.xlsx, Speed_and_tell-tales.kicad_sch, cluster_plugs.kicad_sch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]
2026-07-10 Wprowadzenie poprawek PCB
    [Speed_and_tell-tales.kicad_sch, cluster_plugs.kicad_sch, forZero.kicad_pcb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]
2026-07-10 Wykonano finalne PCB dla forZero_1v0
    [Kosztorys.xlsx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]
2026-09-09 Wersja 1v0
    [Kosztorys.xlsx, Speed_and_tell-tales.kicad_sch, cluster_plugs.kicad_sch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]
2026-09-10 Wersja 1.1 oprogramowania i schematów
    [Kosztorys.xlsx]
2026-09-11 Uzupełnienie README i fix aplikacji w wersji 1.1
    [cluster.h, engine_temp_sim.h]

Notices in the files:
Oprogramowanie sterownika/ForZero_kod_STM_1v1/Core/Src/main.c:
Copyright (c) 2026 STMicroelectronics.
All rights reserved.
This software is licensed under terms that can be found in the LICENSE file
